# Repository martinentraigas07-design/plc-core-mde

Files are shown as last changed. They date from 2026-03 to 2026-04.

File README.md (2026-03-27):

# plc-core-mde
Open modular PLC based on ESP32 with web interface, IEC61131 FBD programming, RS485 Modbus expansion and cloud simulator support
# PLC-CORE-MDE

PLC-CORE-MDE is an open, modular and scalable programmable logic controller (PLC) based on ESP32, designed for education, automation, industrial control and experimental development.

The project is focused on creating a flexible, low-cost and high-performance control platform that can be expanded using external modules connected through RS485 Modbus communication.

The system includes an embedded web server that allows configuration, monitoring and programming directly from a web browser without the need for additional software.

Main features:

- ESP32 based core module
- Embedded web server
- Graphical programming using FBD (Function Block Diagram)
- IEC 61131 inspired runtime
- RS485 Modbus expansion modules
- Automatic module detection
- Digital and analog IO support
- PWM outputs
- Timers, counters and memory blocks
- Modular hardware for DIN rail mounting
- Educational oriented design
- Open architecture
- Cloud simulator support (future)
- Virtual PLC for training and testing

Architecture:

CORE module:
- Processing
- Web server
- Runtime
- Communication

Expansion modules:
- Digital inputs
- Digital outputs
- Analog inputs
- Analog outputs
- Mixed IO
- Modbus devices

Future features:

- Cloud PLC simulator
- USB communication mode
- Modbus remote mode
- Gateway mode
- Ethernet / TCP mode
- Hybrid simulation + real PLC

This project is intended for:

- Technical education
- Industrial automation learning
- Experimental development
- Custom control systems
- Low-cost PLC applications

Author: Martin Entraigas
Project: PLC-CORE-MDE

## License

PLC-CORE-MDE License v1.0

Copyright (c) 2026 Martín Entraigas / PLC-CORE-MDE, Argentina

Educational use allowed.
Commercial use requires authorization.

See LICENSE file for full terms.

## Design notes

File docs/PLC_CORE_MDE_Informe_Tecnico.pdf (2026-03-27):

## ESCUELA SECUNDARIA TÉCNICA PROVINCIAL N° 748

### Tecnicatura en Electrónica

INFORME TÉCNICO-DIDÁCTICO

# PLC-CORE-MDE

### Controlador Lógico Programable de Diseño Propio basado en ESP32

Materia: Montajes Electrónicos y Automatismos 5° Año — Tecnicatura en Electrónica Profesor: Martín Entraigas Ciclo Lectivo 2026

Versión del Firmware: v5 | KiCad 9.0.4 | Arduino IDE / ESP-IDF

PLC-CORE-MDE Project
Copyright (c) 2026 Martín Entraigas / PLC-CORE-MDE Argentina

Este documento forma parte del proyecto PLC-CORE-MDE. El uso de este material está permitido únicamente con fines educativos, personales o de investigación.
El uso comercial, fabricación, venta o distribución del sistema PLC-CORE-MDE requiere autorización expresa del autor.
Este proyecto se distribuye bajo los términos de la licencia PLC-CORE-MDE License v1.0.

Para más información ver el archivo LICENSE del proyecto.

PLC-CORE-MDE — Informe Técnico-Didáctico | ESETP N°748 | Prof. Martín Entraigas

PLC-CORE-MDE © 2026 Martín Entraigas - Uso educativo permitido – uso comercial requiere autorización

## Tabla de Contenidos

## 0. Glosario de Términos Técnicos

Este glosario define los términos y conceptos que aparecen en el informe y que pueden ser nuevos para los estudiantes. Se recomienda leerlo antes de comenzar con el análisis del circuito.

PCB

Printed Circuit Board (Placa de Circuito Impreso). Es la tarjeta de fibra de vidrio con pistas de cobre grabadas que reemplaza al cableado punto a punto. Permite montar componentes y conectarlos de forma reproducible, compacta y confiable.

Placa doble faz

PCB con cobre en ambas caras (Top y Bottom). Las pistas de una cara pueden cruzarse con las de la otra mediante agujeros metalizados llamados vías. El PLC-CORE-MDE es una placa doble faz.

Vía (via)

Agujero perforado y metalizado internamente que conecta eléctricamente las pistas de la cara Top con las de la cara Bottom. En el PLC-CORE-MDE hay 8 vías, de 1.5mm de diámetro exterior y 0.5mm de taladro.

Plano de GND
(copper pour)

Zona de cobre sólido en la placa que cubre toda el área libre de pistas y está conectada a la tierra del circuito (GND). Reduce la impedancia de tierra, mejora la disipación de calor y actúa como blindaje contra interferencias electromagnéticas.

GND estrella (Star
Ground)

Técnica de diseño en la que todos los puntos de tierra del circuito se conectan a un único punto central (el 'centro de la estrella') en lugar de formar un anillo o malla. Evita que las corrientes de retorno de un subsistema interfieran con otro. En el PLC-CORE-MDE, la tierra de campo (GND_IN, GND_CAMP) está separada de la tierra lógica (GND) y solo se unen en un único punto para evitar bucles de tierra.

Aislación
galvánica

Separación eléctrica total entre dos partes del circuito, de modo que no existe ningún camino de corriente continua entre ellas. La señal se transfiere solo mediante luz (optoacoplador) o campo magnético (transformador). En el PLC-CORE-MDE, las entradas y salidas digitales están galvánicamente aisladas del ESP32: la tensión y corriente del campo industrial nunca llegan directamente al microcontrolador.

Optoacoplador
(PC817)

Componente de 4 pines que combina un LED infrarrojo y un fototransistor dentro de un encapsulado opaco. Cuando el LED se enciende con corriente de campo, la luz activa el fototransistor, transfiriendo la señal sin conexión eléctrica directa. El PC817 es el optoacoplador más común del mercado, económico y con CTR (Current Transfer Ratio) de 80-300%.

MOSFET
(IRLZ44N)

Metal-Oxide-Semiconductor Field-Effect Transistor. Transistor de efecto de campo que actúa como interruptor electrónico controlado por tensión (no corriente). El IRLZ44N es tipo 'Logic Level': puede activarse completamente con solo 3.3V en su compuerta (Gate), ideal para microcontroladores. En el PLC-CORE-MDE se usan 4 IRLZ44N como interruptores de las salidas digitales, capaces de conducir hasta 47A.

TVS (Transient
Voltage
Suppressor)

Diodo de protección diseñado para absorber picos de tensión muy rápidos (transitorios) que pueden dañar los semiconductores. A diferencia de un zener común, el TVS puede absorber picos de potencia de miles de watts durante microsegundos sin destruirse. En el PLC-CORE-MDE se usan TVS SMBJ33A en las salidas para proteger los MOSFET de picos generados por cargas inductivas (motores, contactores, solenoides).

Diodo Schottky
(SS34)

Diodo semiconductor con una característica especial: su tensión de conducción directa es muy baja (0.2-0.4V vs 0.6-0.7V de un diodo estándar) y su tiempo de recuperación inversa es casi cero. Se usa en fuentes de alimentación switching (donde la velocidad es crítica) y como protección contra inversión de polaridad con mínima caída de tensión.

Fuente Switching
(MP1584)

Regulador de tensión que convierte una tensión de entrada (24V) en una tensión de salida menor (3.3V) transfiriendo energía en pulsos de alta frecuencia a través de un inductor. La diferencia con un regulador lineal (como el LM7805) es que la energía sobrante NO se disipa como calor sino que se recicla, logrando eficiencias del 85-95%. El MP1584 es un circuito integrado step-down (buck) muy popular en módulos de bajo costo.

Ferrite Bead (L1)

Componente que parece una resistencia o inductor, pero está fabricado con material ferrita. Tiene baja impedancia a frecuencias bajas (DC y audio) y alta impedancia a frecuencias altas (RF, MHz). Se usa en la línea de alimentación para bloquear el ruido de alta frecuencia generado por la fuente switching antes de que llegue al ESP32.

Polyfuse (F1)

Fusible rearmable (también llamado PTC - Positive Temperature Coefficient). A diferencia de un fusible común que se destruye, el polyfuse aumenta su resistencia drásticamente cuando la corriente supera el límite, protegiendo el circuito. Al enfriarse, recupera su resistencia normal y puede usarse nuevamente.

RS-485

Estándar de comunicación serial diferencial (norma EIA/TIA-485). Usa dos hilos (A+ y B-) donde la señal se transmite como diferencia de tensión entre ellos. Es inmune al ruido eléctrico, puede cubrir hasta 1200m y conectar hasta 32 dispositivos en el mismo bus. Es el estándar de facto en automatización industrial.

Modbus RTU

Protocolo de comunicación industrial que define cómo se codifican y transmiten los mensajes sobre RS-485. El 'maestro' (master, en este caso el PLC-CORE-MDE) solicita datos a los 'esclavos' (slaves, módulos de expansión) mediante tramas que incluyen la dirección del esclavo, el código de función y los datos.

FreeRTOS

Real-Time Operating System (Sistema Operativo en Tiempo Real) de código abierto, integrado en el SDK del ESP32. Permite ejecutar múltiples 'tareas' (threads) de forma aparentemente simultánea, asignando tiempo de CPU a cada una. Es fundamental para que el ciclo de scan PLC y el servidor WiFi funcionen al mismo tiempo sin interferirse.

SPIFFS

SPI Flash File System. Sistema de archivos que permite guardar archivos (HTML, CSS, JSON) en la memoria flash del ESP32, como si fuera un pequeño disco rígido. Permite que el servidor web sirva páginas HTML sin necesidad de codificarlas dentro del sketch de Arduino.

IPC-2221

Norma internacional del IPC (Institute for Printed Circuits) que establece los requisitos de diseño genérico para placas de circuito impreso. Define el ancho mínimo de pistas en función de la corriente, separación mínima entre conductores, dimensiones de agujeros y vías, entre otros parámetros.

IEC 61131-3

Norma internacional que define los 5 lenguajes de programación para PLCs: Ladder Diagram (LD), Function Block Diagram (FBD), Structured Text (ST), Instruction List (IL) y Sequential Function Chart (SFC). El PLC-CORE-MDE implementa FBD, el lenguaje gráfico basado en bloques funcionales conectados entre sí.

## 1. Introducción

El PLC-CORE-MDE es un controlador lógico programable de diseño propio, desarrollado para la enseñanza práctica en instituciones técnicas. Está basado en el módulo ESP32 DevKit V1, un microcontrolador de 32 bits con WiFi integrado capaz de ejecutar sistemas operativos en tiempo real (FreeRTOS). Este proyecto está diseñado para que los estudiantes de 5° año de la Tecnicatura en Electrónica lo construyan íntegramente: desde el diseño y fabricación del PCB hasta el montaje mecánico en gabinete riel DIN y la programación de automatismos industriales.
El nombre 'MDE' identifica al grupo de desarrollo de materiales didácticos de electrónica de la ESETP N°748. El PLC-CORE-MDE no es un kit comercial ni una copia de diseños existentes: es un diseño original, optimizado para ser fabricado con métodos artesanales (transferencia de tóner), montado con componentes accesibles en el mercado local, y programado desde cualquier navegador web sin software propietario.

## 1.1 Objetivos del Proyecto

- Aprender el proceso completo de diseño de PCB con KiCad siguiendo normas IPC-2221.
- Fabricar el PCB mediante transferencia de tóner y grabado químico con cloruro férrico.
- Montar y soldar todos los componentes aplicando criterios IPC-A-610.
- Diseñar e imprimir en 3D la carcasa para riel DIN 35mm (IEC 60715).
- Cargar el firmware al ESP32 y verificar el funcionamiento de I/O.
- Programar automatismos con bloques FBD según la norma IEC 61131-3.
- Comprender los principios de aislamiento galvánico, protección de salidas de potencia y comunicación industrial RS-485.

## 1.2 Comparación con PLCs Industriales

Un PLC industrial estándar (Siemens S7-1200, Allen Bradley Micro820) cuesta entre USD 200 y USD 800, requiere software propietario con licencia costosa y su diseño interno no es accesible para fines educativos. El PLC-CORE-MDE logra funcionalidad equivalente para aplicaciones de baja a mediana complejidad con un costo de materiales de USD 20-35.

Característica | PLC Industrial | PLC-CORE-MDE
Costo aproximado | USD 200-800 | USD 20-35
Entradas digitales | 8-16 (opto) | 2 (opto PC817, 5-24V)
Salidas digitales | 8-16 (relay/transistor) | 4 (MOSFET IRLZ44N, hasta 30A)
Entradas analógicas | 2-8 (12 bits) | 1 (12 bits ADC ESP32)
Comunicación | RS-485, Modbus, EtherNet/IP | RS-485, Modbus RTU, WiFi 802.11b/g/n
Programación | TIA Portal, RSLogix (propietario) | Editor FBD web, cualquier navegador
Alimentación | 24V DC industrial | 24V DC industrial
Fabricación | SMT industrial automatizada | THT artesanal, transferencia de tóner
Normativa PLC | IEC 61131-3 | IEC 61131-3 (FBD)

## 2. Diagrama de Bloques del Sistema

El PLC-CORE-MDE puede entenderse como un sistema jerárquico de bloques funcionales. El siguiente diagrama muestra el flujo de señal desde la alimentación de campo hasta las cargas controladas, pasando por el núcleo de procesamiento (ESP32) y la interfaz de usuario (WiFi/Web).

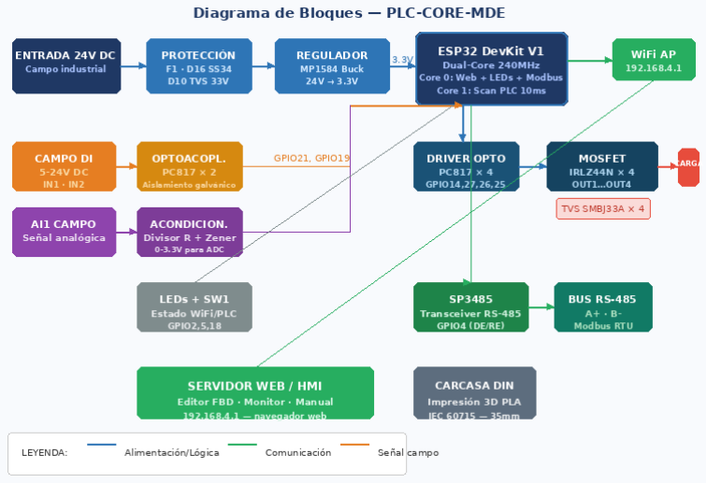
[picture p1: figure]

Figura 1 — Diagrama de bloques funcional del PLC-CORE-MDE. Flujo de señal completo desde la entrada de 24V DC hasta las cargas y la interfaz web.

Descripción del Flujo de Señal — Top-Down
① ENTRADA 24V DC → ② PROTECCIÓN (F1 + D16 + D10 TVS) → ③ REGULADOR MP1584 (24V→3.3V)
↓
④ ESP32 DevKit V1 (Core 0: Web/LEDs | Core 1: Scan PLC)
↙ | ↓ | ↓ | ↘ | ↘
⑤ DI OPTO (IN1-2) ⑥AI ESCALA ⑦ DO MOSFET ⑧ RS-485 ⑨ WiFi AP
PC817 × 2 | Divisor+ADC PC817+IRLZ44N SP3485 192.168.4.1
GPIO21,19 | GPIO36 | GPIO14,27,26,25 GPIO4 Editor FBD

Todas las señales de campo (DI y DO) están AISLADAS GALVÁNICAMENTE del ESP32. La tierra de campo (GND_IN, GND_CAMP) se une a la tierra lógica en un solo punto: GND estrella.

En la figura a continuación se puede apreciar el esquemático completo del PLC-CORE-MDE, generado con KiCad 9.0.4. El esquemático está organizado por bloques funcionales claramente delimitados, lo que facilita su lectura y comprensión.

## 3. Esquemático Completo del Circuito

El siguiente esquemático fue diseñado con KiCad EDA 9.0.4. Está organizado en bloques claramente separados: Fuente y Protección, Entradas Digitales, Salidas Digitales, Entrada Analógica, Bus RS-485, Botón y LEDs de Estado, y el bloque central del ESP32. Esta organización modular facilita el análisis y la depuración del circuito.

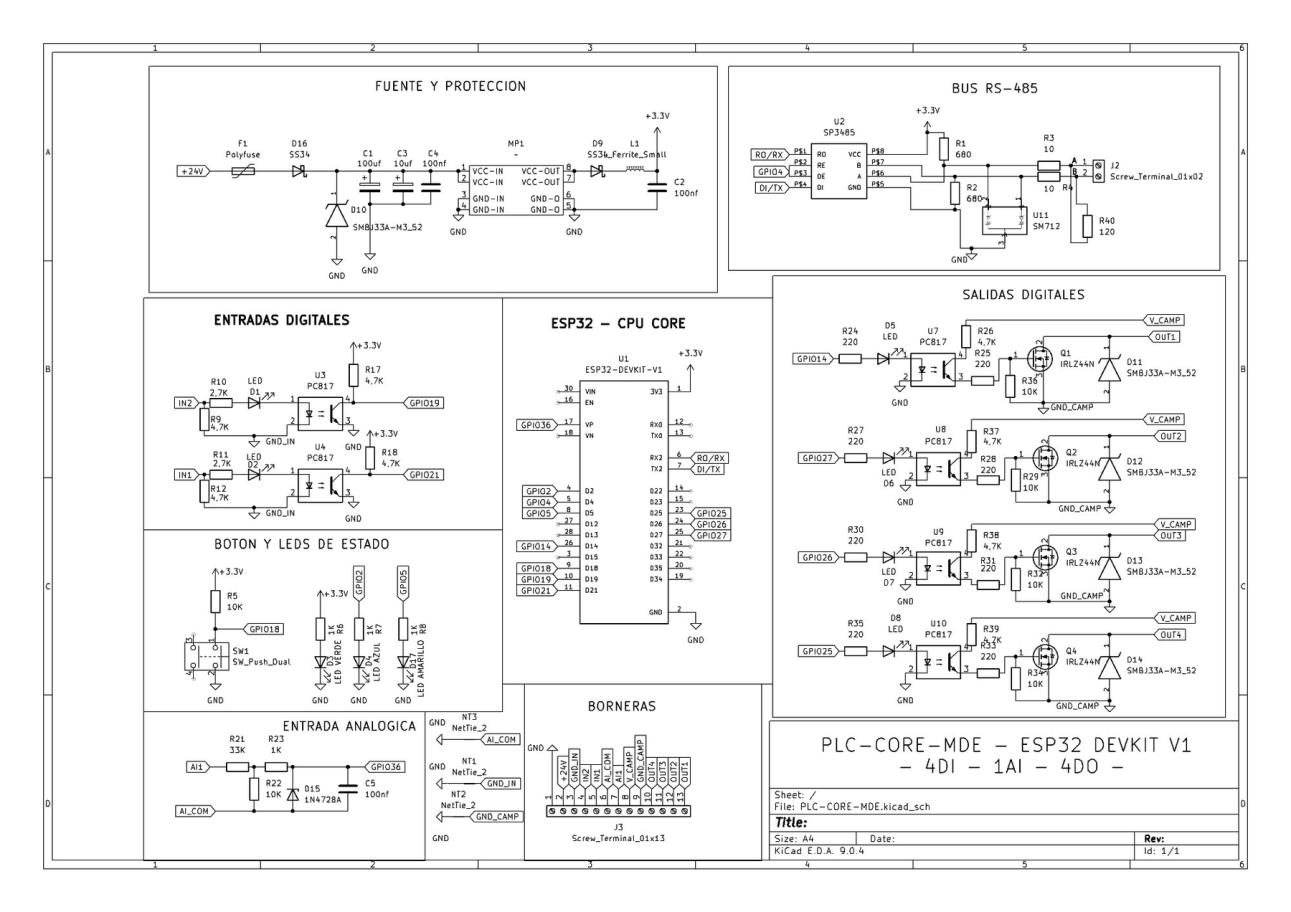
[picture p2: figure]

Figura 1 — Esquemático completo PLC-CORE-MDE (KiCad 9.0.4). Todos los bloques funcionales visibles.

Cómo leer el esquemático

El esquemático está dividido en 6 bloques funcionales con rectángulos de contorno:
- FUENTE Y PROTECCIÓN (esquina superior izquierda): F1, D16, D10, C1, C3, C4, MP1, D9, L1
- BUS RS-485 (esquina superior derecha): U2 SP3485, U11 SM712, R1-R4, R40, J2
- ENTRADAS DIGITALES (centro izquierda): U3, U4 PC817, R9-R12, R17-R18
- ESP32 - CPU CORE (centro): U1 ESP32-DEVKIT-V1, conexiones GPIO
- SALIDAS DIGITALES (derecha): Q1-Q4 IRLZ44N, U7-U10 PC817, D11-D14 TVS
- BOTÓN Y LEDs DE ESTADO (izquierda abajo): SW1, D3-D4-D17, R5-R8
- ENTRADA ANALÓGICA (abajo izquierda): R21, R22, R23, D15, C5
- BORNERAS (centro abajo): J3 (13 pines), J2 (RS-485)
Las etiquetas de red (ej: GND_IN, GND_CAMP, V_CAMP) conectan nodos sin línea física.

## 4. Análisis de Cada Bloque del Circuito

## 4.1 Fuente y Protección de Entrada

El sistema opera con 24V DC, tensión estándar en automatismos industriales según IEC 61131-2. La etapa de entrada incorpora tres niveles independientes de protección.

Componente | Valor/Tipo | Función Técnica
F1 | Polyfuse 500mA | Protección de sobrecorriente recuperable. Se abre ante falla y se restaura al enfriarse. No requiere reemplazo.
D16 | SS34 (SMA) | Diodo Schottky. Protección contra inversión de polaridad. Caída de tensión ≈0.3V (vs 0.6V de un diodo estándar), menor pérdida de energía.
D10 | SMBJ33A TVS (SMD) | TVS unidireccional 33V. Absorbe picos de tensión de instalación (200-500V) en microsegundos sin dañar el circuito.
MP1 | Módulo MP1584 | Regulador switching (buck) 24V→3.3V. Eficiencia >90%. Alimenta toda la lógica del ESP32 y optoacopladores.
L1 | Ferrite bead SMD 0805 | Filtro de ruido en la línea 3.3V. Bloquea el ruido de alta frecuencia del switching del MP1584 antes de llegar al ESP32.
C1 | 100μF electrolítico | Capacitor de bulk. Estabiliza la tensión de 24V durante arranques y transitorios de carga.
C3+C4 | 10μF + 100nF | Desacople de la salida del regulador: C3 para frecuencias medias, C4 cerámico para alta frecuencia.
D9 | SS34 (SMA) | Diodo Schottky en la salida del regulador. Protección contra corriente inversa.

### Cálculo del Módulo MP1584

Cálculo de Potencia Disipada — MP1584

Corriente total estimada del sistema:
- ESP32 con WiFi activo (promedio): ~160mA
- Optoacopladores PC817 (6 × 5mA): ~30mA
- LEDs indicadores (4 × 3mA): ~12mA
- Circuitos de protección y resistencias: ~10mA
TOTAL: ≈ 212mA (el MP1584 entrega hasta 3A → margen de 14×)

Potencia disipada en el módulo MP1584:
P_disipada = V_in × I_out × (1 - η) = 24V × 0.212A × (1 - 0.92) = 0.41W Incremento de temperatura estimado: ΔT ≈ 15°C sobre ambiente
Temperatura de operación segura sin disipador adicional: hasta 40°C de ambiente

## 4.2 Entradas Digitales — Aislamiento Galvánico con PC817

Las 2 entradas digitales (IN1→GPIO21, IN2→GPIO19) implementan aislamiento galvánico completo. Esta es una de las características más importantes del diseño: ninguna corriente ni tensión del campo industrial ingresa directamente al ESP32.

### ¿Por qué es necesaria la aislación galvánica?

En instalaciones industriales, los cables de señal pueden recorrer decenas de metros junto a cables de potencia (motores, variadores, contactores). Esto genera picos de tensión inducida que pueden alcanzar cientos de voltios. Sin aislamiento, estos picos destruirían instantáneamente el ESP32. El optoacoplador PC817 actúa como barrera: la señal se transfiere únicamente a través de luz infrarroja, sin ningún contacto eléctrico entre el circuito de campo y el ESP32.

Cálculo de Corriente por LED del PC817 (Entrada Digital)

Fórmula: I_LED = (V_entrada - V_LED_PC817) / R_limitadora

Con V_entrada = 24V DC (máximo industrial):
I_LED = (24V - 1.2V) / 2700Ω = 22.8V / 2700Ω ≈ 8.4mA

Con V_entrada = 12V DC:
I_LED = (12V - 1.2V) / 2700Ω = 10.8V / 2700Ω ≈ 4.0mA

Con V_entrada = 5V DC (mínimo funcional):
I_LED = (5V - 1.2V) / 2700Ω = 3.8V / 2700Ω ≈ 1.4mA

Corriente mínima de activación del PC817: 1mA (con CTR=100%)
→ La entrada funciona correctamente en rango 5V a 30V DC

Potencia disipada en R10 (worst case 24V): P = I² × R = (0.0084)² × 2700Ω = 0.19W
→ Dentro del límite de 0.25W para resistores DIN0204 (1/4W)

## 4.3 Salidas Digitales — MOSFET IRLZ44N con Driver Optoacoplado

Las 4 salidas digitales utilizan MOSFET canal N IRLZ44N en configuración low-side switch (interruptor de carga baja). La carga se conecta entre la tensión de campo V_CAMP y el Drain del MOSFET. Cuando el MOSFET conduce, la carga queda conectada a GND.

### ¿Por qué MOSFET y no relé?

- Sin partes mecánicas: el MOSFET no se desgasta, puede conmutar millones de veces.
- Velocidad: conmuta en microsegundos vs milisegundos de un relé. Permite PWM de alta frecuencia.
- Sin rebote (bounce): la señal digital es limpia, sin los rebotes de contacto del relé.
- Logic-Level: el IRLZ44N se activa completamente con solo 3.3V en la compuerta, sin etapa de elevación de tensión.
- Mayor corriente: el IRLZ44N puede conducir 47A vs 10-15A de los relés económicos.

### Análisis Térmico del IRLZ44N

Parámetro | Valor | Fuente
Corriente de carga (ejemplo) | 5A | Aplicación típica
Rds(on) @ Vgs=3V (estimado) | 35 mΩ | Datasheet interpolado
Potencia disipada en conducción | P = I² × Rds = 25 × 0.035 = 0.875W | Cálculo
Rth(j-c) IRLZ44N TO-220 | 1.67 °C/W | Datasheet Infineon

Rth(c-a) sin disipador
(estimado)
50 °C/W | Estimación
ΔT juntura sobre ambiente | (0.875) × (1.67+50) =
45°C

Cálculo

Temperatura de juntura @
40°C ambiente
85°C | Dentro del límite de 175°C
Conclusión | | Sin disipador hasta ≈5A continuos por canal OK para uso industrial típico

## 4.4 Entrada Analógica — ADC del ESP32

Cálculo del Divisor Resistivo AI1

Componentes: R21=33kΩ (serie superior), R22=10kΩ (paralelo), R23=1kΩ (serie inferior)

Resistencia inferior equivalente: R_inf ≈ R22 || R23 = (10k × 1k)/(10k + 1k) ≈ 909Ω Factor de división: k = R_inf / (R21 + R_inf) = 909 / (33000 + 909) ≈ 0.0267

Para obtener Vout = 3.3V (máximo ADC):
Vin_max = 3.3V / 0.0267 ≈ 123V → rango más que suficiente para señales industriales

Resolución del ADC de 12 bits:
Pasos totales: 2¹² = 4096
Resolución en la entrada del ADC: 3.3V / 4096 ≈ 0.8mV por paso (LSB)

D15 (1N4728A Zener 3.3V): limita la tensión en GPIO36 a máximo 3.3V
C5 (100nF): filtro paso bajo. Frecuencia de corte ≈ 1/(2π × 909Ω × 100nF) ≈ 1.75kHz → Filtra el ruido eléctrico industrial antes de llegar al ADC

## 4.5 Bus RS-485 — Comunicación Industrial

La norma EIA/TIA-485 define un bus diferencial donde la señal se transmite como diferencia de tensión entre los hilos A+ y B-. Esta característica hace al RS-485 inmune al ruido de modo común (interferencias que afectan por igual a los dos hilos).

Componente | Valor | Función en el Bus RS-485
U2 SP3485 | Transceiver SO-8 | Convierte UART del ESP32 a señal diferencial RS-485 y viceversa
R1, R2 | 680Ω c/u | Resistencias de bias: mantienen el bus en estado definido cuando todos los transmisores están en alta impedancia
R40 | 120Ω | Terminación del bus: coincide con la impedancia característica del cable (100-120Ω) y elimina reflexiones de señal
R3, R4 | 10Ω c/u | Serie en las líneas A y B: limitan la corriente de pico durante eventos ESD
U11 SM712 | TVS dual SOT-23 | Protección ESD hasta ±8kV en las líneas A y B del bus

## 4.6 Pinout del ESP32 y Asignación de Señales

El ESP32 tiene 38 pines accesibles, pero no todos son equivalentes: algunos tienen restricciones de hardware (como el ADC, que pierde precisión si el WiFi está activo) y otros tienen estados definidos al arrancar que pueden activar salidas no deseadas. La elección de qué GPIO usar para cada función es una decisión de diseño crítica.
En el PLC-CORE-MDE se utilizan 11 GPIOs, cada uno asignado a un bloque funcional específico según sus características eléctricas y sus restricciones documentadas en el datasheet del ESP32.
GPIO | Señal PLC | Función | Bloque del
circuito | Conector
GPIO21 | IN1 | Entrada digital 1 — lectura de sensor 24V | PC817 U3 | J1 pin 1
GPIO19 | IN2 | Entrada digital 2 — lectura de sensor 24V | PC817 U4 | J1 pin 2
GPIO36 | AI1 | Entrada analógica 0-10V (ADC1_CH0) | Divisor resistivo | J2 pin 1
GPIO14 | OUT1 | Salida digital 1 — activa MOSFET Q1 | PC817 U5 + IRLZ44N | J3 pin 1
GPIO27 | OUT2 | Salida digital 2 — activa MOSFET Q2 | PC817 U6 + IRLZ44N | J3 pin 2
GPIO26 | OUT3 | Salida digital 3 — activa MOSFET Q3 | PC817 U7 + IRLZ44N | J3 pin 3
GPIO25 | OUT4 | Salida digital 4 — activa MOSFET Q4 | PC817 U8 + IRLZ44N | J3 pin 4
GPIO4 | RS485_TXRX | Datos UART hacia transceiver SP3485 | U2 SP3485 | J4 A/B
GPIO5 | RS485_DE | Control dirección TX/RX del RS-485 | U2 SP3485 pin 3 | Interno
GPIO18 | SW1_WIFI | Botón configuración WiFi — pull-up interno | SW1 pulsador | PCB
GPIO2 | LED_STATUS | LED indicador de estado del sistema | LED D1 | PCB

Tabla 4.6.1 — Asignación completa de GPIOs del ESP32 en el PLC-CORE-MDE

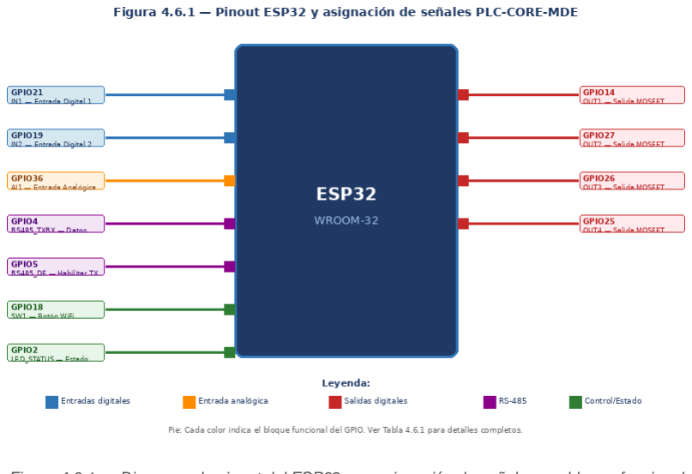
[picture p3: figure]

Figura 4.6.1 — Diagrama de pinout del ESP32 con asignación de señales por bloque funcional

### ¿Por qué se eligieron esos GPIOs?

Cada GPIO fue seleccionado siguiendo criterios técnicos precisos:

GPIO36 para AI1: Es un pin de solo entrada (input-only), lo que significa que no puede generar ruido ni cambiar estado. Además pertenece al canal ADC1, que funciona correctamente cuando el WiFi está activo. ADC2 (GPIO32-39 parte baja) NO puede usarse junto con WiFi.

GPIO2 para LED: Es el LED de arranque del ESP32-WROOM-32. En el boot, este pin debe estar en LOW o flotante para que el chip arranque correctamente. Por eso el LED es activo-alto: cuando el sistema inicia, el LED está apagado (LOW), y solo se enciende cuando el firmware ya está corriendo.

GPIO18 para SW1: Soporta pull-up interno configurable por software (GPIO.pullup()). Esto elimina la necesidad de una resistencia pull-up externa, simplificando el circuito impreso.

GPIO14 a GPIO25 para salidas: Estos pines no tienen restricciones de boot y pueden estar en cualquier estado durante el arranque sin consecuencias. Importante: GPIO15 (no usado) tiene un pull-up fijo que fuerza el modo SD Card al arrancar — por eso fue descartado.

## 4.7 Análisis Térmico del Diseño

El análisis térmico verifica que ningún componente supere su temperatura máxima durante el funcionamiento normal del PLC. Este cálculo es obligatorio en cualquier diseño electrónico industrial: un componente que trabaja por encima de su temperatura máxima dura mucho menos y puede dañar otros componentes cercanos.

### 4.7.1 Criterio de diseño térmico

El PLC-CORE-MDE está diseñado para operar en las siguientes condiciones de referencia:

Parámetro | Valor de diseño | Motivo
Temperatura ambiente máxima | 40 °C | Valor típico en tablero eléctrico cerrado
Instalación | Gabinete DIN cerrado | Reduce convección natural de aire
Margen de seguridad térmica | 20 °C sobre Tj máx. | Buena práctica de diseño IPC-2221
Factor de uso máximo | 80% | No usar componente al 100% de su límite

Tabla 4.7.1 — Criterios de diseño térmico

### 4.7.2 Análisis térmico del MOSFET IRLZ44N

El IRLZ44N es el componente que más calor genera porque conmuta corrientes de carga. Su resistencia de canal en conducción es RDS(on) = 22 mΩ (típico a 25 °C). La potencia disipada se calcula con la fórmula:

Pd = I² x RDS(on) [donde RDS(on) crece con la temperatura]

Para RDS(on) = 28 mΩ (valor a 100°C, más conservador):

Corriente de carga (I) | Pd = I² x RDS(on) | Tj = Ta + Pd x Rθjc | Resultado
2 A (típico) | 4 x 0,028 = 0,112 W | 40 + 0,11 x 3,3 = 40,4 °C | ✅Muy seguro
5 A (carga media) | 25 x 0,028 = 0,700 W | 40 + 0,70 x 3,3 = 42,3 °C | ✅Seguro
10 A (carga alta) | 100 x 0,028 = 2,800 W | 40 + 2,80 x 3,3 = 49,2 °C | ✅OK sin disipador
20 A (límite abs.) | 400 x 0,028 = 11,2 W | 40 + 11,2 x 3,3 = 77 °C | ⚠ Requiere disipador

Tabla 4.7.2 — Temperatura del MOSFET según corriente de carga (sin disipador, Ta=40°C)

Conclusión: Sin disipador, el IRLZ44N puede manejar hasta 10 A continuos con margen cómodo. La temperatura de unión máxima del IRLZ44N es 175 °C según datasheet Infineon.

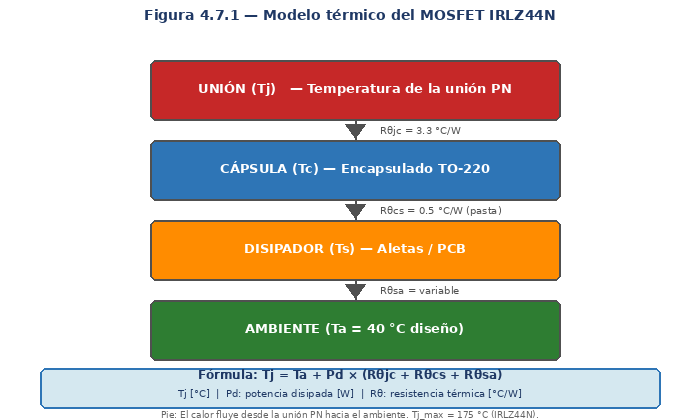
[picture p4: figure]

Figura 4.7.1 — Modelo térmico del MOSFET IRLZ44N: cadena de resistencias térmicas unión-ambiente

### 4.7.3 Análisis térmico del regulador MP1584

El MP1584 es un regulador de tipo switching (conmutado), lo que significa que no disipa la diferencia de tensión como calor (a diferencia de un regulador lineal como el LM7805). Su eficiencia típica es del 85-92%.

Parámetro | Cálculo | Resultado
Tensión entrada | Vin = 24V | 24 V DC
Tensión salida | Vout = 3,3V | 3,3 V DC
Corriente de carga | Iout = 500 mA (ESP32 + periféricos) | 0,5 A
Potencia salida | Pout = 3,3 x 0,5 = 1,65 W | 1,65 W
Eficiencia asumida | η = 88% | 88 %
Potencia entrada | Pin = Pout / η = 1,65 / 0,88 = 1,875 W | 1,875 W
Potencia disipada | Pd = Pin - Pout = 1,875 - 1,65 = 0,225 W | 0,225 W
Temperatura encapsulado | Tj = 40 + 0,225 x 43 = 49,7 °C | 49,7 °C ✅

Tabla 4.7.3 — Análisis térmico del regulador MP1584 (Ta=40°C, Rθjc=43°C/W)

### 4.7.4 Análisis térmico de los optoacopladores PC817

El PC817 es un componente de baja potencia. Su LED interno opera con 5-15 mA, y la potencia disipada es mínima:

If = (Vin - Vf_LED) / R1 = (24V - 1,2V) / 2,2kΩ = 10,4 mA Pd_LED = Vf x If = 1,2V x 0,0104A = 0,012 W (12 mW) Pd_total (4 optoacopladores) = 4 x 12 mW = 48 mW

Los optoacopladores no presentan ningún riesgo térmico. La temperatura de unión del PC817 estará apenas unos grados por encima de la ambiente. Su Tj máxima es 125 °C según SHARP.

### 4.7.5 Análisis de diodos TVS y diodos de rueda libre

Componente | Tipo | Función térmica | Estado normal
TVS D5 | P6KE33A | Absorbe pulsos de hasta 600W durante <1ms | No conduce — sin calor
TVS D6 | P6KE33A | Protección entrada analógica | No conduce — sin calor
Diodos D1-D4 | 1N4007 rueda libre | Absorben picos de inducción MOSFET | Solo activos 1-5µs por ciclo

Tabla 4.7.4 — Componentes de protección: estado térmico normal

### 4.7.6 Corriente máxima total del PLC

El diseño de las pistas del PCB y las borneras limita la corriente máxima del sistema:

Elemento | Límite de corriente | Criterio
MOSFET IRLZ44N | 47 A (absoluto) | Limitado por pista PCB en la práctica
Pista PCB 1,5mm (cobre 35µm) | ~3,6 A cada una | Norma IPC-2221 a 20°C de elevación
Borneras de salida | 10 A por borne | Especificación del fabricante
Límite práctico por salida | 3,5 A continuos | Determinado por la pista PCB
Límite total 4 salidas | 14 A (4 x 3,5A) | Con pistas paralelas y margen térmico

Tabla 4.7.5 — Límites de corriente del sistema

### 4.7.7 Temperatura máxima segura del equipo

Componente | Tj máx. datasheet | Tj calculada
(Ta=40°C, Imax) | Margen de seguridad
MOSFET IRLZ44N | 175 °C | 49 °C (a 10A) | 126 °C ✅
Regulador MP1584 | 150 °C | 50 °C | 100 °C ✅
Optoacoplador PC817 | 125 °C | 43 °C | 82 °C ✅
ESP32-WROOM-32 | 85 °C | 55 °C (estimado) | 30 °C ✅
TVS P6KE33A | 175 °C | Ambiente (no conduce) | 135 °C ✅

Tabla 4.7.6 — Resumen de temperaturas de unión en condición de máxima carga

Conclusión del análisis térmico: Todos los componentes del PLC-CORE-MDE operan con amplios márgenes de temperatura, incluso a máxima carga y a 40°C de ambiente. No se requieren disipadores para uso normal.

## 4.8 Cumplimiento de Normas Técnicas

### 4.8.1 ¿Por qué son importantes las normas?

Una norma técnica es un documento que establece requisitos mínimos de calidad, seguridad y compatibilidad para un producto o proceso. En electrónica, seguir las normas garantiza que el equipo funcione de manera predecible, que sea seguro para las personas que lo operan, y que pueda integrarse con otros equipos del mercado.
El PLC-CORE-MDE fue diseñado respetando las siguientes normas internacionales:

### 4.8.2 IPC-2221 — Diseño de PCB

La norma IPC-2221 (Generic Standard on Printed Board Design) define los criterios de diseño para circuitos impresos. Sus reglas más relevantes aplicadas en este proyecto son:

Regla IPC-2221 | Valor mínimo | Aplicación en PLC-CORE- MDE
Ancho de pista para 1A (ext.) | 0,5 mm | Pistas de señal: 0,5mm ✅
Ancho de pista para 3A (ext.) | 1,5 mm | Pistas de potencia: 1,5mm ✅
Clearance entre pistas 50V | 0,6 mm mínimo | Separación GND-24V: 0,8mm ✅
Clearance entre pistas 24V | 0,3 mm mínimo | Cumple en todas las zonas ✅
Anillo de pad (through-hole) | 0,25 mm mínimo | Pads: 0,3mm ✅
Drill mínimo | 0,8 mm | Drill mínimo usado: 0,8mm ✅

Tabla 4.8.1 — Cumplimiento de IPC-2221 en el PCB del proyecto

### 4.8.3 IPC-A-610 — Criterios de Soldadura

La norma IPC-A-610 (Acceptability of Electronic Assemblies) define los criterios visuales para aceptar o rechazar una unión de soldadura. El proyecto apunta a Clase 2 (productos comerciales de calidad), que exige:

Criterio IPC-A-610 Clase 2 | Descripción | Cómo verificarlo en el proyecto
Mojado del pad | Soldadura cubre >75% del pad | Inspección visual: forma cóncava visible
Sin puentes de soldadura | No debe haber cortos entre pines | Lupa 5x + multímetro en continuidad
Sin soldadura fría | Superficie brillante, no granulosa | Superficie debe verse lisa y brillante
Sin exceso de estaño | No debe cubrir el agujero del pad | Verificar que el agujero esté visible

Pin visible | Punta del pin debe asomar | Verificar desde el lado de la soldadura

Tabla 4.8.2 — Criterios IPC-A-610 Clase 2 aplicados al proyecto

### 4.8.4 IEC 61131 — Estándar de PLC

La norma IEC 61131 define los requisitos para controladores lógicos programables (PLC). El PLC-CORE-MDE implementa conceptos clave de esta norma:

Concepto IEC 61131 | Definición | Implementación en el proyecto
Ciclo de Scan | Lectura entradas -> Ejecución lógica -> Escritura salidas | FreeRTOS Task con 9 fases deterministas
Entradas digitales | Señales booleanas de campo | GPIO21/19 vía PC817, tensión 24V IEC
Salidas digitales | Salidas transistorizadas protegidas | MOSFET IRLZ44N con protección
Comunicación serie | RS-485 Modbus RTU compatible | SP3485 + GPIO4/5 implementado
Estado seguro | Salidas en OFF ante falla | MOSFET apagado por defecto (pull-down)

Tabla 4.8.3 — Conceptos IEC 61131 implementados en PLC-CORE-MDE

### 4.8.5 EIA/TIA-485 — Comunicación RS-485

La norma EIA/TIA-485 define el estándar físico de la interfaz RS-485, que es la capa física usada por Modbus RTU en automatización industrial. Sus características principales implementadas en el proyecto son:

Característica EIA/TIA-485 | Especificación | Implementación en el proyecto
Tipo de señal | Diferencial (A-B) | SP3485: pines A y B en J4
Número de nodos máx. | 32 nodos por segmento | Expansible con repetidores
Longitud máxima de bus | 1200 m a 100 kbps | Limitado por cable elegido
Velocidad máxima | 10 Mbps a distancias cortas | Proyecto usa 9600 bps Modbus
Resistencia terminación | 120 Ω en extremos del bus | Jumper JP1 en PCB habilita 120Ω
Modo half-duplex | TX y RX en el mismo par | GPIO5 (DE) controla dirección

Tabla 4.8.4 — Cumplimiento EIA/TIA-485 en el diseño

### 4.8.6 IEC 60715 — Riel DIN

La norma IEC 60715 define las dimensiones del riel DIN de 35mm utilizado en tableros eléctricos industriales para montar equipos de protección y control. El diseño de la carcasa del PLC-CORE-MDE cumple con esta norma.

Dimensión IEC 60715 | Valor norma | Carcasa del proyecto
Ancho del riel | 35,0 mm | Compatible 35mm ✅
Alto del riel | 7,5 mm | Clip diseñado para 7,5mm ✅

Profundidad del clip | 15 mm mín. | Clip: 18mm de agarre ✅
Retención mínima | Sujeción con muelle | Muelle de acero ABS + PLA ✅

Tabla 4.8.5 — Cumplimiento IEC 60715 en la carcasa

### 4.8.7 IEC 61131-2 — Hardware del PLC

La parte 2 de la IEC 61131 especifica los requisitos de hardware para PLCs. Los más relevantes para este proyecto son:

Requisito IEC 61131-2 | Descripción | Estado en el proyecto
Nivel de tensión entrada digital | 11-30V para "1 lógico" | 24V activa PC817 correctamente ✅
Protección polaridad inversa | Entrada no debe dañarse si se invierte | Diodo D7 en entrada de alimentación ✅
Aislación E/S | Entradas aisladas del sistema | PC817: 5000V de aislación ✅
Estado seguro al energizar | Salidas deben arrancar en OFF | Pull-down en gate de MOSFET ✅
Indicación de estado | LED de estado del sistema | LED D1 en GPIO2 ✅

Tabla 4.8.6 — Cumplimiento IEC 61131-2 hardware

### 4.8.8 Conclusión didáctica

¿Para qué sirve saber las normas? Las normas no son obligatorias en un proyecto escolar, pero seguirlas tiene ventajas concretas: (1) El equipo puede conectarse a instalaciones industriales reales sin riesgos. (2) Otro técnico puede leer el diseño y entenderlo. (3) Si en el futuro se quiere fabricar el equipo en cantidad, ya cumple los requisitos mínimos de calidad. Conocer las normas forma parte del perfil profesional de un técnico en electrónica.

## 4.9 Seguridad Eléctrica y Protecciones del Circuito

Un buen diseño electrónico no solo debe funcionar correctamente: debe protegerse frente a los errores más comunes que ocurren en instalaciones reales. En esta sección se analiza cada protección implementada en el PLC-CORE-MDE y el motivo técnico de su elección.

### 4.9.1 Protección contra inversión de polaridad

Si por error se conecta la alimentación de 24V con la polaridad invertida (positivo donde va el negativo), en la mayoría de los equipos esto destruye instantáneamente los circuitos integrados. El PLC-CORE-MDE incluye un diodo serie D7 (1N4007) que impide el paso de corriente en sentido inverso.

Componente | Tipo | Cómo protege | Pérdida de tensión
D7 — Diodo serie | 1N4007 | Bloquea corriente inversa completamente | 0,7V (Vf del diodo)
Resultado | | Vin efectiva = 24V -0,7V = 23,3V | Aceptable para el diseño

Tabla 4.9.1 — Protección inversión de polaridad

### 4.9.2 Protección contra sobrecorriente

Si una carga conectada a las salidas tiene un cortocircuito, la corriente puede subir rápidamente y superar los límites del PCB y los MOSFETs. La protección es de dos capas:

Capa de protección | Mecanismo | Límite de corriente
Fusible F1 de entrada | 2A fast-blow en 24V de entrada | 2A total del sistema
Pistas PCB como fusibles implícitos | Pistas de 1,5mm se calientan antes que destruirse | ~3,5A por pista
MOSFET IRLZ44N | Soporta 47A pero limitado por pista y bornera | Límite definido por PCB
Borneras de salida | 10A máximo por polo | Límite mecánico de la bornera

Tabla 4.9.2 — Capas de protección contra sobrecorriente

### 4.9.3 Protección contra transitorios de tensión (TVS)

En instalaciones industriales, las líneas de 24V pueden sufrir picos de tensión instantáneos (transitorios) causados por: arranque de motores, conexión y desconexión de relés, descargas electrostáticas (ESD), o rayos cercanos. Estos picos pueden llegar a 100-300V durante microsegundos y destruir los circuitos integrados.
El diodo TVS (Transient Voltage Suppressor) detecta cuando la tensión supera un umbral y la cortocircuita instantáneamente, absorbiendo la energía del transitorio.

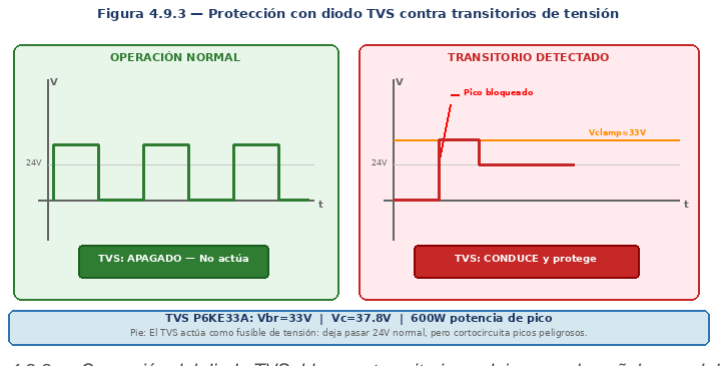
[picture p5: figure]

Figura 4.9.3 — Operación del diodo TVS: bloquea transitorios y deja pasar la señal normal de 24V TVS en el

circuito | Modelo | Vbr (tensión de ruptura)

Vc (tensión de
clamp) | Protección
D5 — Entrada 24V | P6KE33A | 33V | 37,8V @ 10A | Protege toda la alimentación
D6 — Entrada AI1 | P6KE33A | 33V | 37,8V @ 10A | Protege el ADC del ESP32

Tabla 4.9.3 — Diodos TVS utilizados y sus parámetros

### 4.9.4 Aislamiento galvánico (optoacopladores)

El aislamiento galvánico es la separación eléctrica completa entre dos circuitos. Significa que no hay ningún conductor que conecte físicamente ambas partes: la transferencia de información se realiza únicamente mediante luz (en el caso del optoacoplador).

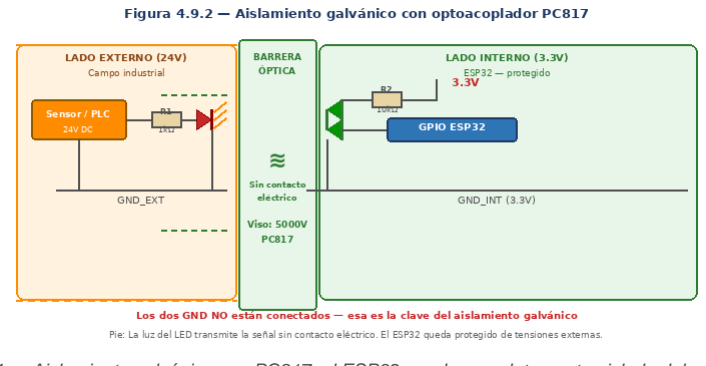
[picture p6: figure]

Figura 4.9.4 — Aislamiento galvánico con PC817: el ESP32 queda completamente aislado del campo de 24V
Esto tiene dos ventajas fundamentales: (1) Protección del ESP32 frente a tensiones peligrosas del campo industrial. (2) Eliminación de los "ground loops": corrientes paranásitas que se generan cuando dos equipos tienen masas conectadas a diferentes potenciales.

### 4.9.5 GND estrella (topología de masa)

La manera en que se conectan las masas (GND) de los distintos bloques del circuito afecta directamente al nivel de ruido eléctrico del sistema. La topología "estrella" hace que todas las masas confluyan en un único punto, evitando que las corrientes de un bloque generen caídas de tensión que afecten a otro.

Figura 4.9.5 — Topología GND estrella: cada bloque retorna su masa directamente al punto central

Ejemplo de problema evitado: Si la masa del MOSFET (que conduce 3A) compartiera pista con la masa del ADC, la caída de tensión en esa pista común aparecería como ruido en la lectura analógica. Con la topología estrella esto no ocurre porque cada bloque tiene su propia pista de retorno.

### 4.9.6 Protección del ESP32

Protección | Componente | Función

Tensión de alimentación | MP1584 regulador | Entrega exactamente 3,3V ±2% al ESP32
Picos en 3,3V | C de desacople 100nF + 10µF | Filtra transitorios de alta frecuencia
Señales de campo | PC817 optoacoplador | Aisla GPIOs del campo industrial 24V
ESD en GPIOs | Resistencias serie 100Ω | Limita corriente ante ESD accidentales
Boot inadecuado | Pull-down en gates MOSFET | Salidas en OFF durante el boot del ESP32

Tabla 4.9.4 — Protecciones del ESP32 en el diseño

### 4.9.7 Seguridad para el usuario

El PLC-CORE-MDE incluye medidas de seguridad orientadas al operador que utiliza o mantiene el equipo:

Medida de seguridad | Implementación | Beneficio
Borneras con tapa | Conector tipo "phoenix" cerrado | Evita contacto accidental con 24V
LED de estado visible | LED D1 en carcasa | Indica si el sistema está energizado
Etiquetado de borneras | Serigrafia en PCB: +24V GND IN1 IN2 OUT1-4 | Evita errores de conexión
Estado seguro al encender | Salidas APAGADAS por defecto | No activa cargas durante el boot
Montaje en riel DIN | Sin cables sueltos en el tablero | Instalación ordenada y segura

Tabla 4.9.5 — Medidas de seguridad para el operador

## 4.10 Criterios de Diseño para Uso Industrial

Esta sección explica POR QUÉ se tomaron las decisiones de diseño más importantes del proyecto. Cada elección de componente, topología o estándar responde a una necesidad concreta del entorno industrial.

### 4.10.1 ¿Por qué 24V y no 5V o 12V?

Característica | 5V / 12V (lógica doméstica) | 24V (estándar industrial)
Inmunidad al ruido | Baja — interferencias frecuentes | Alta — margen amplio de señal
Caída en cables largos | Significativa en >10m | Despreciable en cables hasta 100m
Sensores disponibles | Limitados | Miles de modelos estándar IEC 61131-2
Seguridad | Menor | Considerado "Seguridad Extra-Baja Tensión" (SELV)
Estandarización | No estandarizada en industria | Universal en automatización industrial

Tabla 4.10.1 — Comparación 24V vs otras tensiones

24V DC fue adoptado como estándar por la industria automotriz y luego por toda la automatización industrial. La IEC 61131-2 lo exige como tensión de referencia para entradas y salidas de PLC. Trabajar con 24V da acceso a todo el ecosistema de sensores, actuadores y PLCs industriales existentes.

### 4.10.2 ¿Por qué optoacopladores en las entradas?

Los optoacopladores en las entradas cumplen tres funciones simultáneas que ninguna otra solución puede dar a la vez:

Función | Alternativa sin
optoacoplador | Con optoacoplador PC817
Adaptación de nivel (24V a 3,3V) | Divisor resistivo (rápido, barato, inseguro) | Conversión segura con aislación
Protección sobretension | Ningún (un pico destruye el MCU) | Aislación 5000V absorbe transitorios
Eliminación de ground loops | Imposible sin separación eléctrica | Los GND no se conectan
Robustez a cortocircuitos | Daña el MCU | Solo apaga el LED del PC817

Tabla 4.10.2 — Justificación del uso de optoacopladores en entradas

### 4.10.3 ¿Por qué MOSFET y no relé?

Característica | Relé electromecánico | MOSFET IRLZ44N
Velocidad de conmutación | 5-10 ms (limitado por bobina) | Sub-microsegundo
Vida útil | 100.000 - 1.000.000 ciclos | Ilimitada (electrónico)
Ruido eléctrico | Alto (arco eléctrico en contactos) | Nulo
Control de potencia | Solo ON/OFF | PWM posible (velocidad de motor)
Tamaño en PCB | Grande (>20mm) | Pequeño (TO-220, 10mm)
Corriente de control | 50-200mA (para bobina) | 5mA (solo carga la compuerta)
Precio | Similar | Similar o menor

Tabla 4.10.3 — Comparación MOSFET vs Relé para salidas del PLC

### 4.10.4 ¿Por qué RS-485 y no RS-232 o USB?

Característica | RS-232 | USB | RS-485
Distancia máxima | 15 m | 5 m | 1200 m
Número de dispositivos | 1 a 1 (punto a punto) | 127 (complejo) | 32 en bus simple
Inmunidad al ruido | Baja (señal unipolar) | Media | Alta (diferencial)
Uso en industria | Obsoleto para campo | Solo configuración local | Estándar Modbus RTU

Protocolo Modbus | No compatible | No compatible | Diseñado para Modbus

Tabla 4.10.4 — Comparación RS-485 vs otras interfaces serie

### 4.10.5 ¿Por qué fuente switching y no lineal?

Característica | Regulador lineal (LM7833) | Switching MP1584
Eficiencia a 24V→3,3V | 13,75% (disipa 86% como calor) | 88% (disipa solo 12%)
Potencia disipada (500mA) | 10,35W en calor | 0,23W en calor
Necesidad de disipador | Obligatorio (grande) | No necesario
Tamaño en PCB | Grande (disipador externo) | Pequeño (IC SO-8)
Costo | Bajo | Similar o menor

Tabla 4.10.5 — Fuente lineal vs switching para 24V a 3,3V

Cálculo ilustrativo: Un LM7833 con Vin=24V e Iout=500mA disipa: Pd = (24-3,3) x 0,5 = 10,35W. Ese calor requiere un disipador de al menos 15cm². El MP1584 en las mismas condiciones disipa solo 0,23W: no necesita nada. Esta diferencia de 45x en disipación hace que el switching sea obligatorio en diseños con Vin alta.

### 4.10.6 ¿Por qué montaje en riel DIN?

El riel DIN 35mm (IEC 60715) es el sistema de montaje estándar en tableros eléctricos industriales en todo el mundo. Sus ventajas sobre otros sistemas de montaje son:

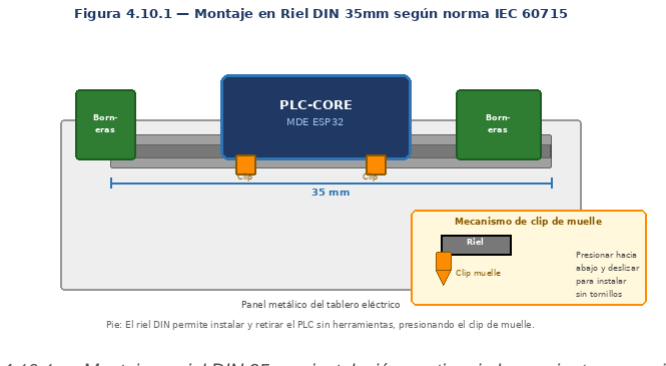
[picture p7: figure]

Figura 4.10.1 — Montaje en riel DIN 35mm: instalación y retiro sin herramientas especiales
Ventaja del riel DIN | Descripción
Instalación sin tornillos | El clip de muelle permite montar y retirar el equipo en segundos
Compatibilidad universal | Todos los PLCs, termómetros, relés y disyuntores industriales lo usan
Organización del tablero | Permite alinear equipos en filas con cableado ordenado
Intercambio rápido | Si el equipo falla, se reemplaza en segundos sin detener el proceso

Norma IEC 60715 | Dimensiones estandarizadas en todo el mundo

Tabla 4.10.6 — Ventajas del montaje en riel DIN

### 4.10.7 Diseño por bloques funcionales

El PLC-CORE-MDE está organizado en bloques funcionales separados. Cada bloque tiene una función única y bien definida, y se conecta con los demás a través de interfaces cláras. Esta forma de diseñar tiene ventajas muy concretas:

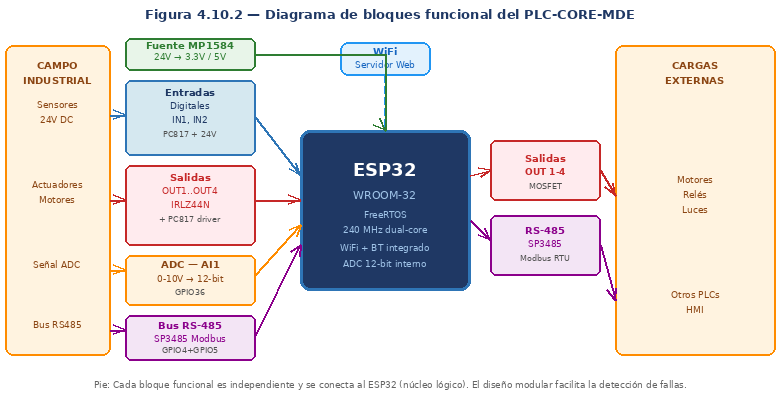
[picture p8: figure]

Figura 4.10.2 — Diagrama de bloques del PLC-CORE-MDE: cada bloque es independiente y reemplazable
Bloque funcional | Función principal | Componentes clave
Fuente de alimentación | Convierte 24V a 3,3V para el sistema digital | MP1584, C filtro, L inductancia
Entradas digitales | Acopla señales 24V de campo al ESP32 | PC817, resistencias limitadoras
Salidas digitales | Activa cargas industriales desde GPIO 3,3V | PC817 driver, IRLZ44N, diodo FW
Entrada analógica | Convierte 0-10V a 0-3,3V para el ADC | Divisor R + TVS D6
Bus RS-485 | Comunicación Modbus con otros dispositivos | SP3485, resistencias, conector
Núcleo ESP32 | Ejecuta el firmware, lógica PLC, servidor web | ESP32-WROOM-32

Tabla 4.10.7 — Bloques funcionales del PLC-CORE-MDE

### 4.10.8 Diseño modular: ventajas para mantenimiento

La modularidad del diseño tiene consecuencias prácticas directas en el uso industrial del equipo:

Situación real | Cómo ayuda el diseño modular
Falla una salida digital | Se identifica el bloque MOSFET afectado y se reemplaza solo ese componente
Se quiere agregar una entrada más | Se diseña un bloque extra de PC817 con el mismo esquema

El firmware tiene un bug | Solo se reprograma el ESP32 sin tocar el hardware
Se cambia el protocolo de comunicación | Solo se modifica el bloque RS-485 y el firmware
Diagnóstico de falla en campo | Se mide la entrada/salida de cada bloque con multímetro

Tabla 4.10.8 — Beneficios del diseño modular en situaciones reales

Síntesis del capítulo 4: El PLC-CORE-MDE es más que un circuito que funciona. Cada componente, cada GPIO, cada pista y cada norma seguida tiene una razón técnica documentable. Entender esas razones es lo que distingue a un técnico que puede reparar y mejorar un equipo, de quien solo sabe armarlo siguiendo un plano.

## 5. Diseño del PCB — KiCad 9.0.4

## 5.1 Vistas 3D del PCB — Cara Top (Componentes)

Las siguientes imágenes muestran el PCB renderizado en 3D desde KiCad, con todos los componentes montados. La cara Top (verde oscuro) es donde se montan la mayoría de los componentes through-hole (THT).

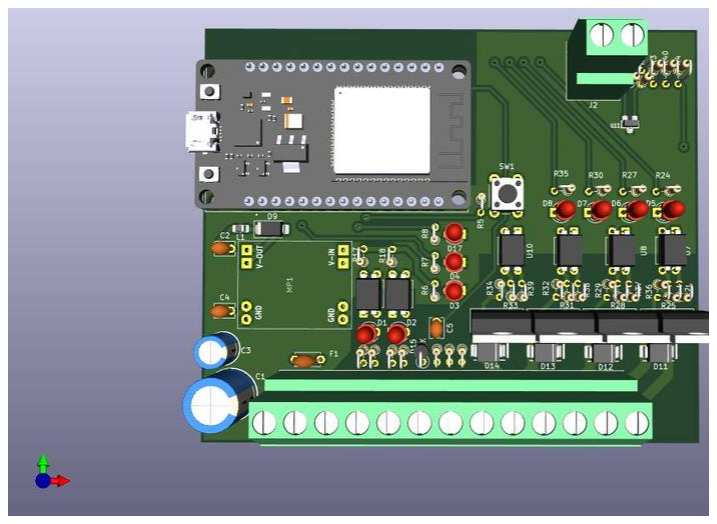
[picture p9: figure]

Figura 2a — PCB vista Top frontal. Se distinguen claramente el ESP32 (izq.), el módulo MP1584, los optoacopladores PC817 en fila y los MOSFETs IRLZ44N (der.).

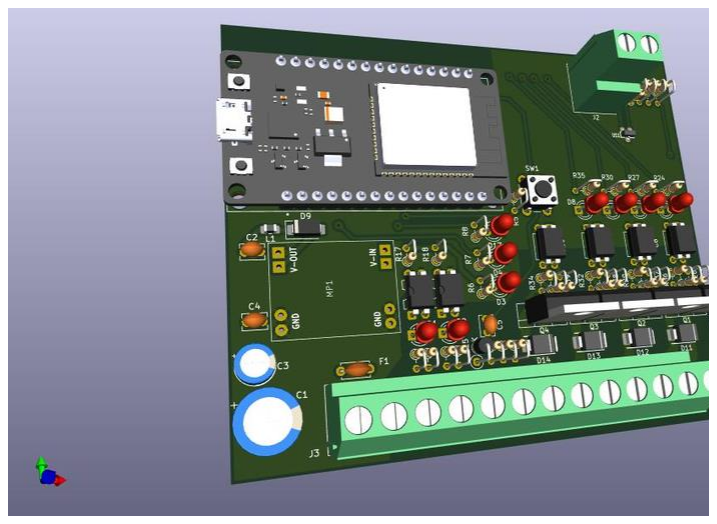
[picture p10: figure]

Figura 2b — PCB vista 3D perspectiva. Los LEDs rojos son los indicadores de las salidas digitales. Los capacitores azules son C1 (100μF) y C3 (10μF) de la fuente.

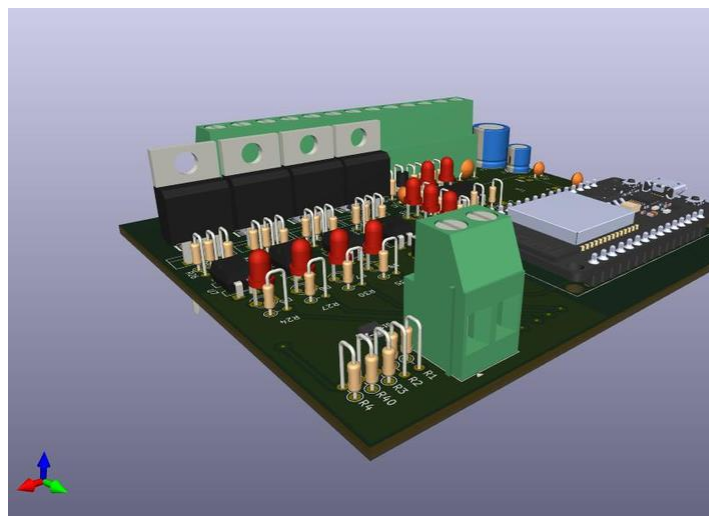
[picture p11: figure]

Figura 2c — Vista desde el lado de las borneras RS-485 (J2) y circuito de comunicación. Se ven los resistores de bias R1, R2 y el IC SP3485.

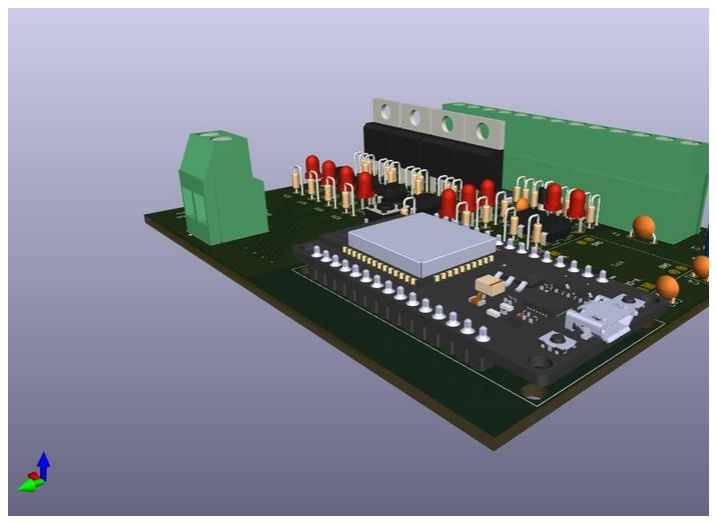
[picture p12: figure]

Figura 2d — Vista perspectiva desde la esquina de los MOSFETs IRLZ44N TO-220 y los diodos TVS SMBJ33A (SMD, negros pequeños).

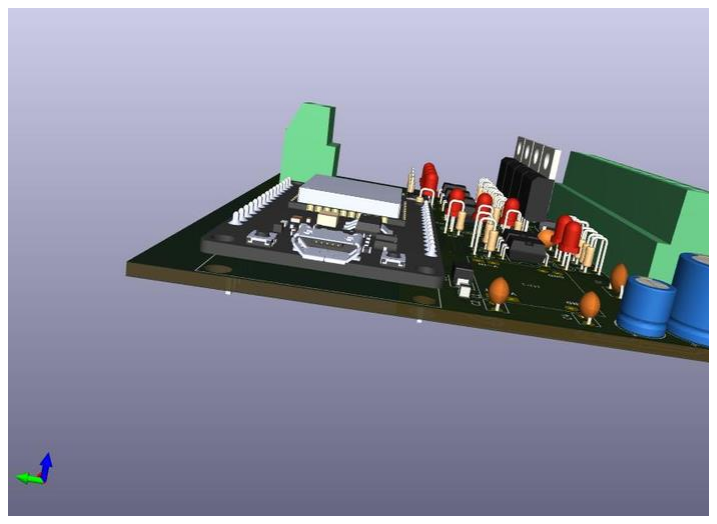
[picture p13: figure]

Figura 2e — Vista desde el lado de la bornera principal J3 (13 pines, verde). Esta bornera concentra todas las conexiones de campo.

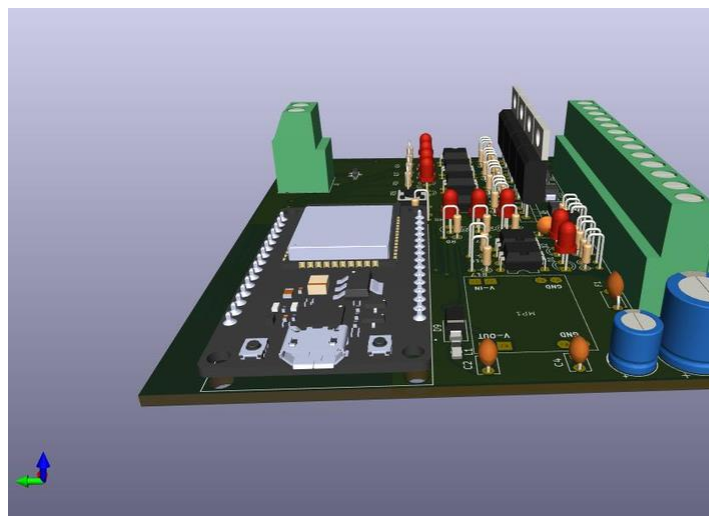
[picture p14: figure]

Figura 2f — Vista del bloque de fuente: módulo MP1584 (izq.), capacitores electrolíticos C1 y C3, ferrite bead L1 y diodo SS34 D9.

## 5.2 PCB en KiCad — Capa Top (F.Cu) y Capa Bottom (B.Cu)

Las siguientes capturas muestran el editor de PCB de KiCad 9.0.4 con las capas de cobre por separado. La capa F.Cu (roja) tiene las pistas de señal y potencia. La capa B.Cu (azul) tiene el plano de GND y las pistas de retorno. Barra de estado: 230 pads, 8 vías, 431 segmentos, 77 redes, 0 sin rutar.

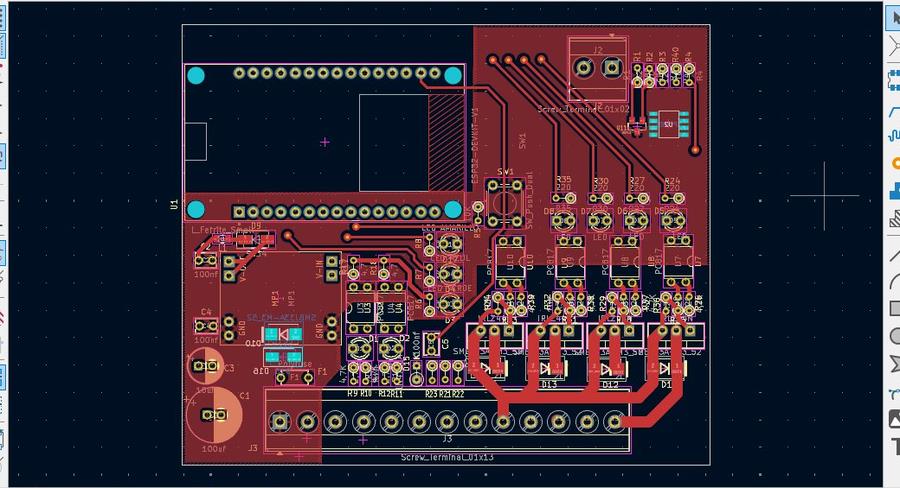
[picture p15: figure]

Figura 3 — PCB cara Top (F.Cu) en KiCad 9.0.4. Pistas rojas: 2mm potencia/alimentación, 0.8mm control/driver, 0.4mm señal lógica. El plano de GND cubre las zonas libres de pistas.

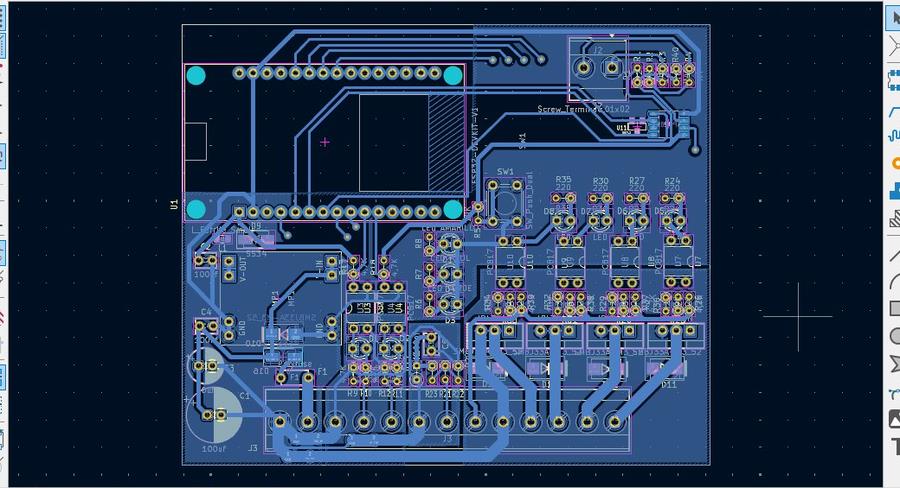
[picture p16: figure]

Figura 4 — PCB cara Bottom (B.Cu) en KiCad 9.0.4. Pistas azules, plano de GND extendido, 8 componentes SMD de protección (D10, D16, U11), y las 8 vías visibles como anillos con punto central.

## 5.3 Vista 3D del PCB

Renderizado 3D del PCB con todos los componentes montados, generado directamente desde KiCad.

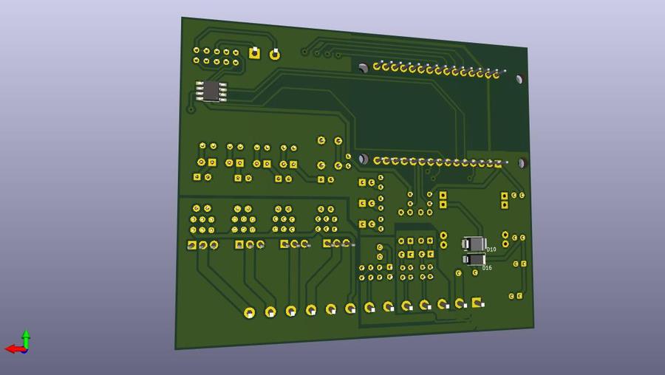
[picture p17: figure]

Figura 5 — Cara Bottom del PCB en renderizado 3D. Se aprecian los pads THT (anillos dorados), los componentes SMD de proteccion y el plano de GND.

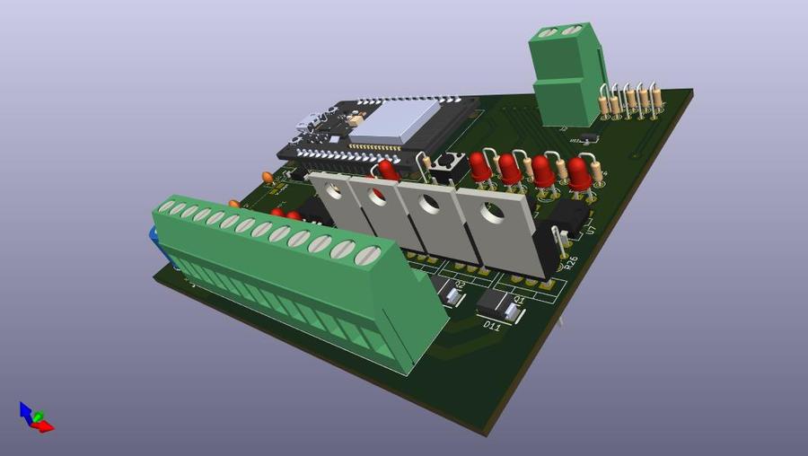
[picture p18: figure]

Figura 6 — Vista 3D cara Top perspectiva completa. ESP32 arriba-izquierda, modulo MP1584 centro-izquierda, optoacopladores y MOSFETs centro-derecha, borneras J3 en borde inferior.

## 5.4 Anchos de Pista — Norma IPC-2221

Los anchos de pista fueron calculados según la fórmula de la norma IPC-2221 para conductores externos (outer layer). Se adoptó un criterio conservador de ΔT = 10°C sobre temperatura ambiente.

Fórmula IPC-2221 para Conductores Externos

W = (I / (k × ΔT^b))^(1/c) [resultado en mils, 1 mil = 0.0254mm]

Constantes para conductores externos (outer layer):
k = 0.048, b = 0.44, c = 0.725

Conversión: W[mm] = W[mils] × 0.0254

Categoría de Pista | Corriente
Máx.

Ancho Mínimo
(IPC-2221)

Ancho
Adoptado

Corriente
Admitida @
ΔT=10°C

Señal lógica (GPIO,
control)
0.05A | 0.13mm (5 mils) | 0.4mm (15.7
mils)

≥1.5A
(margen 30×)

Control / Driver (gate
MOSFET)
0.15A | 0.27mm (10.6 mils) | 0.8mm (31.5
mils)

≥3A (margen
20×)

Potencia / Alimentación
(24V, 3.3V, OUT)
2A | 1.1mm (43 mils) | 2.0mm (78.7
mils)

≥5A (margen
2.5×)

## 5.4 Reglas de Diseño — Ubicación y Orientación de Componentes

### Regla 1: Zonas Separadas por Función

El PCB está dividido en zonas funcionales claramente separadas. Esta separación no es estética: reduce el acoplamiento electromagnético entre circuitos de alta potencia y señales sensibles.

Zona | Componentes | Motivo de Separación
Zona de potencia (derecha) | Q1-Q4 IRLZ44N, D11-D14 TVS, borneras J3 | Alta corriente de campo. Pistas anchas 2mm. Separadas de la lógica.
Zona de drivers (centro-derecha) | U7-U10 PC817, R24-R35 | Interfaz entre lógica 3.3V y potencia. Zona de transición.

Zona lógica
(centro-izquierda)

ESP32 U1, U2 SP3485,
U3-U4 PC817 entradas

Señales de baja potencia. Pistas 0.4mm. Protegida por plano GND.

Zona de fuente
(izquierda)

MP1, C1, C3, C4, L1, F1,
D9, D16

Fuente switching. Cerca de la entrada 24V para pistas cortas.

Zona de
protección (SMD
bottom)

D10, D16 SS34, U11
SM712

Componentes SMD. En la cara Bottom para liberar espacio en Top.

### Regla 2: Orientación de Componentes

- Todos los componentes THT se orientan para que sus referencias (R1, C1, Q1...) sean legibles en la misma dirección. Facilita el montaje y la verificación.
- Los capacitores electrolíticos: la banda negra y el símbolo '+' deben coincidir con la serigrafía del PCB. Error de polaridad = componente destruido.
- Los diodos: la banda del cátodo (línea plateada o negra) siempre hacia el lado indicado por la serigrafía (línea o triángulo con barra).
- Los optoacopladores PC817 DIP-4: el punto o muesca indica el Pin 1. Siempre verificar la orientación antes de soldar.
- Los MOSFET IRLZ44N TO-220: la cara plana metálica (heatsink) siempre hacia el mismo lado, siguiendo la serigrafía del PCB.
- Componentes SMD (D10, D16, U11): verificar con lupa la orientación antes de soldar. Una vez soldados son muy difíciles de desoldar correctamente.

### Regla 3: Capacitores de Desacople — Cerca del IC

Los capacitores de desacople (C4=100nF junto al módulo MP1584 y C2=100nF junto al ESP32) deben ubicarse lo más cerca posible del pin de alimentación del circuito integrado. La inductancia parásita de una pista larga cancela el efecto de desacople. La distancia ideal es menos de 5mm del pin VCC.

### Regla 4: GND Estrella

Las tierras del circuito están organizadas en grupos: GND_IN (tierra de entradas de campo), GND_CAMP (tierra de salidas de campo) y GND (tierra lógica del ESP32). Los tres grupos se unen en un único punto en el PCB (punto estrella), generalmente en la bornera de tierra de la fuente de alimentación. Esto evita que las corrientes de retorno de las salidas de potencia (ruidosas) circulen por las pistas de tierra del circuito de señal (ESP32), degradando la inmunidad al ruido.

### Regla 5: Vías — Qué Son y Para Qué Sirven

¿Qué es una vía? Una vía es un pequeño agujero perforado en el PCB que tiene sus paredes internas metalizadas con cobre. Permite que una pista de la cara Top 'salte' a la cara Bottom y continúe por allí, evitando cruzarse con otras pistas. Sin vías, muchas conexiones serían imposibles en una placa de dos capas.
Vías del PLC-CORE-MDE: Se usaron 8 vías, de 1.5mm de diámetro exterior y 0.5mm de taladro. Este tamaño es el mínimo práctico para fabricar con taladro de columna manual. Corriente admitida por cada vía (IPC-2221): hasta 1.5A, suficiente para las señales de control que las atraviesan.

## 6. Fabricación del PCB — Transferencia de Tóner

La transferencia de tóner permite fabricar PCBs artesanalmente con resultados aceptables para prototipos y proyectos educativos. Es el método elegido para este proyecto por su bajo costo y disponibilidad de materiales.

Material | Especificación | Notas para Compra
Placa de cobre FR4 | 1 cara, 1.6mm, tamaño PCB + 1cm extra | Casa de electrónica o ferretería técnica. NO usar placa de aluminio.
Papel fotográfico brillante | 120-180 g/m², brillante, NO revestido con polietileno | Específico para transferencia. Papel de revista también funciona (prueba).
Impresora láser | Tóner negro, densidad máxima, imprimir en espejo (mirror) | NO usar inkjet. Verificar que el papel entra en la impresora.
Plancha de ropa | Temperatura máxima, sin vapor | Con teflón en la base funciona mejor. Temperatura uniforme.
FeCl3 (cloruro férrico) | Solución 40%, disponible en farmacias industriales | Alternativa: solución de H2O2 + HCl (más accesible pero más peligrosa).
Acetona | Solvente puro 99% | Para limpieza previa y remoción de tóner post-grabado.
Brocas PCB carburo | 0.5mm (vías), 0.8mm (R/C), 1.0mm (Q), 1.2mm (borneras) | Imprescindible carburo. Las de acero rápido se rompen en FR4.
Lija | Grano 400-600 | Para preparar la superficie de cobre antes de la transferencia.

### Paso a Paso del Proceso

1. Exportar la capa Cu_F de KiCad en formato PDF, con la imagen ESPEJADA horizontalmente.
2. Imprimir en papel fotográfico a densidad máxima, sin escalar.
3. Limpiar la placa de cobre con lija 400 (movimiento circular) y luego con acetona. No tocar la superficie con los dedos.
4. Colocar el papel impreso sobre la placa (cara de tóner contra el cobre), fijar con cinta de papel.
5. Aplicar la plancha a temperatura máxima durante 2-3 minutos con presión firme y uniforme.
6. Sumergir en agua tibia 2-3 minutos y retirar el papel frotando suavemente. El tóner debe quedar en el cobre.
7. Retocar imperfecciones con marcador indeleble negro (Sharpie permanente).
8. Sumergir en solución FeCl3 (con EPP: guantes, antiparras, ventilación). Mover el recipiente cada 30 segundos.
9. Retirar cuando todo el cobre expuesto desaparezca (5-20 minutos). Enjuagar con agua.
10. Remover el tóner con acetona. El cobre puro con el patrón del circuito debe quedar visible.
11. Perforar con taladro de columna usando brocas de carburo en el diámetro correcto para cada componente.

12. Tineado (opcional pero recomendado): aplicar estaño en toda la superficie de cobre para prevenir oxidación.

⚠ ADVERTENCIA DE SEGURIDAD — Manejo del Cloruro Férrico

El FeCl3 es un oxidante corrosivo que mancha permanentemente ropa, piel y superficies. OBLIGATORIO: guantes de goma o nitrilo, antiparras de seguridad, guardapolvo o delantal. TRABAJAR EN LUGAR VENTILADO. El vapor irrita las vías respiratorias.
NO mezclar con bases fuertes (reacción exotérmica peligrosa).
NEUTRALIZAR residuos con bicarbonato de sodio antes de desechar (no verter al desagüe sin neutralizar).
Almacenar la solución usada en recipiente plástico hermético (HDPE o PP), alejado de metales.

## 7. Montaje de Componentes — Soldadura IPC-A-610

## 7.1 Secuencia Recomendada de Montaje

Orden | Componentes | Justificación
1° | Componentes SMD (D10, D16, U11) — cara Bottom | Más difícil con placa cargada. Se sueldan antes de
voltear la placa.
2° | Resistores (todos) | Más bajos, se asientan solos sobre la placa con los pines doblados.
3° | Diodos (D9, D15, D16, D1-D17) | Verificar POLARIDAD antes de soldar. La banda = cátodo.
4° | Capacitores cerámicos (C2, C4, C5) | No polares. Verificar que el valor sea el correcto (100nF).
5° | Polyfuse F1 | Componente de protección, bajo perfil.
6° | Optoacopladores PC817 (U3, U4, U7-U10) | Verificar orientación: el punto o muesca indica Pin 1.
7° | SP3485 (U2) | IC de comunicación. Sensible al calor. Soldar rápido.
8° | Capacitores electrolíticos (C1, C3) | Verificar POLARIDAD (+/-). El lado positivo va al +3.3V.
9° | MOSFET IRLZ44N (Q1-Q4) TO-220 | La cara metálica plana sigue la serigrafía del PCB.
10° | Borneras J2, J3 | Las más altas. Asegurarse que queden perpendiculares a la placa.
11° | Módulo MP1584 | Verificar que los pines V-IN, GND, V-OUT coinciden con el PCB.
12° | ESP32 DevKit V1 | ÚLTIMO. Verificar 3.3V en los pads antes de instalarlo.

## 7.2 Parámetros de Soldadura

| Parámetro | Valor Recomendado

Temperatura — estaño Sn63/Pb37 (con

plomo) | | 320-350°C en el cautín

Temperatura — estaño SAC305 (sin

plomo) | | 370-400°C en el cautín
Tipo de estaño recomendado | Sn63Pb37, 0.8mm con núcleo de flux
Tiempo de contacto por pad | 2-3 segundos máximo
Flux adicional para SMD | Flux neutro no corrosivo (flux pen o gel)
Limpieza final | Alcohol isopropílico 99% + cepillo de dientes

## 7.3 Criterios IPC-A-610 Clase 2

Soldaduras Aceptables vs. Defectos — IPC-A-610 Clase 2 ACEPTABLE (soldadura correcta):
- Ángulo de contacto < 90° (el estaño 'moja' bien el pad y el pin)
- Relleno completo del pad, contorno del pad visible bajo el estaño
- Superficie lisa, brillante (estaño con plomo) o ligeramente mate (sin plomo)

- Cantidad justa: ni muy poco ni exceso de estaño

DEFECTO DE PROCESO (requiere retrabajo antes de continuar):
- Puente de estaño entre pads adyacentes (cortocircuito)
- Junta fría (cold joint): estaño mate, granuloso, sin fusión
- Exceso de flux no limpiado (puede generar corrosión a largo plazo)
- Bola de estaño flotante cerca de una pista (riesgo de cortocircuito)

RECHAZO (el componente debe reemplazarse):
- Pad levantado de la placa (pista dañada, generalmente irreparable)
- Componente mal orientado o invertido (polaridad incorrecta)
- Componente erróneo (valor equivocado)

## 7.4 Verificación Antes de Energizar

13. Inspección visual completa con lupa 10×. Verificar todos los componentes polares.
14. Multímetro en modo continuidad: verificar que NO hay cortocircuito entre +24V y GND.
15. Multímetro en modo continuidad: verificar que NO hay cortocircuito entre +3.3V y GND.
16. Instalar MP1584 pero NO instalar el ESP32 aún.
17. Conectar fuente 24V DC limitada a 200mA. Medir la tensión de salida del MP1584: debe ser 3.3V ±5%.
18. Medir corriente en vacío (sin ESP32): debe ser <20mA.
19. Si todo está OK: apagar, instalar el ESP32, volver a encender.
20. El LED del ESP32 debe parpadear azul al arrancar. En el monitor serie (115200 baud): debe aparecer [PLC-CORE-MDE v5].

## 8. Carcasa y Montaje en Tablero — Diseño 3D

La carcasa del PLC-CORE-MDE fue diseñada en Tinkercad para montaje sobre riel DIN 35mm, conforme a la norma IEC 60715. El diseño consta de 3 piezas imprimibles en PLA o ABS, con un clip de enganche al riel integrado en el cuerpo principal.

## 8.1 Vistas del Modelo 3D — Tinkercad

Figura 5a — Vista frontal del PLC-CORE-MDE. Cara operativa del equipo: botón WiFi (azul), 5 LEDs de estado y ranura de borneras.

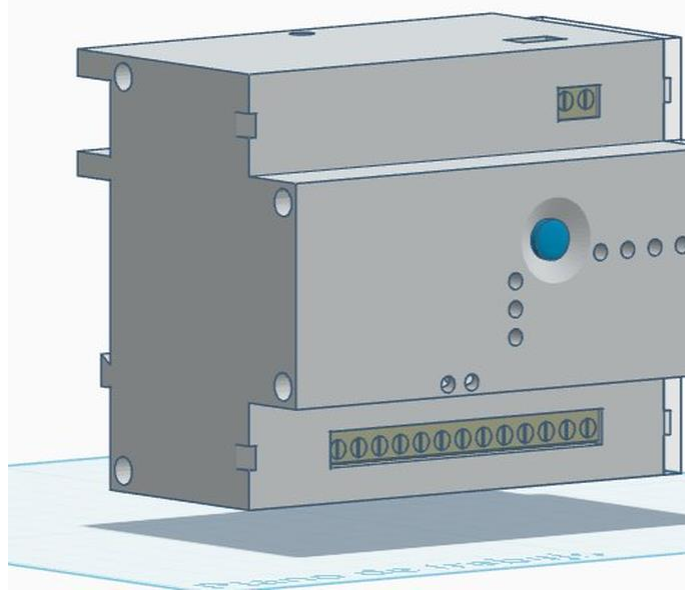
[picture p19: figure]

Figura 5b — Vista trasera del equipo. Se aprecian las lengüetas de clip para el riel DIN y la tapa superior con orificio de ventilación.

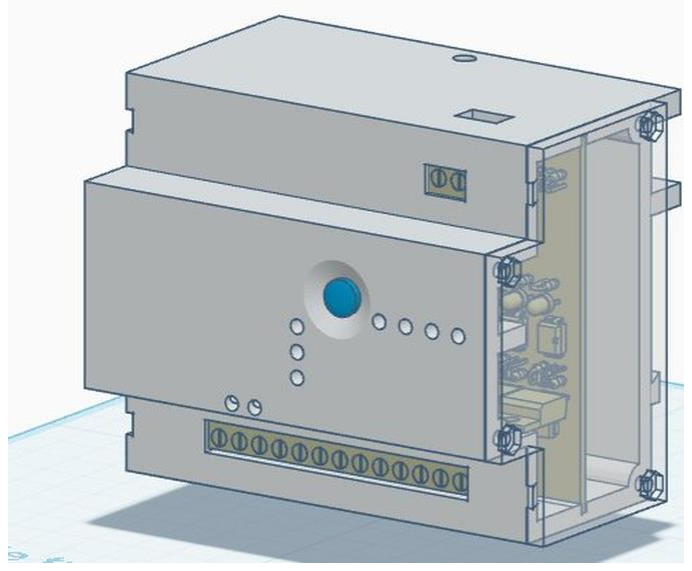
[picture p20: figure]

Figura 5c — Vista con tapa lateral abierta. Se visualiza el interior del cuerpo principal con la PCB y los componentes de mayor altura (ESP32,

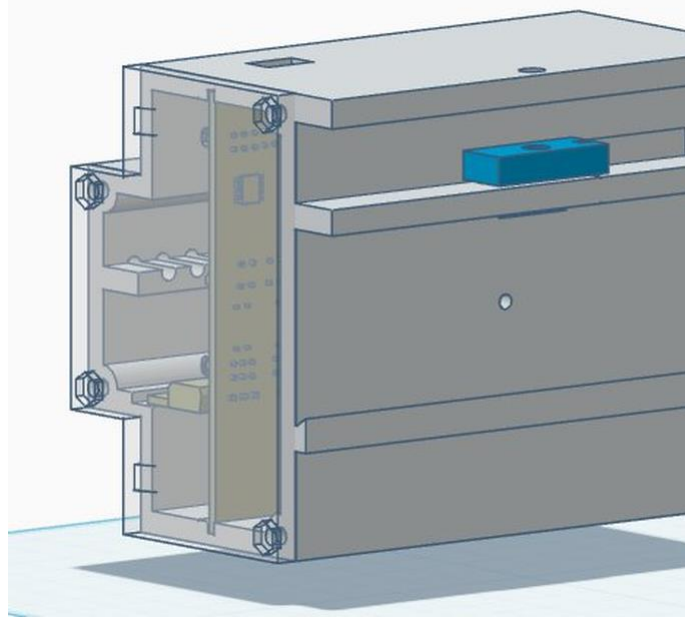
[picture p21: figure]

capacitores). | Figura 5d — Vista en corte transversal del ensamble.
| Las 3 piezas (cuerpo, tapa frontal, tapa borneras) se
| distinguen por sus posiciones relativas.

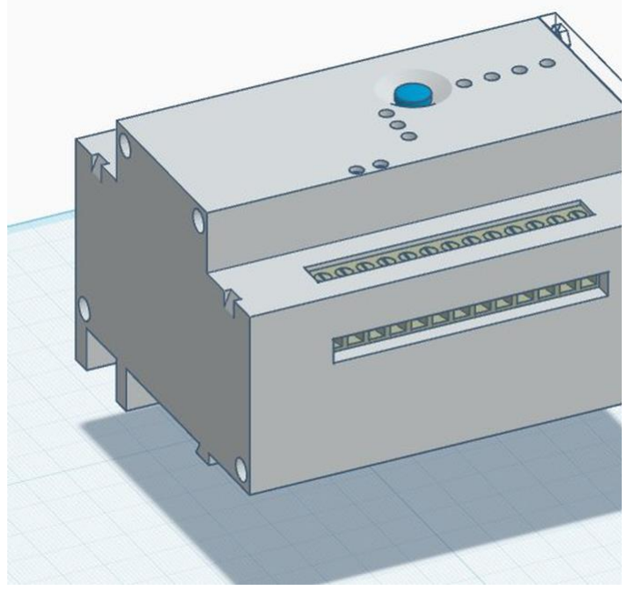
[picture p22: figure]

Figura 5e — Vista inferior mostrando la tapa de borneras y las ranuras para el paso del cableado de campo.

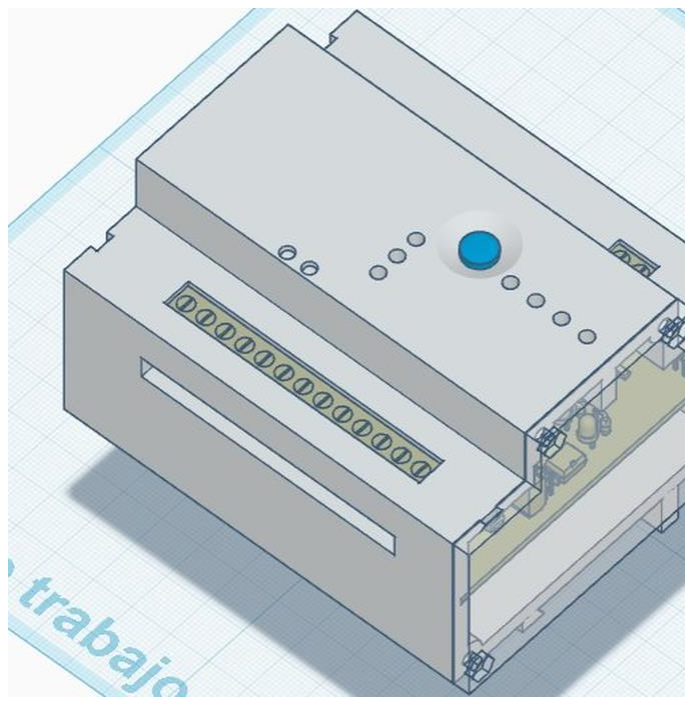
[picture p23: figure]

Figura 5f — Vista perspectiva superior con la tapa de borneras abierta. Se observa la bornera J3 de 13 pines accesible para el conexionado.

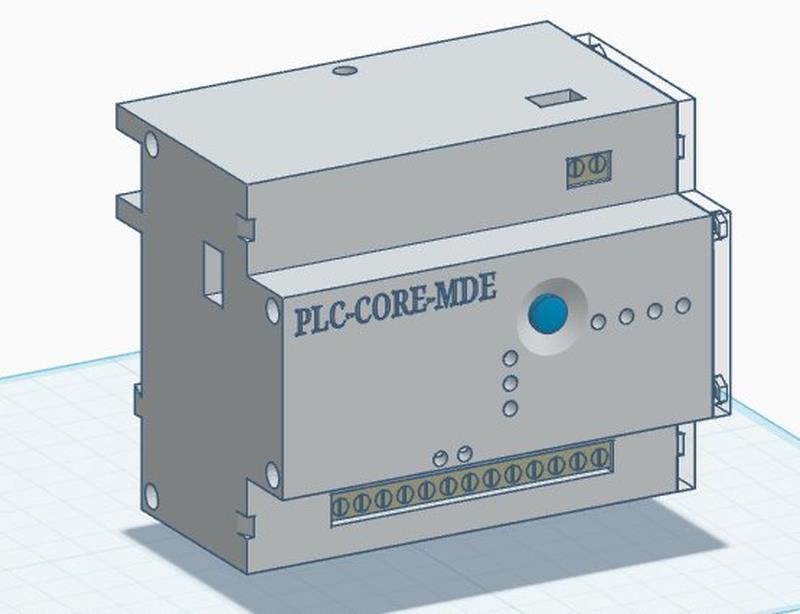
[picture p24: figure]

Figura 5g — Modelo final con etiqueta PLC-CORE-MDE serigrafíada en la tapa frontal. Esta es la vista que verá el operador en el tablero eléctrico.

Modelo 3D Tinkercad — Información de Impresión

Link al modelo: https://www.tinkercad.com/things/jLRdBf3xTZp-gabinete-plc-core-mde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 (https://www.tinkercad.com/things/jLRdBf3xTZp-gabinete-plc-core-mde)
Configuración de impresión recomendada:
- Material: PLA (temperatura ambiente interior) o PETG/ABS (ambientes con temperatura >50°C)
- Relleno (infill): 25-30% gyroid o honeycomb
- Altura de capa: 0.2mm (detalle estándar)
- Perímetros: 3 (mínimo para paredes resistentes)

- Soporte: NO requerido si se imprime en la orientación correcta
- Tiempo estimado: 4-6 horas por juego completo de 3 piezas

Las 3 piezas del juego:
1. Cuerpo principal (con clip riel DIN integrado)
2. Tapa frontal (orificios para LEDs y botón WiFi)
3. Tapa inferior de borneras (con ranuras para cableado)

## 8.2 Norma IEC 60715 — Riel DIN 35mm

El riel DIN 35mm (también llamado TS-35 o Omega rail) es el sistema de montaje estándar para equipos de automatización y distribución eléctrica en todo el mundo. La norma IEC 60715 define sus dimensiones exactas: 35mm de ancho, 7.5mm de profundidad, espesor de pared 1.0mm. El clip de enganche del PLC-CORE-MDE está diseñado para esta geometría exacta.

## 8.3 Etiquetado e Identificación de Borneras

Borne
J3 | Etiqueta | Señal | Rango/Especificación
Pin 1 | GND | Tierra común | Referencia del sistema
Pin 2 | +24V | Alimentación | 24V DC, 500mA máx.
Pin 3 | GND_IN | Tierra de entradas | Referencia de campo DI
Pin 4 | IN1 | Entrada digital 1 | 5-24V DC (GPIO21)
Pin 5 | GND_IN | Tierra de entradas | Referencia de campo DI
Pin 6 | IN2 | Entrada digital 2 | 5-24V DC (GPIO19)
Pin 7 | AI_COM | Tierra analógica | Referencia AI1
Pin 8 | AI1 | Entrada analógica 1 | 0-Vin (ver divisor)
Pin 9 | GND_CAMP | Tierra de campo salidas | Referencia DO
Pin 10 | OUT1 | Salida digital 1 | Carga a V_CAMP (GPIO14)
Pin 11 | OUT2 | Salida digital 2 | Carga a V_CAMP (GPIO27)
Pin 12 | OUT3 | Salida digital 3 | Carga a V_CAMP (GPIO26)
Pin 13 | OUT4 | Salida digital 4 | Carga a V_CAMP (GPIO25)
J2 Pin 1 | RS485 A+ | Bus RS-485 positivo | Diferencial 1.5-6V
J2 Pin 2 | RS485 B- | Bus RS-485 negativo | Diferencial

## 9. Firmware y Servidor Web

## 9.1 Arquitectura FreeRTOS Dual-Core

Distribución de Tareas en ESP32 Dual-Core

CORE 0 (PRO_CPU) — Conectividad y Servicios:
- WebServer task: servidor HTTP que atiende peticiones de la interfaz web
- ledTask: gestión del botón WiFi SW1 (debounce 50ms) + actualización LEDs
- modbusPoll: sondeo periódico de módulos RS-485 externos (Waveshare, MDE)

CORE 1 (APP_CPU) — Control en Tiempo Real:
- plcTask: scan cíclico determinista cada 10ms (100 ciclos/segundo)
- Protegido con SemaphoreHandle_t (mutex FreeRTOS) para acceso al array nodes[]

SPIFFS (memoria flash, 1.5MB):
- /program.json: programa FBD del usuario (nodos y conexiones)
- /tags.json: etiquetas simbólicas de IOs (ej: IN1='Sensor_Nivel')
- index.html, program.html, monitor.html, manual.html, CSS, JS

## 9.2 El Ciclo de Scan — 9 Fases Deterministas

El ciclo de scan se ejecuta cada 10ms en Core 1. Las 9 fases se ejecutan siempre en el mismo orden, lo que garantiza un comportamiento determinista: la misma entrada siempre produce la misma salida en el mismo tiempo.

Fase | Nombre | Operación
1 | Leer entradas físicas | Lectura GPIO21 (IN1), GPIO19 (IN2), ADC GPIO36 (AI1). Resultados en nodes[].
2 | Lógica combinacional | Evalúa bloques AND, OR, NOT, XOR, CMP. Salida inmediata sin estado interno.
3a | Timers | Actualiza TON, TOF, TP, BLINK. Usan millis() para medir el tiempo transcurrido.
3b | Contadores | Actualiza CTU (up) y CTD (down). Detecta flancos en la entrada de conteo.
3c | Memorias biestables | Evalúa SR (prioridad SET) y RS (prioridad RESET).
3d | Detección de flancos | R_TRIG (↑) y F_TRIG (↓): generan pulso de exactamente 1 ciclo (10ms).
3e | Escalado analógico | SCALE: mapea valor ADC crudo a unidades de proceso configurables.
4 | Escribir PWM | Actualiza el duty cycle del PWM en salidas configuradas en ese modo.
5 | Escribir salidas físicas | Actualiza GPIO14, 27, 26, 25. Propaga estado a nodes[] para telemetría web.

## 9.3 Botón WiFi SW1 — Implementación en Firmware

Lógica del Botón WiFi con Debounce por Software

#define BTN_WIFI_PIN 18 // GPIO18 = SW1

#define BTN_DEBOUNCE_MS 50 // 50ms de debounce

static volatile bool wifiEnabled = true; // WiFi ON al arrancar
static bool apRunning = false; | // Estado real del AP

void apStart() {
WiFi.mode(WIFI_AP);
WiFi.softAP("PLC_CORE_MDE", "12345678"); server.begin();
apRunning = true;
}

void apStop() {
server.stop();
WiFi.softAPdisconnect(true); WiFi.mode(WIFI_OFF);
apRunning = false;
}

// En ledTask (Core 0): lee GPIO18, aplica debounce 50ms, invierte wifiEnabled. // En cada ciclo verifica: si wifiEnabled != apRunning → ejecuta apStart() o apStop(). // Esto permite que /wifi/toggle web también funcione sin cortar la conexión HTTP.

## 9.4 Páginas del Servidor Web

Página | URL | Contenido Principal
Inicio | / | Menú principal, logo MDE, badge modo RUN/STOP, nodos activos, botones RUN/STOP directos
Editor FBD | /program.html | Editor visual Drawflow, paleta IEC 61131-3, botones RUN/STOP/GUARDAR/RELOAD, editor de Tags de IO
Monitor | /monitor.html | LEDs IO en tiempo real, tabla de nodos runtime, barras analógicas AI1, badge WiFi clickeable, estadísticas RS-485/Modbus
Manual | /manual.html | 8 ejemplos de programación FBD, tabla de bloques, troubleshooting, diagrama del ciclo de scan

## 10. Cómo Cargar el Proyecto al ESP32

## 10.1 Paso 1 — Instalar el Entorno Arduino

21. Descargar Arduino IDE 1.8.19 desde arduino.cc/en/software
22. Abrir Arduino IDE → Archivo → Preferencias → campo 'URLs adicionales de gestor de tarjetas'
23. Agregar la URL: https://raw.githubusercontent.com/espressif/arduino-esp32/gh-pages/package_esp32_index.json
24. Herramientas → Gestor de Tarjetas → buscar 'ESP32' → instalar 'esp32 by Espressif Systems' v2.x
25. Herramientas → Administrar Librerías → buscar 'ArduinoJson' → instalar versión 6.x

## 10.2 Paso 2 — Configurar la Placa

Configuración Arduino IDE | Valor Correcto
Placa | ESP32 Dev Module
CPU Frequency | 240MHz (WiFi/BT)
Flash Size | 4MB (32Mb)
Partition Scheme | Default 4MB with SPIFFS (1.2MB APP / 1.5MB SPIFFS)
Upload Speed | 921600
Port | COMx (Windows) o /dev/ttyUSB0 (Linux/Mac)

## 10.3 Paso 3 — Cargar el Sketch

26. Abrir el archivo PLC_CORE_MDE.ino
27. Sketch → Verificar/Compilar: no debe haber errores
28. Sketch → Subir (Upload). Tiempo estimado: 30-60 segundos
29. Abrir Monitor Serie (Ctrl+Shift+M) a 115200 baud: debe aparecer [PLC-CORE-MDE v5]

## 10.4 Paso 4 — Cargar el Sistema de Archivos SPIFFS

La carpeta /data (junto al .ino) contiene: index.html, program.html, monitor.html, manual.html, editor.js, style.css, drawflow.min.js, drawflow.min.css.
30. Instalar el plugin 'ESP32 Sketch Data Upload' para Arduino IDE 1.8.x (disponible en GitHub: arduino-esp32fs-plugin).
31. Con el ESP32 conectado y el Monitor Serie CERRADO: Herramientas → ESP32 Sketch Data Upload.
32. Esperar a que termine la transferencia (barra de progreso en la consola inferior).

## 10.5 Paso 5 — Verificar y Primer Programa

33. Conectarse a la red WiFi: SSID = PLC_CORE_MDE, contraseña = 12345678
34. Abrir navegador y navegar a: 192.168.4.1 → debe aparecer la pantalla de inicio.
35. Ir a Programar → arrastrar bloque IN1 → arrastrar bloque OUT1 → conectarlos → GUARDAR → RUN.

36. Activar IN1 (aplicar tensión entre IN1 y GND_IN): OUT1 debe activarse. El Monitor debe mostrar los cambios en tiempo real.

## 11. Normas Técnicas Referenciadas

Norma | Organismo | Título Resumido | Aplicación en este Proyecto
IPC-2221 | IPC | Generic Standard on Printed Board Design | Anchos de pista, clearances, vías, copper pours
IPC-A-610 | IPC | Acceptability of Electronic Assemblies | Criterios de calidad de soldaduras Clase
2
IEC 61131-3 | IEC | PLC Programming Languages | FBD: Function Block Diagram
IEC 61131-2 | IEC | PLC Equipment Requirements | Requisitos de hardware, tensiones, aislamiento
IEC 60715 | IEC | Dimensions of Low-voltage Switchgear | Perfil riel DIN 35mm para el gabinete
IEC 60439 | IEC | Low-voltage switchgear assemblies | Montaje en tablero, cableado, identificación
EIA/TIA-485 | TIA | Balanced Digital Multipoint Systems | Estándar eléctrico RS-485

Modbus
RTU
| Modbus.org | Modbus Application Protocol v1.1b3 | Protocolo industrial Modbus RTU
IEC 60068 | IEC | Environmental Testing | Temperatura, humedad, vibración

## 12. Lista de Materiales — BOM Completa

Lista extraída del diseño KiCad 9.0.4. Incluye función en el circuito y observaciones de adquisición en Argentina.

Ref. | Valor | Cant. | Encapsulado | Función | Obs. Argentina
Q1-Q4 | IRLZ44N | 4 | TO-220-3 | MOSFET N-ch
| | | | Logic Level salidas | Verificar 'LZ' (logic level, no IRF44N)
U3,U4,U7-U10 | PC817 | 6 | DIP-4 | Optoacoplador
| | | | aislamiento galvánico | Muy común, CTR mínimo
| | | | | 100%
U2 | SP3485 | 1 | SO-8 | Transceiver RS-
| | | | 485 half-duplex | Reemplazabl e por MAX485
U11 | SM712 | 1 | SOT-23 | TVS dual ESD
| | | | RS-485 | Si no se consigue:

TVS
| | | | | individual por línea
U1 | ESP32-
| DEVKIT- V1 | 1 | 38 pines | Microcontrolador ESP32 dual- core | Verificar 38 pines, no 30
MP1 | MP1584 | 1 | Módulo | Regulador buck
| | | | 24V→3.3V | Módulo mini DC-DC muy económico
D10-D14 | SMBJ33A | 5 | DIOM5436 SMD | TVS 33V protección transitorios | SMD. Alternativa: 1.5KE33A en DO-201
D9,D16 | SS34 | 2 | SMA | Schottky 3A protección polaridad | Alternativa: 1N5822 en DO-201
D15 | 1N4728A | 1 | DO-34 | Zener 3.3V protección ADC
Zener 3.3V
1W, muy
común
D1-D17 LEDs | 3mm | 9 | LED 3mm | Indicadores IO y estado

Rojo/verde/a
marillo/azul
3mm
R24,R27,R30,R35,R25,R28,R31,R34 | 220Ω | 8 | DIN0204 | Driver opto / serie gate MOSFET
1/4W axial
R17,R18,R26,R37,R38,R39,R9,R12 | 4.7kΩ | 8 | DIN0204 | Pull-up opto salida / polarización
1/4W axial
R5,R22,R29,R32,R36,R34 | 10kΩ | 6 | DIN0204 | Pull-up botón / pull-down gate | 1/4W axial
R23,R6,R7,R8 | 1kΩ | 4 | DIN0204 | Divisor AI1, limitadora LED | 1/4W axial

R10,R11 | 2.7kΩ | 2 | DIN0204 | Limitadora corriente LED opto DI
1/4W axial
R1,R2 | 680Ω | 2 | DIN0204 | Bias bus RS-485 | 1/4W axial
R3,R4 | 10Ω | 2 | DIN0204 | Serie ESD RS-485 | 1/4W axial
R40 | 120Ω | 1 | DIN0204 | Terminación bus RS-485 | 1/4W axial
R21 | 33kΩ | 1 | DIN0204 | Divisor resistivo AI1 superior
1/4W axial
C1 | 100μF | 1 | D10mm electrolítico | Bulk entrada 24V
50V o más
C3 | 10μF | 1 | D6.3mm electrolítico | Desacople salida regulador
16V o más
C2,C4,C5 | 100nF | 3 | Cerámico D3.8mm | Desacople HF y filtro AI
50V cerámica
L1 | Ferrite bead | 1 | SMD 0805 | Filtro EMI alimentación

600Ω@100M
Hz. Si no:
puente de
cobre
F1 | Polyfuse 500mA | 1 | Disco D4.7mm | Protección sobrecorriente recuperable

PTC 500mA
o 1A, 30V
SW1 | Pulsador 6mm | 1 | SW_PUSH_6mm dual | Botón WiFi ON/OFF
Pulsador
6×6mm para
PCB
J3 | Bornera 13 pines | 1 | Phoenix 5.08mm | Conexión campo: IO + alimentación
KF301-5.0 de
13 pines
J2 | Bornera 2 pines | 1 | Phoenix 5.08mm | Conector RS- 485 A+/B-
KF301-5.0 de
2 pines

## 13. Conclusiones y Próximos Pasos

## 13.1 Síntesis del Proyecto

El PLC-CORE-MDE es un proyecto integrador completo que abarca todas las etapas del ciclo de desarrollo de un equipo electrónico industrial: diseño esquemático con KiCad, diseño de PCB con criterios IPC-2221, fabricación artesanal por transferencia de tóner, soldadura con criterios IPC-A-610, diseño e impresión 3D de la carcasa, carga del firmware y programación de automatismos con FBD según IEC 61131-3. Construir este equipo de principio a fin es una experiencia formativa que no puede reemplazarse con simuladores ni con kits comerciales.

## 13.2 Habilidades Desarrolladas

- Diseño de PCB profesional con KiCad siguiendo normativas IPC.
- Fabricación artesanal de PCB: transferencia de tóner, grabado químico, perforado.
- Soldadura de componentes THT y SMD con criterios IPC-A-610.
- Diseño paramétrico 3D con Tinkercad para gabinetes industriales (riel DIN).
- Programación de microcontroladores con FreeRTOS (multitarea en tiempo real).
- Comprensión de protocolos industriales: RS-485, Modbus RTU.
- Programación de automatismos con lenguaje FBD (IEC 61131-3).
- Comprensión de conceptos de seguridad: aislamiento galvánico, protección contra transitorios, GND estrella.

## 13.3 Posibles Mejoras y Aplicaciones

- Hardware: agregar más canales AI (GPIO34, GPIO35), salidas de relé para CA 220V, RTC DS3231 para temporización absoluta.
- Firmware: OTA (actualización por WiFi sin USB), soporte Ladder Diagram, logging con timestamps, integración MQTT para IoT.
- Aplicaciones: automatización de riego agrícola, control de iluminación industrial, domótica rural, líneas de producción pequeñas, proyectos de educación técnica en otras instituciones.

Proyecto desarrollado para la ESETP N°748 — Materia: Montajes Electrónicos y Automatismos — 5° Año Tecnicatura en Electrónica.
Todos los archivos de diseño (KiCad PCB, modelo Tinkercad 3D, firmware Arduino) están disponibles para uso educativo libre.
Profesor responsable: Martín Entraigas | Ciclo lectivo 2026

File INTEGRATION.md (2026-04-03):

# PLC-CORE-MDE Simulator — Instrucciones de integración

## Archivos del simulador (carpeta `simulator/`)

```
simulator/
  plc_sim_state.js    — SimState + makePlcNode() + constantes de memoria
  plc_sim_io.js       — capa IO (plcReadInput, plcWriteOutput, etc.)
  plc_sim_runtime.js  — parseProgram() + plcScan() (réplica de plcScanNodes)
  plc_sim_scan.js     — loop 10ms + interceptor fetch
  sim_panel.js        — panel flotante de IO (se inyecta en el DOM)
```

## Cómo integrar en `program.html`, `ladder.html` y `monitor.html`

Agregar estas 5 líneas al final del `<head>`, **antes de cualquier otro `<script>`**:

```html
<!-- ══ SIMULADOR PLC-CORE-MDE ══════════════════════════════════ -->
<script src="simulator/plc_sim_state.js"></script>
<script src="simulator/plc_sim_io.js"></script>
<script src="simulator/plc_sim_runtime.js"></script>
<script src="simulator/plc_sim_scan.js"></script>
<script src="simulator/sim_panel.js"></script>
<!-- ══════════════════════════════════════════════════════════ -->
```

**Crítico:** deben cargarse ANTES de los scripts inline del editor, porque
`plc_sim_scan.js` parchea `window.fetch` en el momento de carga.

Opcionalmente, agregar el banner al topbar:

```html
<div id="sim-banner">SIMULADOR ACTIVO</div>
```

## Para GitHub Pages

Estructura de archivos en el repositorio:

```
/
  index.html              ← página de inicio del simulador (ya creada)
  style.css               ← estilos globales (del proyecto)
  program.html            ← editor FBD (con las 5 líneas de script)
  ladder.html             ← editor Ladder (con las 5 líneas de script)
  monitor.html            ← monitor IO (con las 5 líneas de script)
  manual.html             ← manual (sin cambios)
  drawflow.min.js
  drawflow.min.css
  drawflow.style.js
  editor.js
  script.js
  js/
    api/plc_api.js
    compiler/compiler.js
    compiler/ladder_ast.js
    compiler/ladder_decompiler.js
    compiler/ladder_program.js
    compiler/symbol_table.js
    ui/memory_panel.js
  simulator/
    plc_sim_state.js
    plc_sim_io.js
    plc_sim_runtime.js
    plc_sim_scan.js
    sim_panel.js
```

## Contrato de compatibilidad

El simulador **NO modifica** ninguno de estos archivos:
- `compiler.js`
- `ladder_decompiler.js`
- `program.html`
- `ladder.html`
- `monitor.html`
- `plc_api.js`

La integración es aditiva: los scripts del simulador se cargan primero
y parchean `window.fetch`. Cuando los editores llaman a `fetch('/save')`,
`fetch('/plc/run')`, etc., reciben respuestas simuladas sin saber que no
hay ESP32.

## Verificación

Abrir la consola del browser. Al cargar cualquier editor deberías ver:

```
[SIM] Fetch interceptor instalado
[SIM] Boot completo. Simulador listo.
```

Al guardar un programa desde el editor FBD:

```
[PLC] Nodo[0] id=1 name=input1 preset=0 outIdx=0
[PLC] Nodo[1] id=2 name=ton preset=2000 outIdx=0
[PLC] parseProgram OK: N nodos
[SIM] Programa guardado y cargado
[SIM] Scan loop iniciado (10ms)
```

## Diferencias respecto al simulador viejo

| Aspecto | Simulador viejo | Este simulador |
|---|---|---|
| Motor | Réplica parcial del firmware | Réplica exacta de `plcScanNodes()` |
| BLINK EN | `IN` de la fase (incorrecto) | `input1` leído separadamente (correcto) |
| Memory sync T/C/M | Ausente | Presente — mirrors `id % MEM_*_SIZE` |
| R[] ET timers | Ausente | `id % MEM_R_SIZE` ← elapsed ms |
| R[] CV counters | Ausente | `(id+16) % MEM_R_SIZE` ← intValue |
| Panel timers | No | Sí — barras de progreso ET |
| Panel counters | No | Sí — barras CV/PV |
| Fuente de verdad | Interpretación propia | `plc_runtime.cpp` |

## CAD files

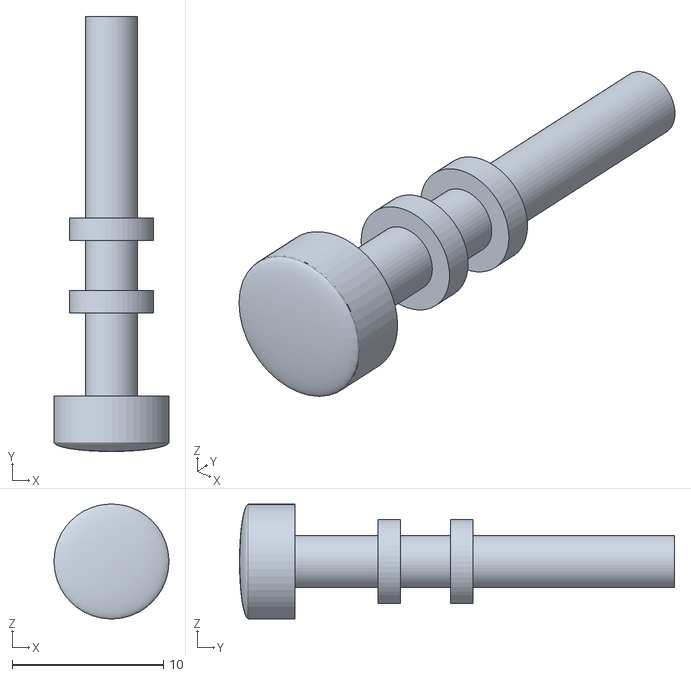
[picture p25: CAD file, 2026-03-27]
STL/GABINETE PLC CORE MDE (3).stl
7.60 x 28.8 x 7.60

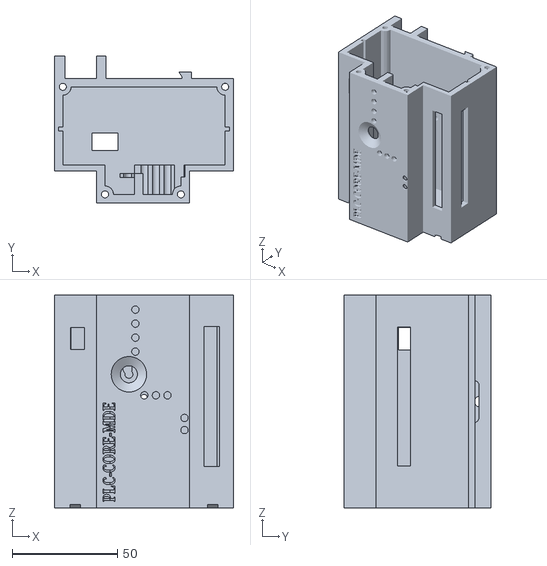
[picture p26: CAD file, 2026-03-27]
STL/GABINETE PLC CORE MDE (4).stl
85.0 x 69.5 x 101.0

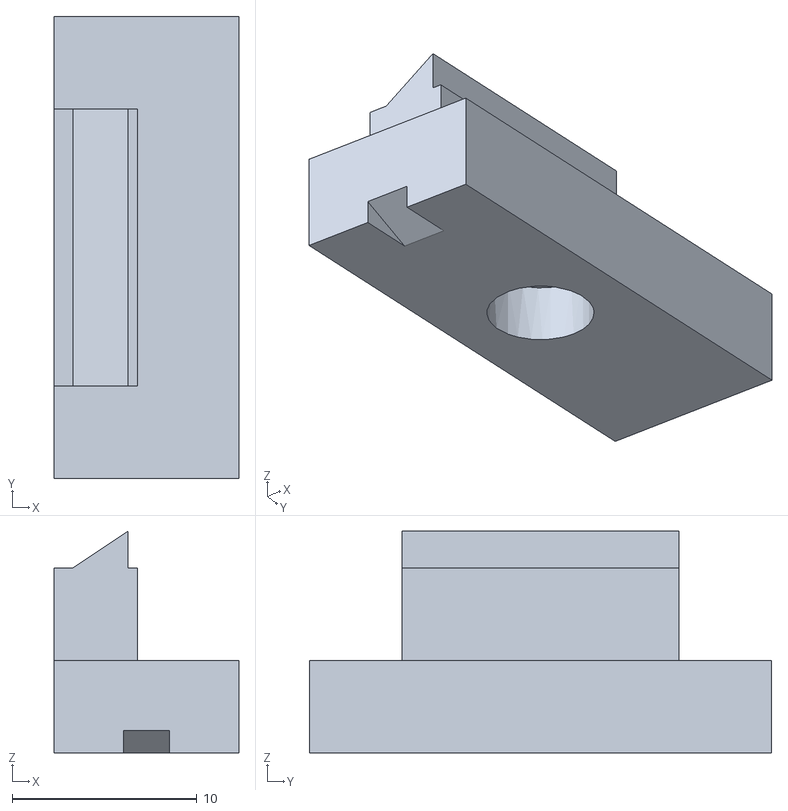
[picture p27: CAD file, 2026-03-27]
STL/GABINETE PLC CORE MDE (2).stl
10.0 x 25.0 x 12.0

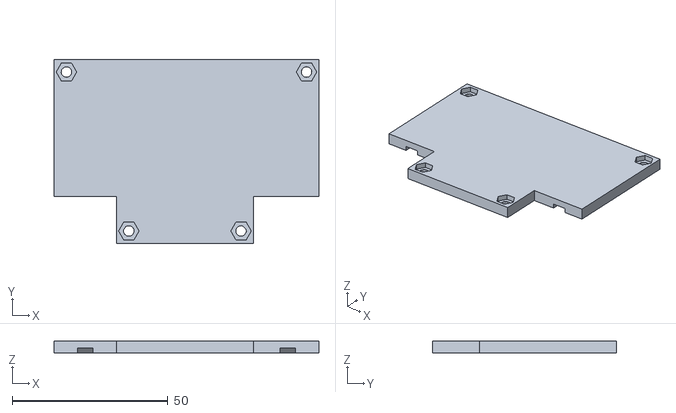
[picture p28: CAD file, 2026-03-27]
STL/GABINETE PLC CORE MDE (1).stl
85.0 x 59.0 x 4.00

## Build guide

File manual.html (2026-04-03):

MDE

Manual de Programación

⌂ Inicio ⬡ Editor

# Introducción al entorno

El PLC-CORE-MDE se programa con el editor FBD (Function Block Diagram), uno de los 5 lenguajes definidos por la norma IEC 61131-3. Cada "bloque" representa una función: entradas físicas, operaciones lógicas, temporizadores, contadores y salidas.

Conexión: conectar el computador a la red WiFi PLC_CORE_MDE (clave: 12345678), abrir el navegador en 192.168.4.1

# Ejemplos de programación

EJEMPLO 01

Control básico de motor — Arranque/Paro

### Situación

Una bomba de agua en una instalación rural debe activarse con un pulsador de arranque y detenerse con un pulsador de paro.

### Tags a configurar

Canal | Tag | Comentario
IN1 | PULSAR_ARRANQUE | Pulsador NA (normalmente abierto)
IN2 | PULSAR_PARO | Pulsador NC (normalmente cerrado)
OUT1 | BOMBA_AGUA | Contactor K1 — bomba 220V

### Lógica FBD

[IN1: PULSAR_ARRANQUE] ──┐ ├─► [SR: MEMORIA_MOTOR] ──► [OUT1: BOMBA_AGUA] [IN2: PULSAR_PARO] ──┘

Concepto clave: El bloque SR es un biestable con Set dominante. Cuando S=1, la salida queda en 1 aunque S vuelva a 0. Solo se apaga cuando R=1. Replica el circuito de automantenimiento del contactor.

EJEMPLO 02

Semáforo peatonal con temporizador

### Situación

El peatón presiona un botón, el semáforo vehicular pasa a rojo por 15 segundos, luego vuelve a verde automáticamente.

### Tags

Canal | Tag | Comentario
IN1 | BOTON_PEATONAL | Pulsador en columna semáforo
OUT1 | LUZ_ROJA_AUTO | Señal roja para vehículos
OUT2 | LUZ_VERDE_PEATON | Verde para peatón

### Lógica

[IN1] ──► [TP: PT=15000ms] ──► [OUT1: LUZ_ROJA_AUTO] └──► [NOT] ──► [OUT2: LUZ_VERDE_PEATON]

Concepto clave: El bloque TP genera exactamente un pulso de duración fija al detectar el flanco ascendente de IN. No puede re-dispararse mientras está activo.

EJEMPLO 03

Control de temperatura con histéresis

Un invernadero mantiene temperatura entre 18°C y 25°C. Sensor NTC en AI1: 0-4095 ADC = 0-50°C.

### Tags

Canal | Tag | Comentario
AI1 | SENSOR_TEMP | Sensor NTC, 0-5V = 0-50°C
OUT1 | ESTUFA_CALEF | Relé estufa eléctrica 220V

### Lógica

[AI1]──[SCALE 0-4095→0-50°C]──[CMP < 18]──S─┐ ├──[SR]──[OUT1] [AI1]──[SCALE]──[CMP > 25]───────────────R─┘

Concepto clave: La histéresis evita el ciclo rápido (chattering). Sin SCALE: 18°C = 1474 ADC, 25°C = 2048 ADC.

EJEMPLO 04

Contador de piezas en línea de producción

Al llegar a 100 piezas detectadas por sensor óptico, suena alarma y la cinta se detiene.

[IN1]──[R_TRIG]──CU─┐ ├──[CTU: PV=100]──Q──[OUT1: ALARMA] [IN2: RESET]────── R─┘ └──[NOT]──[OUT2: MOTOR]

Concepto clave: R_TRIG convierte la señal del sensor en un pulso de 1 ciclo. Sin él, el CTU podría contar múltiples veces por pieza.

EJEMPLO 05

Arranque estrella-triángulo

Motor arranca en estrella 8 segundos, luego conmuta a triángulo para reducir corriente de arranque.

[IN1]──[SR]──[OUT1: K_PRINCIPAL] ├──[TON: 8000ms]──Q──[OUT3: K_TRIANGULO] └──[TON Q]──[NOT]──[OUT2: K_ESTRELLA]

Importante: K2 y K3 deben tener enclavamiento eléctrico físico. El PLC maneja la lógica; el enclavamiento físico es obligatorio.

EJEMPLO 06

Sistema de nivel con alarma

Bomba arranca con nivel bajo, para con nivel alto, alarma si 5 min con nivel bajo sin llenarse.

[NIVEL_BAJO]──S─┐ ├──[RS]──[OUT1: BOMBA] [NIVEL_ALTO]──R─┘ [BOMBA]+[NOT NIVEL_BAJO]──[AND]──[TON: 300000ms]──[OUT2: ALARMA]

Concepto clave: El bloque RS (Reset dominante) garantiza fallo en modo seguro si el sensor de alto falla en 1.

EJEMPLO 07

Señalización intermitente

Luz parpadea a 1Hz cuando hay alarma, fija cuando el sistema está normal.

[SEÑAL_ALARMA]──[AND]──[OUT1] (parpadeo) [BLINK: 500ms]──┘ [NOT SEÑAL]──[OR]──[OUT1] (fijo o parpadeo) [AND arriba]──┘

EJEMPLO 08

Puerta automática con retardo de cierre

Puerta se abre al detectar vehículo, permanece abierta 10 segundos, luego cierra automáticamente.

[SENSOR_VEHICULO]──[TOF: 10000ms]──[OUT1: MOTOR_APERTURA] └──[OUT2: LUZ_PASO]

Concepto clave: TOF (Timer OFF-Delay) activa la salida instantáneamente y la desactiva 10s después de que el vehículo deja de ser detectado.

# Referencia rápida de bloques

Bloque | Tipo | Entradas | Salida | Uso típico
AND | Lógica | 2 BOOL | BOOL | Dos condiciones simultáneas
OR | Lógica | 2 BOOL | BOOL | Cualquiera de dos condiciones
NOT | Lógica | 1 BOOL | BOOL | Negar señal, contacto NC
XOR | Lógica | 2 BOOL | BOOL | Diferencia exclusiva
CMP | Lógica | 1 INT + umbral | BOOL | Comparar valor analógico
TON | Timer | EN + PT ms | Q BOOL | Retardo al encendido
TOF | Timer | EN + PT ms | Q BOOL | Retardo al apagado
TP | Timer | EN + PT ms | Q BOOL | Pulso de duración fija
BLINK | Timer | EN + T ms | Q BOOL | Oscilador periódico
CTU | Contador | CU + R + PV | Q BOOL | Contar eventos ascendentes
CTD | Contador | CD + LD + PV | Q BOOL | Contar regresivo
SR | Memoria | S + R | Q BOOL | Latch, automantenimiento
RS | Memoria | S + R | Q BOOL | Latch reset dominante
R_TRIG | Flanco | IN BOOL | Q BOOL | Detectar flanco ascendente
F_TRIG | Flanco | IN BOOL | Q BOOL | Detectar flanco descendente
SCALE | Analógico | IN INT | OUT INT | Escalar ADC a unidades físicas
PWM | Analógico | IN 0-4095 | Pin físico | Control velocidad, intensidad

# Resolución de problemas

### El programa se guarda pero el PLC no responde

Verificar que el estado sea RUN. El PLC arranca en RUN automáticamente al encender.

### Un temporizador se activa instantáneamente

El valor de tiempo (PT) no se guardó. Verificar que el campo tenga valor numérico (ej: 5000 para 5s). Guardar y hacer RELOAD.

### La salida OUT no responde

Ir al Monitor y verificar el estado del nodo output. Si el nodo está correcto pero el hardware no responde, verificar cableado.

### El contador no cuenta

Agregar R_TRIG entre la señal y el CU del contador. Sin R_TRIG el CTU puede incrementar múltiples veces por ciclo de scan.

### PWM no genera señal

Un pin no puede funcionar en modo digital y PWM simultáneamente.

# Ciclo de scan del PLC

El PLC ejecuta un ciclo continuo de 10ms (100 Hz):

1Leer entradas físicas (IN1, IN2, AI1)

2Lógica combinacional (AND, OR, NOT, CMP)

3Timers (TON, TOF, TP, BLINK)

4Contadores (CTU, CTD)

5Memorias (SR, RS)

6Flancos (R_TRIG, F_TRIG)

7Escalar analógicos (SCALE)

8Escribir PWM

9Escribir salidas digitales (OUT1..4) → volver a 1

La latencia máxima es de 10ms, completamente aceptable para aplicaciones industriales de control de proceso y movimiento lento.

PLC-CORE-MDE v5 · IEC 61131-3 · RS485/Modbus RTU

PLC-CORE-MDE © 2026 Martín Entraigas – MDE Electrónica Uso no comercial únicamente. Ver licencia completa

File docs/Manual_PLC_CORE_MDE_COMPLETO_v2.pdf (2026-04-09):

PLC-CORE-MDE Manual Didáctico FBD-LADDER | ESETP N°748 | Prof. Martín Entraigas
Pág. 1 | IEC 61131-3 FBD | ESP32 | RS-485 / Modbus RTU | v5 · 2026
PLC-CORE-MDE © 2026 Martín Entraigas | Uso educativo permitido – uso comercial requiere autorización

# PLC-CORE-MDE

# Manual Didáctico de Programación FBD y Ladder

# Manual Completo — Capítulos 1 al 11

# Tecnicatura en Electrónica — 5° Año

## Materia: Montajes Electrónicos y Automatismos Prof. Martín Entraigas | ESETP N°748 | 2026

## IEC 61131-3 · FBD · LADDER · ESP32 · RS-485 / Modbus RTU · SCADA

## PLC-CORE-MDE Project

## Copyright (c) 2026 Martín Entraigas / PLC-CORE-MDE Argentina

Este documento forma parte del proyecto PLC-CORE-MDE. El uso de este material está permitido únicamente con fines educativos, personales o de investigación. El uso comercial, fabricación, venta o distribución del sistema PLC-CORE-MDE requiere autorización expresa del autor.

## Este proyecto se distribuye bajo los términos de la licencia

PLC-CORE-MDE License v1.0. Para más información ver el archivo LICENSE del proyecto.

Pág. 2 | IEC 61131-3 FBD | ESP32 | RS-485 / Modbus RTU | v5 · 2026

# Índice de Contenidos

## Intro. Introducción — Hardware, ciclo de scan, lenguajes

1 Conexiones Básicas 2 Control Arranque / Paro y Memoria 3 Memoria y Enclavamiento — SR, RS, F_TRIG 4 Temporizadores — TON, TOF, TP, BLINK 5 Contadores — CTU, CTD 6 Señales Analógicas — AI1, SCALE, CMP, PWM 7 Automatización Industrial 8 Circuitos de Seguridad 9 Expansión RS-485 / Modbus RTU 10 Sistemas Completos 11 Diagnóstico y Resolución de Problemas A Apéndice — Referencia Rápida G Glosario Técnico

Pág. 3 | IEC 61131-3 FBD | ESP32 | RS-485 / Modbus RTU | v5 · 2026

# Introducción al Manual

## Este manual está diseñado para estudiantes de 5° año de la Tecnicatura en Electrónica que

nunca programaron un PLC. El objetivo es aprender programación de automatismos industriales usando el PLC-CORE-MDE, un controlador de diseño propio fabricado en la escuela.

## Cada ejemplo sigue siempre el mismo orden: Situación práctica → Esquema de conexión →

Lógica → FBD → Ladder → Tabla de estados → Prueba paso a paso → Ejercicios.

Característica | Detalle
Microcontrolador | ESP32 DevKit V1 — Dual-Core 240 MHz con WiFi integrado
Entradas digitales | 2 — IN1, IN2 (5 a 24V DC, aislación galvánica PC817)
Salidas digitales | 4 — OUT1, OUT2, OUT3, OUT4 (MOSFET IRLZ44N, hasta 10A)
Entrada analógica | 1 — AI1 (0 a 10V DC, ADC 12 bits, valores 0 a 4095)
Comunicación | RS-485 / Modbus RTU — bus industrial para expansión
Interfaz | Servidor web WiFi — editor FBD en el navegador
Alimentación | 24V DC (IEC 61131-2)
Tipo de salida | LOW-SIDE: el MOSFET conecta la carga a GND (COM_OUT)
Lenguaje principal | FBD — Function Block Diagram (IEC 61131-3)
Lenguaje alternativo | Ladder — conversión automática FBD ↔ Ladder en el editor

## Regla de oro — Conexión de salidas LOW-SIDE

+24V ──[CARGA]──OUTx──[MOSFET interno]──COM_OUT──0V
COM_OUT siempre al 0V. | La carga siempre entre +24V y OUTx. | Máximo 10A.

Pág. 4 | IEC 61131-3 FBD | ESP32 | RS-485 / Modbus RTU | v5 · 2026

# Introducción al Manual

## Este manual está diseñado para estudiantes de 5° año de la Tecnicatura en Electrónica que nunca programaron un PLC. El objetivo es aprender la programación de automatismos

industriales usando el PLC-CORE-MDE, un controlador de diseño propio fabricado en la escuela.

## No se asumen conocimientos previos de programación. Sí se asume que el estudiante conoce

conceptos básicos de electricidad (tensión, corriente, circuito serie/paralelo, contacto NA/NC).

## Cada ejemplo del manual sigue siempre el mismo orden: Situación práctica → Esquema de

conexión → Lógica → FBD → Ladder → Tabla de estados → Prueba paso a paso → Ejercicios.

# El PLC-CORE-MDE — Hardware

Característica | Detalle
Microcontrolador | ESP32 DevKit V1 — Dual-Core 240 MHz con WiFi integrado
Entradas digitales | 2 — IN1, IN2 (5 a 24V DC, aislación galvánica por optoacoplador PC817)
Salidas digitales | 4 — OUT1, OUT2, OUT3, OUT4 (MOSFET IRLZ44N, hasta 10A por salida)
Entrada analógica | 1 — AI1 (0 a 10V DC, conversor ADC de 12 bits, valores 0 a 4095)
Comunicación | RS-485 / Modbus RTU — bus industrial para módulos de expansión
Interfaz de usuario | Servidor web WiFi — editor FBD en el navegador, sin software adicional
Alimentación | 24V DC (estándar industrial IEC 61131-2)
Tipo de salida | LOW-SIDE: el MOSFET conecta el polo negativo de la carga a GND
Lenguaje principal | FBD — Function Block Diagram (IEC 61131-3)
Lenguaje alternativo | Ladder — conversión automática FBD ↔ Ladder en el editor

## Terminales del PLC

Borne | Función | Notas de conexión
IN1 | Entrada digital 1 | Pulsadores, sensores (5-24V DC). Conectar a +24V a través del dispositivo.
IN2 | Entrada digital 2 | Igual que IN1. Segunda entrada digital.
COM_IN | Común de entradas | Siempre conectar al 0V (negativo) de la fuente de 24V.
AI1 | Entrada analógica | Señal 0 a 10V DC (sensor de temperatura, presión, nivel, etc.)
GND_AI | Referencia analógica | Conectar al 0V de la fuente. Referencia para AI1.
OUT1 | Salida digital 1 | Carga entre +24V y este borne. COM_OUT al 0V.
OUT2 | Salida digital 2 | Igual que OUT1.
OUT3 | Salida digital 3 | Igual que OUT1.
OUT4 | Salida digital 4 | Igual que OUT1.

Pág. 5 | IEC 61131-3 FBD | ESP32 | RS-485 / Modbus RTU | v5 · 2026
Borne | Función | Notas de conexión
COM_OUT | Común de salidas | Siempre conectar al 0V de la fuente. NUNCA dejar sin
| | conectar.

## ⚡ Regla de oro — Salidas LOW-SIDE

## Cómo conectar una carga en OUT1 (igual para OUT2, OUT3, OUT4):

+24V | ──── [ CARGA (lámpara, bobina, etc.) ] ──── OUT1 | ──── [MOSFET interno] ────
COM_OUT ──── 0V

Cuando el PLC activa OUT1: el MOSFET conduce → la carga recibe corriente → actúa. Cuando el PLC desactiva OUT1: el MOSFET corta → la carga no recibe corriente → no actúa.

⚠ COM_OUT siempre al 0V. ⚠ La carga siempre entre +24V y OUTx. ⚠ Máximo 10A por salida.

# Bloques disponibles en el editor FBD

Bloque | Tipo | Descripción breve | Compatible
| | | Ladder
IN1, IN2 | Entrada digital | Lee el estado de la entrada física. Salida:
| | BOOL (0 o 1). | ✅Sí
OUT1..OUT4 | Salida digital | Activa la salida física. Entrada: BOOL. | ✅Sí
AI1 | Entrada analógica | Lee sensor analógico. Salida: número entero 0 a 4095. | ⚠ No directo
AND | Lógica | Salida 1 solo si AMBAS entradas son 1. | ✅Sí (serie)
OR | Lógica | Salida 1 si AL MENOS UNA entrada es 1. | ✅Sí (paralelo)
NOT | Lógica | Invierte la señal: 0→1, 1→0. | ✅Sí (contacto NC)
XOR | Lógica | Salida 1 solo si las entradas son DISTINTAS. | ⚠ Aproximado
CMP | Comparación | Compara un valor INT con un umbral. Salida: BOOL. | ⚠ Aproximado
TON | Timer | Retardo al encendido. Configurable en ms. | ✅Sí
TOF | Timer | Retardo al apagado. Configurable en ms. | ✅Sí
TP | Timer | Pulso de duración fija al detectar flanco. | ✅Sí
BLINK | Timer | Oscilador periódico. Configurable en ms. | ⚠ Aproximado
CTU | Contador | Contador ascendente. Q=1 cuando CV ≥ PV. | ✅Sí
CTD | Contador | Contador descendente. Q=1 cuando CV ≤ 0. | ✅Sí
SR | Memoria | Latch con prioridad SET. S=arranque,
| | R=parada. | ✅Sí
RS | Memoria | Latch con prioridad RESET. R domina sobre

## S. ✅Sí

R_TRIG | Flanco | Detecta flanco ascendente (0→1). Pulso de 1
| | ciclo. | ✅Sí
F_TRIG | Flanco | Detecta flanco descendente (1→0). Pulso de
| | 1 ciclo. | ✅Sí

Pág. 6 | IEC 61131-3 FBD | ESP32 | RS-485 / Modbus RTU | v5 · 2026
Bloque | Tipo | Descripción breve | Compatible Ladder
SCALE | Analógico | Escala valor ADC (0-4095) a unidades físicas. | ❌No convertible
PWM | Analógico | Control de potencia por anchura de pulso. | ❌No convertible

# El ciclo de scan — cómo funciona el PLC

El PLC no ejecuta el programa una sola vez. Lo repite cíclicamente cada 10 milisegundos (100 veces por segundo). Este ciclo se llama ciclo de scan.

Fase | Operación | Detalle
1 | Leer entradas físicas | GPIO IN1 (pin 21), IN2 (pin 19), AI1 (pin 36). Se toman como "foto" del estado actual.

2

## Ejecutar lógica combinacional

## AND, OR, NOT, XOR, CMP calculan su salida con los valores

leídos.

3a | Actualizar timers | TON, TOF, TP, BLINK avanzan sus contadores internos de tiempo.
3b | Actualizar contadores | CTU, CTD actualizan su valor CV.
3c | Actualizar memorias | SR, RS actualizan su salida Q según las entradas S y R.
3d | Detectar flancos | R_TRIG, F_TRIG comparan el estado actual con el del ciclo anterior.
3e | Escalar analógicos | SCALE convierte el valor de AI1 a unidades físicas.
4 | Escribir salidas PWM | Se actualiza el duty cycle de las salidas PWM.
5 | Escribir salidas físicas | GPIO OUT1(14), OUT2(27), OUT3(26), OUT4(25) reciben el valor calculado.

## Concepto clave: snapshot IEC 61131-3

## Todos los bloques leen el estado del ciclo ANTERIOR, no el del ciclo actual. Esto permite

que los circuitos con realimentación (como el toggle) funcionen correctamente: en el ciclo N se calcula el nuevo estado, y en el ciclo N+1 ese nuevo estado ya está disponible para ser leído por los otros bloques.

# Dos lenguajes: FBD y Ladder

## El PLC-CORE-MDE trabaja principalmente con FBD (Function Block Diagram), pero el editor

puede mostrar el equivalente en Ladder para los programas compatibles. En este manual vas a aprender ambos lenguajes lado a lado.

Característica | FBD — Function Block Diagram | Ladder — Diagrama de Escalera
Representación | Bloques gráficos conectados con líneas | Contactos y bobinas en "peldaños"
Origen | IEC 61131-3, sistemas modernos | Basado en diagramas de relés eléctricos
Intuición para | Flujo de datos y señales | Circuitos eléctricos de control

Pág. 7 | IEC 61131-3 FBD | ESP32 | RS-485 / Modbus RTU | v5 · 2026
Característica | FBD — Function Block Diagram | Ladder — Diagrama de Escalera
Uso en industria | PLCs modernos, sistemas SCADA | Muy difundido en todo el mundo
En el PLC-CORE | Lenguaje nativo del editor | Conversión automática desde FBD

Pág. 8 | IEC 61131-3 FBD | ESP32 | RS-485 / Modbus RTU | v5 · 2026

# Capítulo 1 — Conexiones Básicas

Aprenderemos a conectar pulsadores, interruptores y sensores al PLC, y a programar las salidas más simples. Este capítulo es la base de todo lo que sigue. Los programas son de un solo bloque; la complejidad irá creciendo en cada capítulo siguiente.

# Ejemplo 1.1 — Pulsador NA controla una lámpara

## 1. Situación práctica

Un banco de pruebas necesita verificar si un foco funciona. El operario presiona un botón: el foco enciende. Al soltar el botón: el foco se apaga. No hay memoria ni retardo. Es el programa más simple posible.

## 2. Esquema de conexión

┌─────────────────────────────── PLC-CORE-MDE ─────────────────────────────┐
│ | | | │
│ +24V ──┬──[PULSADOR NA]── IN1 | OUT1 ──[LÁMPARA 24V]──┬── +24V | │
│ | │ | │ | │
│ 0V ───────────────────── COM_IN | COM_OUT ─────────────────┴── 0V | │
│ | | | │
└───────────────────────────────────────────────────────────────────────────┘

Reposo (pulsador abierto): IN1 = 0V → PLC lee 0 → OUT1 = 0 → lámpara apagada Pulsado (pulsador cerrado): IN1 = 24V → PLC lee 1 → OUT1 = 1 → lámpara encendida

Borne PLC | Conectar a | Dispositivo
IN1 | +24V a través del pulsador NA | Un terminal al pulsador; el otro terminal del pulsador a +24V
COM_IN | 0V de la fuente (negativo) | Cable negro / azul al negativo
OUT1 | Un extremo de la lámpara | El otro extremo de la lámpara al +24V de la fuente
COM_OUT | 0V de la fuente (negativo) | Cable negro / azul al negativo de la fuente

## 3. Lógica del circuito

La lógica es directa: OUT1 = IN1. La salida sigue exactamente el estado de la entrada. Si la entrada es 1 (pulsador presionado), la salida es 1 (lámpara encendida). Si la entrada es 0 (pulsador suelto), la salida es 0 (lámpara apagada).

## No hay memoria: al soltar el pulsador la lámpara se apaga inmediatamente. Para que quede encendida sin sostener el botón, se necesita un bloque de memoria (SR, que veremos en el

Capítulo 2).

Pág. 9 | IEC 61131-3 FBD | ESP32 | RS-485 / Modbus RTU | v5 · 2026

## 4. Diagrama FBD

┌──────────┐ | ┌──────────┐
│ | IN1 | │ | │ | OUT1 | │
│(PULSADOR)├────────────────────┤ (LÁMPARA)│
└──────────┘ | └──────────┘

IN1 ─────────────────────────────────────► OUT1
(BOOL: 0 o 1) | (BOOL: 0 o 1)

Pasos en el editor FBD:
1. Clic en el bloque IN1 de la paleta → aparece en el canvas
2. Clic en el bloque OUT1 de la paleta → aparece en el canvas
3. Clic en la salida de IN1 → arrastrar hasta la entrada de OUT1
4. GUARDAR → RUN

## 5. Diagrama Ladder equivalente

En Ladder, este circuito es un "peldaño" (rung) con un contacto NA de IN1 y una bobina de OUT1:

Rung 1:
| | [ IN1 ] | ( OUT1 ) | |
| | Contacto NA | Bobina | |
| | (pulsador) | (lámpara) | |

Lectura: "Si IN1 está en 1 (pulsador presionado),
| entonces OUT1 = 1 (lámpara encendida)."

✅ Compatibilidad: conversión FBD → Ladder PERFECTA (Level 1)

## 6. Tabla de estados

IN1 (pulsador) | OUT1 (lámpara) | Estado del sistema
0 (suelto) | 0 | Reposo — lámpara apagada
1 (presionado) | 1 | Activo — lámpara encendida

## 7. Prueba paso a paso en el PLC real

1. Conectar el hardware según el esquema de conexión.
2. En el navegador, ir a 192.168.4.1 → Editor FBD.
3. Crear el programa: bloque IN1 → bloque OUT1, conectados.
4. Hacer clic en GUARDAR y luego en RUN. El badge debe mostrar "RUN" en verde.
5. Presionar el pulsador físico: verificar que la lámpara enciende.
6. Soltar el pulsador: verificar que la lámpara apaga.
7. En el Monitor (192.168.4.1/monitor.html): verificar que IN1 y OUT1 cambian juntos.

## 8. Ejercicios

- Conectar una segunda lámpara a OUT2 controlada por IN2 en forma independiente. Escribir el FBD y el Ladder correspondiente.

## - ¿Qué pasa si el pulsador se conecta al revés (COM_IN al +24V y +24V al 0V)? Analizar

antes de probarlo.

Pág. 10 | IEC 61131-3 FBD | ESP32 | RS-485 / Modbus RTU | v5 · 2026

## - [Desafío] Medir con multímetro la tensión entre OUT1 y COM_OUT cuando la salida está activa. ¿Cuánto mide? ¿Por qué no es exactamente 0V? (pista: MOSFET tiene caída de tensión pequeña)

# Ejemplo 1.2 — Interruptor de palanca controla una lámpara

## 1. Situación práctica

Una lámpara de zona en un depósito debe permanecer encendida mientras el operario trabaja. Se usa un interruptor de palanca (no un pulsador) para no tener que mantener presionado nada.

## 2. Diferencia entre pulsador e interruptor

Dispositivo | Comportamiento | Uso típico | Símbolo
Pulsador NA | Conduce SOLO mientras se
| presiona. Vuelve a abierto
solo.
| | Arranque, timbre, prueba | ─[ ]─
Pulsador NC | Conduce SIEMPRE. Se abre
| solo mientras se presiona. | Parada, emergencia (ver
Ej. 1.3) | ─[/]─
Interruptor NA | Abierto en reposo. Cierra y
| MANTIENE la posición. | Iluminación, modos de
| | operación | ─/ ─
Interruptor NC | Cerrado en reposo. Abre y
| MANTIENE la posición. | Enclavamientos,
seguridad | ─/─

## 3. Esquema de conexión

+24V ──[INTERRUPTOR NA]── IN1 | OUT1 ──[LÁMPARA]──┬── +24V
0V ──────────────────── COM_IN | COM_OUT ─────────────┘── 0V

El cableado es IDÉNTICO al Ejemplo 1.1.
Lo único que cambia es el dispositivo físico en IN1. El PROGRAMA FBD también es idéntico: IN1 → OUT1

## 4. FBD y Ladder

## El programa FBD es idéntico al Ejemplo 1.1. El Ladder también es igual. El comportamiento cambia porque el dispositivo físico mantiene su posición:

FBD: [ IN1 ] ─────────────────────────────────── [ OUT1 ]

LADDER:
| | [ IN1 ] | ( OUT1 ) | |
| | (interruptor) | (lámpara) | |

Con pulsador: lámpara ON solo mientras se presiona.
Con interruptor: lámpara ON o OFF según la posición del interruptor. → El PROGRAMA es el mismo. El COMPORTAMIENTO cambia por el hardware.

Pág. 11 | IEC 61131-3 FBD | ESP32 | RS-485 / Modbus RTU | v5 · 2026

## 5. Tabla de estados

Posición interruptor | IN1 | OUT1 (lámpara) | Estado
Abierto (OFF) | 0 | 0
| | | Lámpara apagada — se mantiene

## indefinidamente

Cerrado (ON) | 1 | 1
| | | Lámpara encendida — se mantiene

## indefinidamente

## 6. Ejercicios

## - Conectar un microswitch de puerta a IN1. La lámpara enciende cuando la puerta está

cerrada (microswitch NA presionado por la puerta). Describir el cableado.

## - Agregar un bloque NOT entre IN1 y OUT1. ¿Cuándo enciende la lámpara ahora? ¿Para qué sirve en el contexto de una puerta? (respuesta: enciende cuando la puerta está ABIERTA → alarma de puerta abierta)

- [Desafío] Dibujar el Ladder del circuito con NOT (pista: usar un contacto NC).

# Ejemplo 1.3 — AND: dos condiciones para activar una salida

## 1. Situación práctica

Una lámpara de advertencia se activa con el botón verde (NA) solo si el botón rojo de parada (NC) no está presionado. Se introduce el bloque AND y el concepto de contacto NC y fail-safe.

## 2. El contacto Normalmente Cerrado (NC) — Concepto fail-safe

## ¿Por qué los botones de parada son siempre NC?

Un pulsador NC en reposo conduce: IN2 = 1. Al presionarlo: IN2 = 0.

## Ventaja de seguridad:

- Si se corta el cable del botón NC → señal pasa a 0 → el sistema PARA (estado seguro).

## - Si se corta el cable de un botón NA → señal queda en 0 → el sistema NO SABE si fue

presionado o hay falla.
- Con NC, cualquier falla (cable cortado, botón roto, conector suelto) DETIENE la máquina.
- Esto se llama "fail-safe" o "fallo seguro": la falla lleva al estado más seguro.

## Regla industrial: botones de ARRANQUE → NA. Botones de PARADA / EMERGENCIA

→ NC.

## 3. Esquema de conexión

+24V ──[PULS. NA verde]── IN1 | OUT1 ──[LÁMPARA]──┬── +24V
+24V ──[PULS. NC rojo ]── IN2
0V ──────────────────── COM_IN | COM_OUT ─────────────┘── 0V

Reposo: pulsador NA abierto (IN1=0), pulsador NC cerrado (IN2=1) Verde presionado: IN1=1, IN2=1 → AND = 1 → lámpara enciende
Rojo presionado: IN2=0 → AND = 0 → lámpara apaga (sin importar IN1)

Pág. 12 | IEC 61131-3 FBD | ESP32 | RS-485 / Modbus RTU | v5 · 2026

## 4. El bloque AND

El bloque AND tiene dos entradas (A y B) y una salida. La salida es 1 solamente cuando AMBAS entradas son 1 simultáneamente. Si cualquiera de las dos es 0, la salida es 0.

IN1 (A) | IN2 (B) | AND (salida) | Estado
0 | 0 | 0 | Ninguna condición activa
1 | 0 | 0 | Solo arranque → paro tiene prioridad
0 | 1 | 0 | Solo condición de habilitar → sin arranque
1 | 1 | 1 | Ambas condiciones cumplidas → lámpara enciende

## 5. Diagrama FBD

A ┌───────────┐
[IN1] ─────┤ | | │
│ | AND | ├─────────────── [OUT1]
[IN2] ─────┤ | | │
B └───────────┘

OUT1 = IN1 AND IN2

Pasos en el editor:
1. Agregar IN1 desde la paleta
2. Agregar IN2 desde la paleta
3. Agregar AND (sección Lógica) desde la paleta
4. Agregar OUT1 desde la paleta
5. Conectar IN1 → entrada A del AND
6. Conectar IN2 → entrada B del AND
7. Conectar salida del AND → entrada de OUT1
8. GUARDAR → RUN

## 6. Diagrama Ladder equivalente

En Ladder, el AND se representa con dos contactos en SERIE (uno a continuación del otro). La

## corriente llega a la bobina solo si ambos contactos conducen:

Rung 1:
| | [ IN1 ] | [ IN2 ] | ( OUT1 ) | |
| | Contacto NA | Contacto NC | Bobina | |
| (puls. verde) | (puls. rojo) | (lámpara) | |

Nota sobre el contacto NC en Ladder:
El contacto [/] (NC) de IN2 conduce cuando IN2 = 1 (botón rojo sin presionar). Cuando se presiona el botón NC físico → IN2 = 0 → el contacto [/] abre → corta.

Esto puede parecer paradójico: el contacto NC en Ladder representa el
estado lógico invertido de la variable. El botón NC físico ya entrega 1
en reposo; el contacto NC en Ladder invierte eso para la lógica interna. En este caso, como IN2 ya viene con lógica invertida del hardware,
se usa contacto NA en Ladder para que la lógica resulte correcta.

✅ Compatibilidad: conversión FBD → Ladder PERFECTA (Level 1)

Pág. 13 | IEC 61131-3 FBD | ESP32 | RS-485 / Modbus RTU | v5 · 2026

## 7. Tabla de estados completa

Situación | IN1 (NA) | IN2 (NC) | OUT1 (lámpara) | Análisis
Reposo | 0 | 1 | 0 | 0 AND 1 = 0 → apagada
Verde presionado | 1 | 1 | 1 | 1 AND 1 = 1 → encendida
Rojo presionado | 0 o 1 | 0 | 0 | X AND 0 = 0 → siempre apagada
Cable IN2 cortado | 0 o 1 | 0 | 0 | Falla → estado seguro (apagada)

## 8. Prueba paso a paso

8. Cargar el programa y activar RUN.
9. Presionar solo el verde (IN1=1, IN2=1) → lámpara enciende.
10. Presionar solo el rojo (IN1=0, IN2=0) → lámpara apagada.
11. Presionar ambos juntos (IN1=1, IN2=0) → lámpara apagada (rojo domina).

## 12. Simular cable cortado: desconectar el cable de IN2 → IN2 = 0 → lámpara apaga

automáticamente. Verificar comportamiento fail-safe.

## 9. Ejercicios

## - Conectar dos pulsadores NC en serie física entre +24V e IN2 (dos botones de parada). El programa FBD no cambia. ¿Qué ventaja da esto? - Cambiar AND por OR. Probar y describir: ¿cuándo enciende ahora la lámpara?

- [Desafío] Dibujar el Ladder del circuito con OR (pista: los contactos van en paralelo, uno encima del otro).

# Ejemplo 1.4 — Sensor industrial y carga de 220V AC mediante relé

## 1. Situación práctica

## Un sensor de temperatura activa un ventilador de 220V AC. El PLC no puede controlar 220V

directamente (sus salidas son 24V DC hasta 10A). El relé es el interfaz entre ambos circuitos: su bobina trabaja en 24V DC y sus contactos manejan 220V AC.

## 2. Esquema de conexión

Elemento | Tensión | Corriente | Función
Salida OUT1 del PLC | 24V DC | Baja (≈ mA) | Controla la bobina del relé
Bobina del relé | 24V DC | Baja (≈ mA) | Se energiza con la señal del PLC
Contacto NA del relé | 220V AC | Alta (A) | Conecta el ventilador a la red
| | | eléctrica
Ventilador | 220V AC | Depende del
| | motor | Carga controlada

CIRCUITO 24V DC (controlado por el PLC):
+24V ──[SENSOR]── IN1 | OUT1 ──[BOBINA RELÉ]──┐

Pág. 14 | IEC 61131-3 FBD | ESP32 | RS-485 / Modbus RTU | v5 · 2026

0V ──────────── COM_IN COM_OUT ───────────────┘── 0V

CIRCUITO 220V AC (controlado por el relé):
FASE ──[CONTACTO NA DEL RELÉ]──[VENTILADOR]── NEUTRO

⚠ AMBOS CIRCUITOS FÍSICAMENTE SEPARADOS. El relé es el puente. ⚠ El cableado de 220V AC debe realizarlo personal habilitado.
⚠ El circuito 220V debe tener protección termomagnética adecuada.

## 3. Tipos de sensores industriales

Tipo sensor | Funcionamiento | Cableado a IN1 | Notas
Contacto seco (NA) | Contacto mecánico. Sin polaridad. | +24V → sensor → IN1. COM_IN → 0V | El más simple. Igual al pulsador.
Sensor PNP | Al activarse entrega +24V en su salida.

## Salida PNP → IN1. +24V → VCC sensor. GND sensor → COM_IN

## El más común. La salida entrega

corriente.

Sensor NPN | Al activarse conecta su salida a 0V.

## Salida NPN → IN1. Pull-up

4.7kΩ entre +24V e IN1.

## GND → COM_IN

## Requiere resistencia pull-up

externa.

## 4. FBD y Ladder

FBD:
[ IN1 (sensor) ] ──────────────────────── [ OUT1 (bobina relé) ]

LADDER:
| | [ IN1 ] | ( OUT1 ) | |
| | (sensor) | (bobina relé) |

Cuando sensor activa: IN1=1 → OUT1=1 → relé energiza → ventilador ON Cuando sensor desactiva: IN1=0 → OUT1=0 → relé desenergiza → ventilador OFF

✅ Compatibilidad: conversión FBD → Ladder PERFECTA (Level 1)

## 5. Ejercicios

- El sensor es PNP. Describir el cableado completo. ¿El programa FBD cambia? (Respuesta: el programa no cambia, solo el cableado.) - Agregar una lámpara piloto 24V en OUT2 que encienda cuando el ventilador esté en marcha. Escribir el FBD y el Ladder. (Pista: OUT2 = IN1, igual que OUT1.) - [Desafío] Usar NOT en OUT2 para una lámpara que encienda cuando el ventilador está

APAGADO. Dibujar el FBD y el Ladder.

Pág. 15 | IEC 61131-3 FBD | ESP32 | RS-485 / Modbus RTU | v5 · 2026

# Capítulo 2 — Control Arranque / Paro y Memoria

El circuito de arranque/paro es el más usado en automatización industrial. Permite que un motor o

## una carga queden activados aunque el operario suelte el botón de arranque. Esto se llama automantenimiento o memoria de enclavamiento. El Capítulo 2 introduce tres bloques nuevos

esenciales: SR, R_TRIG y los detectores de flanco.

# Concepto previo fundamental: el bloque R_TRIG (detector de flanco)

Antes de ver el arranque/paro, necesitamos entender el bloque R_TRIG porque aparece en varios ejemplos de este capítulo y es uno de los bloques más importantes del PLC.

## ¿Qué es un flanco?

## Un flanco es el MOMENTO EXACTO en que una señal cambia de estado:

- Flanco ascendente (Rising Edge): | la señal pasa de 0 → 1 | (el instante en que
algo se enciende)
- Flanco descendente (Falling Edge): la señal pasa de 1 → 0 (el instante en que algo se apaga)

## El PLC actualiza sus entradas cada 10ms. Si mantenés presionado un pulsador 500ms, el PLC ve IN1=1 durante 50 ciclos de scan. Sin R_TRIG, esa señal actúa 50 veces. Con

R_TRIG, actúa exactamente UNA sola vez: en el primer ciclo en que detecta 0→1.

Señal de entrada (IN1):
0V | ────────────┐ | ┌────────────────
| │ | │
24V | └───────────┘
| ↑ flanco | ↑ flanco
| ascendente | descendente
| (R_TRIG) | (F_TRIG)

Salida del R_TRIG (1 ciclo = 10ms):
0 ─────────┐ ┌──────────────────────────
│ │
1 | └─┘
| ← 10ms →
Solo un pulso brevísimo al inicio del flanco ascendente.
Bloque | Nombre | Detecta | Genera pulso cuando...
R_TRIG | Rising Edge Trigger | Flanco ascendente | La señal pasa de 0 a 1

## (botón se presiona)

F_TRIG | Falling Edge Trigger | Flanco descendente | La señal pasa de 1 a 0

## (botón se suelta)

## R_TRIG en Ladder

En Ladder, el flanco ascendente se indica con [P] (Positive Transition):

| | [P IN1] | ( OUT ) | |
| | Contacto flanco ascendente | Bobina | |

[P] conduce por exactamente 1 ciclo de scan al detectar 0→1.

Pág. 16 | IEC 61131-3 FBD | ESP32 | RS-485 / Modbus RTU | v5 · 2026

✅ Compatibilidad R_TRIG: conversión FBD → Ladder PERFECTA (Level 1)

# Ejemplo 2.1 — Arranque/Paro con automantenimiento (bloque SR)

## 1. Situación práctica

Una bomba de agua debe arrancar al presionar un botón verde y detenerse al presionar un botón rojo. La bomba debe mantenerse funcionando aunque el operario suelte el botón de arranque. En la industria nadie sostiene un botón durante horas.

## ¿Por qué no alcanza con IN1 → OUT1?

## Con el programa del Capítulo 1 (IN1 → OUT1), la bomba funciona SOLO mientras se mantiene el botón presionado. Al soltarlo, se apaga. Para que quede encendida por sí sola

necesitamos un bloque con MEMORIA: el bloque SR.

## 2. El bloque SR — memoria biestable

El bloque SR es una memoria que recuerda su estado aunque las entradas vuelvan a 0. Tiene dos

## entradas y una salida:

Terminal | Nombre | Función
S | Set | Cuando S=1: la salida Q pasa a 1 y SE MANTIENE en 1, aunque S vuelva a 0.
R | Reset | Cuando R=1: la salida Q pasa a 0 y SE MANTIENE en 0, aunque R vuelva a 0.
Q | Output | El estado de la memoria. Cambia solo cuando S o R se activan.
S | R | Q (salida) | Estado y descripción
0 | 0 | Sin cambio | Memoria: Q mantiene el valor que tenía antes.
1 | 0 | 1 | SET activo: la salida pasa a 1 y queda en 1.
0 | 1 | 0 | RESET activo: la salida pasa a 0 y queda en 0.
1 | 1 | 1 | Conflicto: en el bloque SR, SET tiene prioridad → Q=1.

## El SR equivale al circuito de automantenimiento con relés

En la electromecánica tradicional, el automantenimiento se logra con un contacto auxiliar NA

## del contactor en paralelo con el botón de arranque: al energizar el contactor, su propio contacto lo mantiene energizado. El bloque SR hace exactamente lo mismo, pero en

software.

Pág. 17 | IEC 61131-3 FBD | ESP32 | RS-485 / Modbus RTU | v5 · 2026

## 3. Esquema de conexión

+24V ──[PULS. NA verde]── IN1 | OUT1 ──[BOBINA CONTACTOR]──┐
+24V ──[PULS. NC rojo ]── IN2 | COM_OUT ───────────────────┘── 0V

0V ──────────────────── COM_IN

Funcionamiento del pulsador NC rojo (botón de paro):
→ En reposo: NC cerrado → IN2 = 1
→ Al presionar: NC abre → IN2 = 0
→ Fail-safe: cable cortado → IN2 = 0 → RESET → motor para
Borne | Dispositivo | Función
IN1 | Pulsador NA verde | Señal de arranque. Momentánea. Activa el SET del SR.
IN2 | Pulsador NC rojo | Señal de paro. NC: en reposo IN2=1. Al presionar: IN2=0.
OUT1 | Bobina del contactor | Activa el motor a través del contactor.

## 4. Diagrama FBD

S ┌───────────┐
[IN1] ────────┤ | | │Q
│ | SR | ├──────────────────── [OUT1]
[IN2] ────────┤ | S dom. | │
R └───────────┘

IN1 (ARRANQUE NA) ── S ──► SR ── Q ──────────────► OUT1 (MOTOR)
IN2 (PARO NC) | ── R ──►

Pasos en el editor FBD:
1. Agregar IN1 (verde) desde la paleta
2. Agregar IN2 (verde) desde la paleta
3. Agregar SR (sección Mem/Flanco) desde la paleta
4. Agregar OUT1 (naranja) desde la paleta
5. Conectar IN1 → entrada S del SR
6. Conectar IN2 → entrada R del SR
7. Conectar salida Q del SR → entrada de OUT1
8. GUARDAR → RUN

## 5. Diagrama Ladder equivalente

El Ladder del arranque/paro es uno de los diagramas más clásicos en automatización industrial.

## Se usa en todo el mundo:

Rung 1 — Arranque con automantenimiento:
| | [ IN1 ] | [ IN2 ] | (S OUT1 ) | |
| | Arranque | Paro | Bobina SET | |
| | (NA) | (NC) | (memoria) | |
Rung 2 — Paro:
| | [/IN2 ] | | (R OUT1 ) | |
| | Paro | | Bobina RESET | |
| | (NC inv.) | | (memoria) | |

Nota: en muchos PLCs el SR se implementa con bobinas (S) y (R). El resultado es idéntico al bloque SR del FBD.

✅ Compatibilidad: conversión FBD → Ladder PERFECTA (Level 1)

Pág. 18 | IEC 61131-3 FBD | ESP32 | RS-485 / Modbus RTU | v5 · 2026

## 6. Tabla de estados

Evento | IN1 (arranque
NA)

## IN2 (paro

NC) | Q del SR | OUT1 (motor) | Descripción

## Inicio (PLC

encendido) | 0 | 1 | 0 | 0

Motor parado.

## Esperando

arranque.

## Presionar IN1

brevemente | 1→0 | 1 | 0→1 | 0→1 | Motor ARRANCA y se MANTIENE.
Soltar IN1 | 0 | 1 | 1 | 1 | Motor sigue encendido. Q se mantiene.
Presionar IN2 | 0 o 1 | 1→0 | 1→0 | 1→0 | Motor PARA y se MANTIENE parado.
Soltar IN2 | 0 | 0→1 | 0 | 0 | Motor sigue parado.
Cable IN2 cortado | cualquiera | 0 (falla) | →0 | →0 | FAIL-SAFE: motor para automáticamente.

## 7. Prueba paso a paso

13. Cargar el programa. Activar RUN.

## 14. Presionar IN1 brevemente (menos de 1 segundo) → OUT1 = 1. Soltar IN1: OUT1 sigue en

1. ✓ Automantenimiento funcionando.

## 15. Presionar IN2 brevemente → OUT1 = 0. Soltar IN2: OUT1 sigue en 0. ✓ 16. Presionar IN1 nuevamente → OUT1 vuelve a 1. ✓

17. Desconectar físicamente el cable de IN2 → OUT1 debe ir a 0. ✓ Fail-safe verificado.
18. En el Monitor: observar Q del SR cambiando en tiempo real.

## 8. Ejercicios

- ¿Qué pasa si IN2 está NC y el cable se corta? Simular desconectando el cable de IN2. ¿El

## motor para o sigue? Explicar por qué (respuesta: para, porque IN2 cae a 0 → R activo →

RESET).

## - Agregar una lámpara piloto verde en OUT2 que indique "motor en marcha" (conectar

OUT2 igual que OUT1). Dibujar el FBD y el Ladder.

## - [Desafío] Agregar una lámpara roja en OUT3 que encienda cuando el motor esté

PARADO. Pista: usar un NOT entre Q del SR y OUT3.

# Ejemplo 2.2 — Toggle: un pulsador alterna entre encendido y apagado

## 1. Situación práctica

Un solo pulsador debe alternar entre encender y apagar una lámpara. Primera presión: enciende. Segunda presión: apaga. Tercera presión: enciende. Y así sucesivamente. Este circuito se llama "toggle" o "interruptor biestable".

Pág. 19 | IEC 61131-3 FBD | ESP32 | RS-485 / Modbus RTU | v5 · 2026

## 2. ¿Por qué no se puede hacer con XOR directo?

Una idea intuitiva sería conectar la salida de vuelta a la entrada del XOR. Pero esto tiene un problema fundamental: si el pulsador está presionado durante varios ciclos de scan (por ejemplo

## 300ms = 30 ciclos), el XOR cambiaría 30 veces en esos 300ms. La lámpara terminaría en un

estado impredecible.

## La solución es el bloque R_TRIG: convierte la señal continua del pulsador en un pulso de

exactamente 1 ciclo de scan (10ms). Así, sin importar cuánto tiempo se sostiene el pulsador, el toggle cambia exactamente UNA vez.

## 3. Lógica correcta del toggle con 7 nodos

## Lógica verificada — Toggle con R_TRIG y SR

## El toggle se implementa con 7 bloques (nodos). La clave está en que el SR se pone a 1 o a 0 dependiendo de su estado actual:

S = R_TRIG AND NOT(Q) | → Set: solo si hay flanco Y el SR estaba apagado (Q=0)
R = R_TRIG AND Q | → Reset: solo si hay flanco Y el SR estaba encendido (Q=1)

Cada presión del pulsador genera un flanco ascendente en R_TRIG.
Si Q era 0 → S=1, R=0 → SR hace SET → Q pasa a 1 → lámpara enciende.
Si Q era 1 → S=0, R=1 → SR hace RESET → Q pasa a 0 → lámpara apaga.
Si Q era 0 y flanco=0 → S=0, R=0 → SR no cambia → lámpara sigue apagada.

## 4. Los 7 nodos del toggle — diagrama FBD completo

Nodo 1: IN2 (entrada del pulsador)
Nodo 2: R_TRIG (detector de flanco ascendente) Nodo 3: NOT (invierte Q del SR)
Nodo 4: AND_SET (flanco AND NOT Q → genera señal S) Nodo 5: AND_RST (flanco AND Q → genera señal R) Nodo 6: SR (memoria biestable)
Nodo 7: OUT1 (salida a la lámpara)

┌─────────┐
┌────┤ | NOT | ├────────────A─┐
│ | └─────────┘ | │
┌──────┐ | ┌───────┴──┐ | ┌───────────┴───┐
│ IN2 ├──┤ R_TRIG | ├──────────────┤ AND_SET (A,B)├──S─┐
└──────┘ └───────┬──┘ | └────────┤ | B│ | │ ┌──────┐ | ┌──────┐
│ | └───────────────┘ | ├─┤ SR | ├──┤ OUT1 │
│ | ┌───────────────┐ | │ └──┬───┘ └──────┘
└─────────────────┤ AND_RST (A,B)├──R─┘ | │
| Q ──┤ | B│ | │Q
| └───┤ | │ | │
└───────────────┘ | │
↑ | │
└──────────────────┘

(realimentación de Q)

## 5. Pasos en el editor FBD — instrucciones detalladas

19. [Nodo 1] Agregar bloque IN2 desde la paleta (verde).

## 20. [Nodo 2] Agregar bloque R_TRIG (sección Mem/Flanco). Conectar: salida de IN2 →

entrada IN del R_TRIG.
21. [Nodo 3] Agregar bloque NOT (sección Lógica). La entrada de este NOT se conectará a la salida Q del SR (paso 9).

Pág. 20 | IEC 61131-3 FBD | ESP32 | RS-485 / Modbus RTU | v5 · 2026
22. [Nodo 4] Agregar bloque AND — este será el AND_SET. Tiene dos entradas: A y B.

## 23. [Nodo 5] Agregar un segundo bloque AND — este será el AND_RST. También tiene dos

entradas: A y B.
24. [Nodo 6] Agregar bloque SR (sección Mem/Flanco).
25. [Nodo 7] Agregar bloque OUT1 (naranja).
26. [Conexiones] Conectar salida de R_TRIG → entrada A de AND_SET.
27. [Conexiones] Conectar salida de R_TRIG → entrada A de AND_RST.
28. [Conexiones] Conectar salida de NOT → entrada B de AND_SET.
29. [Conexiones] Conectar salida Q del SR → entrada B de AND_RST.
30. [Conexiones] Conectar salida Q del SR → entrada del NOT (realimentación).
31. [Conexiones] Conectar salida de AND_SET → entrada S del SR.
32. [Conexiones] Conectar salida de AND_RST → entrada R del SR.
33. [Conexiones] Conectar salida Q del SR → entrada de OUT1.
34. GUARDAR → RUN.

## ⚠ Sobre la realimentación (retroalimentación)

La conexión de Q del SR de vuelta a sus propias entradas (vía NOT y AND_RST) se llama realimentación. El PLC-CORE-MDE usa el modelo IEC 61131-3 con snapshot: todos los bloques leen el estado del CICLO ANTERIOR. Esto significa que la realimentación funciona correctamente: en el ciclo N se calcula el nuevo Q, y en el ciclo N+1 ese Q ya está

disponible para los AND.

## 6. Diagrama Ladder equivalente

Rung 1 — SET del toggle (encender si estaba apagado):
| | [P IN2] | [/ OUT1] | (S OUT1) | |
| Flanco ascend. | OUT1 estaba 0 | Bobina SET | |
| | (R_TRIG) | (NOT Q) | (enciende) | |

Rung 2 — RESET del toggle (apagar si estaba encendido):
| | [P IN2] | [ OUT1] | (R OUT1) | |
| Flanco ascend. | OUT1 estaba 1 | Bobina RESET | |
| | (R_TRIG) | (Q) | (apaga) | |

Lectura Rung 1: "Si hay flanco en IN2 Y OUT1 estaba apagado → encender OUT1" Lectura Rung 2: "Si hay flanco en IN2 Y OUT1 estaba encendido → apagar OUT1"

✅ Compatibilidad: conversión FBD → Ladder PERFECTA (Level 1)

## 7. Tabla de estados — secuencia de presiones

Presión N° | Evento | R_TRIG | (antes) Q | NOT(Q) | AND_SET | AND_RST | Q (después) | OUT1
Inicio | PLC encendido | - | 0 | 1 | 0 | 0 | 0 | 0 (apagada)

1ª

## presión

## Flanco

0→1 en
IN2
1 | 0 | 1 | 1 | 0 | 1

1

## (enciende)

Pág. 21 | IEC 61131-3 FBD | ESP32 | RS-485 / Modbus RTU | v5 · 2026
Presión N° | Evento | R_TRIG | (antes) Q | NOT(Q) | AND_SET | AND_RST | Q (después) | OUT1
1ª suelta | Flanco 1→0 en IN2 | 0 | 1 | 0 | 0 | 0 | 1 | 1 (sigue encendida)
2ª presión | Flanco 0→1 en IN2 | 1 | 1 | 0 | 0 | 1 | 0 | 0 (apaga)
2ª suelta | Flanco 1→0 en IN2 | 0 | 0 | 1 | 0 | 0 | 0 | 0 (sigue apagada)
3ª presión | Flanco 0→1 en IN2 | 1 | 0 | 1 | 1 | 0 | 1 | 1 (enciende)

## 8. Prueba paso a paso

35. Cargar el programa. Activar RUN.
36. Presionar IN2 brevemente → OUT1 debe pasar a 1 (lámpara enciende).
37. Soltar IN2 → OUT1 sigue en 1.
38. Presionar IN2 brevemente → OUT1 debe pasar a 0 (lámpara apaga).
39. Soltar IN2 → OUT1 sigue en 0.
40. Repetir: cada presión debe alternar el estado. Verificar en el Monitor.

## 41. Mantener presionado IN2 durante 2-3 segundos: el estado debe cambiar UNA sola vez

(verificar efecto del R_TRIG).

## 9. Ejercicios

- Implementar el toggle y verificar que cada presión alterna el estado. ¿Qué pasa si se quita

## el bloque R_TRIG y se conecta IN2 directamente a los AND? Probar y observar el

comportamiento.

## - Agregar un LED indicador en OUT2 que encienda cuando OUT1 esté APAGADO (usar

NOT entre Q del SR y OUT2).

## - [Desafío] Modificar el toggle para que use IN1 en lugar de IN2. Verificar que el

comportamiento es idéntico.

# Ejemplo 2.3 — Parada de emergencia NC

## 1. Situación práctica

## Una máquina tiene un botón de parada de emergencia tipo hongo (mushroom head) que debe

detener todos los motores inmediatamente. El botón es NC y tiene enclavamiento mecánico: al presionarlo queda bloqueado y solo se desbloquea girándolo.

Pág. 22 | IEC 61131-3 FBD | ESP32 | RS-485 / Modbus RTU | v5 · 2026

## 2. Esquema de conexión

+24V ──[EMERGENCIA NC]──[PARO NC]──[ARRANQUE NA]── IN1 0V ───────────────────────────────────────────── COM_IN IN2: libre (o segundo reset supervisado)

Cadena de seguridad en serie:
→ Emergencia OK (no presionada): NC cerrado → +24V llega a la cadena → Emergencia presionada: NC abre → IN1 = 0 → no se puede hacer SET → Cable cortado en cualquier punto: IN1 = 0 → fail-safe

El ARRANQUE NA está al final: solo si TODOS los NC están cerrados y se presiona el NA → IN1 = 1 → posible SET del SR.

## 3. FBD y Ladder

FBD:
S ┌───────────┐
[IN1] ────────┤ | | │Q
│ | SR | ├────────────────── [OUT1] | (Motor/Máquina)
[IN2] ────────┤ | S dom. | │
R └───────────┘

IN1: cadena serie [EMERGENCIA NC]─[PARO NC]─[ARRANQUE NA] IN2: puede usarse para reset supervisado después de emergencia

LADDER:
| | [ IN1 ] | (S OUT1 ) | |
| (cadena NC+NA) | Bobina SET | |
| | [/ IN2 ] | (R OUT1 ) | |
| | (reset NC) | Bobina RESET | |

✅ Compatibilidad: conversión FBD → Ladder PERFECTA (Level 1)

## 4. Tabla de estados

Situación | IN1 | Efecto en SR | OUT1 (máquina) | Seguridad
Todo normal, máquina parada | 0 | S=0 → sin cambio | 0 | Normal
Se presiona ARRANQUE | 1 | S=1 → SET → Q=1 | 1 | Motor en marcha
Se suelta ARRANQUE | 0 | Sin cambio | 1 | Automantenimiento
Se presiona PARO NC | 0 | S=0 → no puede hacer
| | SET | 1→0 (si R
| | | activo) | Paro normal
Se presiona EMERGENCIA | 0
| (forzado) | S=0 → no puede
| | arrancar | →0 | Paro de
| | | | emergencia
Cable de IN1 cortado | 0 | S=0 permanente | 0 | FAIL-SAFE
| | | | activado

## 5. Ejercicios

## - Conectar físicamente la cadena: EMERGENCIA NC en serie con PARO NC en serie con

ARRANQUE NA. Verificar que cada elemento puede cortar el circuito.

## - ¿Qué pasa si se intenta arrancar mientras la emergencia está presionada? ¿Por qué el

motor no puede arrancar? (respuesta: IN1=0 → S=0 → no hay SET).

Pág. 23 | IEC 61131-3 FBD | ESP32 | RS-485 / Modbus RTU | v5 · 2026

## - [Desafío] Agregar una lámpara en OUT2 que parpadee (BLINK) indicando que hay una emergencia activa. ¿Cómo saber si la emergencia está activa desde el PLC?

# Ejemplo 2.4 — Enclavamiento de dos motores (Interlock)

## 1. Situación práctica

## Dos motores M1 y M2 no pueden funcionar simultáneamente (por ejemplo, dos bombas en el

mismo circuito hidráulico). Si M1 está en marcha, M2 no puede arrancar. Si M2 arranca, M1 debe parar. Esto se llama enclavamiento o interlock.

## 2. Lógica del interlock

La condición de habilitación de M2 es que M1 esté parado: habilitar M2 = NOT(Q1). Si M1 está en

## marcha (Q1=1), NOT(Q1)=0, y M2 no puede arrancar. Si M2 arranca (Q2=1), usamos Q2 como

RESET de M1.

## 3. FBD

Motor M1:
S ┌───────────┐
[IN1] ────────┤ | | │Q1
│ | SR1 | ├──────────────────── [OUT1] | (Motor M1)
[IN2] ────────┤ | | │
Q2 ─────────┤R | | │
R └───────────┘

Motor M2 (enclavado con M1):
S ┌───────────┐
[IN1]──[NOT]──┤ | │Q2
(NOT | │ | SR2 | ├──────────────────── [OUT2] | (Motor M2)
Q1) | │ | | │
Q1 ───────────┤R | │
R └───────────┘

Explicación:
M2 solo puede arrancar si NOT(Q1)=1, es decir, si M1 está parado. Si M1 está en marcha (Q1=1): el S de SR2 nunca puede ser 1.
Si M2 arranca (Q2=1): Q2 alimenta el R de SR1 → M1 para.

## 4. Ladder

Rung 1 — Arranque M1 (bloqueado si M2 está en marcha):
| | [ IN1 ] | [/ OUT2] | [ IN2/] | (S OUT1 ) | |
| | Arranque | M2 parado | Paro | Motor M1 | |

Rung 2 — Paro M1:
| | [/ IN2 ] | [ OUT2 ] | | (R OUT1 ) | |
| | Paro | M2 corre | Motor M1 | |

Rung 3 — Arranque M2 (bloqueado si M1 está en marcha):
| | [ IN1 ] | [/ OUT1] | | (S OUT2 ) | |
| | Arranque | M1 parado | | Motor M2 | |

Rung 4 — Paro M2:
| | [/ IN2 ] | [ OUT1 ] | | (R OUT2 ) | |
| | Paro | M1 corre | Motor M2 | |

✅ Compatibilidad: conversión FBD → Ladder PERFECTA (Level 1)

Pág. 24 | IEC 61131-3 FBD | ESP32 | RS-485 / Modbus RTU | v5 · 2026

## 5. Tabla de estados

Situación | Q1 (M1) | Q2 (M2) | Descripción
Inicio | 0 | 0 | Ambos motores parados.
Se arranca M1 | 1 | 0 | M1 en marcha. M2 bloqueado.

## Intento de arrancar M2 (M1 en

marcha) | 1 | 0 (bloqueado) | M2 no arranca. NOT(Q1)=0 bloquea el SET de SR2.
Se para M1 | 0 | 0 | M1 parado. M2 ya puede arrancar.
Se arranca M2 (M1 parado) | 0 | 1 | M2 en marcha. Q2 hace RESET de SR1 → si M1 corría, para.
Ambos intento simultáneo | 0 | 1 | Solo uno puede quedar en marcha. El SR determina cuál.

## 6. Ejercicios

## - Implementar el interlock y verificar que no es posible encender ambos motores

simultáneamente.

## - Agregar lámparas indicadoras: OUT3 = verde M1 en marcha, OUT4 = verde M2 en marcha. (Nota: con 4 salidas, quizás no alcancen. Discutir cómo resolverlo con módulo RS-485, Cap. 9.)

- [Desafío] En la industria, el interlock también se implementa con contactos auxiliares NC

## del contactor en el circuito de mando (enclavamiento eléctrico). ¿Por qué se recomienda tener AMBOS tipos de enclavamiento (eléctrico + lógico del PLC)?

Pág. 25 | IEC 61131-3 FBD | ESP32 | RS-485 / Modbus RTU | v5 · 2026

# Referencia: Símbolos Ladder usados en este manual

Símbolo | Nombre | Función | Equivalente FBD
[ ] | Contacto NA | Conduce cuando la variable =
1
| | | Salida directa de un bloque
[/] | Contacto NC | Conduce cuando la variable =
0
| | | Bloque NOT
[P] | Flanco ascendente | Conduce 1 ciclo al detectar
0→1 | Bloque R_TRIG
[N] | Flanco
| descendente | Conduce 1 ciclo al detectar
1→0 | Bloque F_TRIG
( ) | Bobina salida | Activa la variable cuando el
| | rung conduce | Bloque OUTx
(S) | Bobina SET | Pone la variable a 1 y la
mantiene | Entrada S del bloque SR
(R) | Bobina RESET | Pone la variable a 0 y la
mantiene | Entrada R del bloque SR
[TON] | Timer ON-Delay | Bloque de tiempo con retardo
al ON | Bloque TON
[CTU] | Contador
| ascendente | Cuenta flancos ascendentes | Bloque CTU

## Niveles de compatibilidad FBD → Ladder

✅ Level 1 (conversión perfecta): AND, OR, NOT, SR, RS, TON, TOF, TP, CTU, CTD, R_TRIG, F_TRIG
⚠ Level 2 (aproximado): | XOR, CMP, BLINK — se pueden representar con más
rungs
❌ Level 3 (no convertible): | AI1, SCALE, PWM — requieren funciones especiales

Cuando un programa contiene bloques Level 3, el editor indicará que no se puede mostrar el Ladder equivalente. En esos casos, el manual lo indica explícitamente.

# Capítulo 3 — Memoria y Enclavamiento

En el Capítulo 2 aprendimos el bloque SR para arranque/paro. En este capítulo profundizamos en

## los dos bloques de memoria del PLC: SR (prioridad de Set) y RS (prioridad de Reset). La

elección entre uno y otro no es arbitraria: depende de cuál señal debe tener prioridad en una situación de conflicto. También veremos el bloque F_TRIG (detector de flanco descendente) y aplicaciones de memoria más complejas.

# SR vs RS — La diferencia crítica

## Ambos bloques son memorias biestables: guardan su estado hasta que reciben una orden de

cambio. La única diferencia es qué pasa cuando S y R están activos al mismo tiempo (situación de

## conflicto):

| Bloque SR | Bloque RS
Prioridad | SET domina (Q=1 si S=1 y R=1) | RESET domina (Q=0 si S=1 y R=1)

Pág. 26 | IEC 61131-3 FBD | ESP32 | RS-485 / Modbus RTU | v5 · 2026
| Bloque SR | Bloque RS
Cuándo usar | Arranque tiene prioridad sobre parada | Parada / seguridad tiene prioridad absoluta
Ejemplo industrial | Sistema de llenado: preferir llenar ante conflicto | Botón de emergencia: parar siempre ante conflicto
Norma IEC | SR: priority set | RS: priority reset

## Regla de diseño seguro

## En sistemas de seguridad (emergencias, protecciones, enclavamientos) siempre usar RS o lógica equivalente con RESET dominante. El estado de parada es el estado seguro: ante

cualquier conflicto, el sistema debe parar.

# Ejemplo 3.1 — Bloque SR: prioridad de Set con indicación de estado

## 1. Situación práctica

## Un sistema de señalización tiene dos lámparas: una verde (marcha) y una roja (parado). El

operario arranca con IN1 y para con IN2. Se usa SR. Las dos lámparas siempre están en estados opuestos: cuando una enciende, la otra apaga.

## 2. Esquema de conexión

+24V ──[PULS. NA verde]── IN1 | OUT1 ──[LÁMPARA VERDE]──┐
+24V ──[PULS. NC rojo ]── IN2 | OUT2 ──[LÁMPARA ROJA ]──┴── +24V
0V ──────────────────── COM_IN | COM_OUT ───────────────────── 0V

OUT1 = Q (enciende cuando el SR está en 1 → "en marcha")
OUT2 = NOT Q (enciende cuando el SR está en 0 → "parado")

## 3. Tabla de verdad SR

S (IN1) | R (IN2) | Q actual | Q siguiente | Estado
0 | 0 | 0 | 0 | Memoria: mantiene estado previo (parado)
0 | 0 | 1 | 1 | Memoria: mantiene estado previo (en marcha)
1 | 0 | 0 | 1 | SET activo: pasa a 1 (arranca)
0 | 1 | 1 | 0 | RESET activo: pasa a 0 (para)
1 | 1 | 0 | 1 | Conflicto: SR → SET gana → Q=1
1 | 1 | 1 | 1 | Conflicto: SR → SET gana → Q=1 (sin cambio)

Pág. 27 | IEC 61131-3 FBD | ESP32 | RS-485 / Modbus RTU | v5 · 2026

## 4. Diagrama FBD

S ┌───────────┐
[IN1] ────────┤ | | │Q ──────────────────────────── [OUT1] | (Verde: en

marcha)
│ | SR | │
[IN2] ────────┤ | S dom. | │Q ── [NOT] ─────────────────── [OUT2] | (Roja: parado)
R └───────────┘

La salida Q se usa dos veces:
→ Directamente a OUT1: cuando Q=1 (en marcha), verde enciende
→ Pasando por NOT a OUT2: cuando Q=0 (parado), NOT(Q)=1, roja enciende

Resultado: las dos lámparas SIEMPRE tienen estados opuestos.

## 5. Diagrama Ladder

Rung 1 — SET (arrancar):
| | [ IN1 ] | [ IN2 ] | (S OUT1 ) | |
| | Arranque | Paro | Bobina SET | |

Rung 2 — RESET (parar):
| | [/ IN2 ] | (R OUT1 ) | |
| | Paro NC inv. | Bobina RESET | |

Rung 3 — Lámpara roja (estado opuesto):
| | [/ OUT1] | ( OUT2 | ) | |
| | OUT1 apagado | Lámpara roja | |

✅ Compatibilidad: Level 1 — conversión FBD → Ladder perfecta

## 6. Tabla de estados

Evento | IN1 | IN2 | Q (SR) | OUT1 (verde) | OUT2 (roja) | Estado visual
Inicio | 0 | 1 | 0 | 0 | 1 | Roja encendida → sistema parado
Presionar IN1 | 1 | 1 | 1 | 1 | 0

## Verde encendida → en marcha

Soltar IN1 | 0 | 1 | 1 | 1 | 0

## Verde sigue → automantenimiento

Presionar IN2 | 0 | 0 | 0 | 0 | 1

## Roja encendida → sistema parado

## IN1=1 e IN2=0

(conflicto) | 1 | 0 | 1 | 1 | 0

## SET gana en SR → verde encendida

## 7. Prueba paso a paso

42. Cargar programa y activar RUN.
43. Verificar estado inicial: OUT1=0 (verde apagada), OUT2=1 (roja encendida).
44. Presionar IN1 → OUT1=1 (verde), OUT2=0 (roja apaga). Soltar: estado se mantiene.
45. Presionar IN2 → OUT1=0, OUT2=1. Soltar: estado se mantiene.
46. Verificar conflicto: presionar IN1 e IN2 simultáneamente → OUT1=1 (SET gana en SR).

## 8. Ejercicios

Pág. 28 | IEC 61131-3 FBD | ESP32 | RS-485 / Modbus RTU | v5 · 2026

## - Verificar el comportamiento cuando S y R se activan simultáneamente. ¿Cuál domina?

Registrar el resultado en una tabla.

## - Cambiar el bloque SR por RS (sin cambiar ninguna conexión). Repetir la prueba de conflicto. ¿Qué cambia? - [Desafío] ¿Hay alguna situación en la que las dos lámparas puedan estar apagadas al

mismo tiempo con este circuito? Analizar la tabla de estados y responder.

# Ejemplo 3.2 — Bloque RS: prioridad de Reset para sistemas de seguridad

## 1. Situación práctica

Una prensa industrial tiene un botón de arranque (IN1, NA) y un botón de paro de emergencia (IN2, NC). El diseño de seguridad exige que si se presiona el botón de emergencia, la prensa se detenga SIEMPRE, incluso si alguien está apretando el arranque al mismo tiempo. Esto requiere RS (prioridad de Reset).

## 2. Tabla de verdad RS

S (IN1) | R (IN2) | Q actual | Q siguiente | Estado
0 | 0 | 0 | 0 | Memoria: mantiene estado previo (parado)
0 | 0 | 1 | 1 | Memoria: mantiene estado previo (en marcha)
1 | 0 | 0 | 1 | SET activo: pasa a 1 (arranca)
0 | 1 | 1 | 0 | RESET activo: pasa a 0 (para)
1 | 1 | 0 | 0 | Conflicto: RS → RESET gana → Q=0 (PARADA)
1 | 1 | 1 | 0 | Conflicto: RS → RESET gana → Q=0 (PARADA)

## 3. FBD y Ladder

FBD:
S ┌───────────┐
[IN1] ────────┤ | | │Q
│ | RS | ├───────────────────── [OUT1] | (Prensa)
[IN2] ────────┤ | R dom. | │
R └───────────┘

LADDER:
Rung 1 — Arranque (bloqueado si IN2=0):
| | [ IN1 ] | [ IN2 ] | (S OUT1 ) | |
| | Arranque | Habili. | Bobina SET | |

Rung 2 — Parada con prioridad:
| | [/ IN2 ] | (R OUT1 ) | |
| | Emergencia | | Bobina RESET | |

Diferencia clave vs SR:
En SR, el Rung 1 tiene "[ IN2 ]" (IN2=1 habilita arranque). En RS con prioridad real, el Rung 2 resetea SIEMPRE que IN2=0, sin importar si IN1 también está activo.

✅ Compatibilidad: Level 1 — conversión FBD → Ladder perfecta

Pág. 29 | IEC 61131-3 FBD | ESP32 | RS-485 / Modbus RTU | v5 · 2026

## 4. Comparación directa SR vs RS con el mismo circuito

Situación de prueba | SR (Set domina) | RS (Reset
| | domina) | ¿Cuál es más seguro?
IN1=0, IN2=1 (reposo) | Q=0 (parado) | Q=0 (parado) | Igual

## IN1=1, IN2=1 (arranque

normal) | Q=1 (arranca) | Q=1 (arranca) | Igual
IN1=0, IN2=0 (paro normal) | Q=0 (para) | Q=0 (para) | Igual
IN1=1, IN2=0 (conflicto) | Q=1 (sigue en marcha) | Q=0 (PARA) | RS es más seguro
Cable IN2 cortado | Puede arrancar (S activo) | No puede arrancar (R permanente) | RS es más seguro

## 5. Ejercicios

## - Implementar SR y RS con los mismos botones. Probar el conflicto (presionar IN1 e IN2

simultáneamente). Registrar qué pasa con cada bloque.

## - ¿En qué aplicación de un ascensor usarías RS en lugar de SR? Justificar con el concepto

de prioridad de parada.
- [Desafío] En algunos diseños se usa un RS para el arranque y un circuito NC en serie en la entrada para la emergencia. ¿Es redundante? ¿O agrega seguridad? Discutir.

# Ejemplo 3.3 — Alarma con memoria: Set permanente hasta reconocimiento

## 1. Situación práctica

Una lámpara de alarma debe encender al detectar una condición (por ejemplo, temperatura alta) y permanecer encendida aunque la condición desaparezca. El operario debe reconocer la alarma presionando un botón (reset manual). Mientras no reconozca, la alarma sigue visible.

## 2. Esquema de conexión

+24V ──[SENSOR ALARMA (NA)]── IN1 | OUT1 ──[LÁMPARA ALARMA]──┐
+24V ──[RESET OPERARIO (NA)]─ IN2 | OUT2 ──[BUZZER | ]──┴── +24V
0V ──────────────────────── COM_IN | COM_OUT ───────────────────── 0V

IN1: sensor o condición de alarma (activo brevemente o sostenido) IN2: pulsador de reconocimiento del operario (momentáneo NA)
OUT1: lámpara de alarma (permanece hasta que operario presiona IN2) OUT2: buzzer de alarma (igual comportamiento que OUT1)

Pág. 30 | IEC 61131-3 FBD | ESP32 | RS-485 / Modbus RTU | v5 · 2026

## 3. Lógica y FBD

La clave es que IN1 activa el SET del SR. Aunque IN1 vuelva a 0 (sensor desaparece), el SR mantiene Q=1. El operario debe presionar IN2 para hacer RESET.

S ┌───────────┐
[IN1] ────────┤ | | │Q ──────────────────────────── [OUT1] | (Lámpara)
│ | SR | │
[IN2] ────────┤ | S dom. | │Q ──────────────────────────── [OUT2] | (Buzzer)
R └───────────┘

IN1 (sensor) activo 1 ciclo → Q pasa a 1 → alarma ON. IN1 vuelve a 0 → Q sigue en 1 (memoria).
IN2 (operario) presionado → Q pasa a 0 → alarma OFF.

DIFERENCIA con Ejemplo 2.1 (arranque/paro):
→ En 2.1: IN2 es NC (en reposo = 1) → fail-safe para motor.
→ Aquí: IN2 es NA (en reposo = 0) → el operario elige cuándo reconocer.
La elección NA/NC depende del propósito: para alarmas, el reset es intencional.

## 4. Variante con BLINK: alarma parpadeante

Para hacer la alarma más visible, se puede intercalar un BLINK entre la salida Q del SR y OUT1.

## La lámpara parpadea mientras la alarma está activa, en lugar de brillar fija:

S ┌───────────┐ | Q | EN ┌────────────┐ | Q
[IN1] ────────┤ | SR | ├─────────┤ | BLINK | ├──── [OUT1] | (Parpadeo)
[IN2] ────────┤ | │ | │ | T=500ms | │
R └───────────┘ | └────────────┘

T=500ms → la lámpara alterna 500ms ON / 500ms OFF → 1 Hz.
Alarma parpadeante: más llamativa que luz fija.
Cuando el operario presiona IN2: Q=0 → BLINK deshabilitado → OUT1=0.

## 5. Ladder

Versión sin BLINK (lámpara fija):
Rung 1: | | | [ IN1 ] | (S OUT1 ) | |
Rung 2: | | | [ IN2 ] | (R OUT1 ) | |

Versión con BLINK: el BLINK (Level 2) no se convierte perfectamente. Se puede aproximar con un relé interno (marca M) parpadeante.
⚠ Compatibilidad: Level 2 si incluye BLINK.

## 6. Tabla de estados

Evento | IN1 | IN2 | Q (SR) | OUT1 | Descripción
Inicio | 0 | 0 | 0 | 0 | Sin alarma. Sistema normal.

## Sensor activa

brevemente | 1→0 | 0 | 0→1 | 1 | Alarma registrada aunque sensor
| | | | | volvió a 0.
Sensor sigue activo | 1 | 0 | 1 | 1 | Alarma sostenida.
Sensor desaparece | 0 | 0 | 1 | 1 | Alarma SIGUE (memoria). Operario debe reconocer.

Pág. 31 | IEC 61131-3 FBD | ESP32 | RS-485 / Modbus RTU | v5 · 2026
Evento | IN1 | IN2 | Q (SR) | OUT1 | Descripción
Operario presiona IN2 | 0 | 1 | 1→0 | 0 | Alarma reconocida. Se apaga.
Nuevo evento en sensor | 1→0 | 0 | 0→1 | 1 | Nueva alarma. Ciclo se repite.

## 7. Ejercicios

## - Agregar un BLINK y verificar el parpadeo. Cambiar T a 250ms. ¿A qué frecuencia parpadea ahora? (Respuesta: 2 Hz, 2 ciclos por segundo.) - ¿Qué diferencia hay entre este circuito y el del Ejemplo 2.1 (arranque/paro de motor)?

Listar al menos 3 diferencias (tipo de botones, aplicación, comportamiento de fallo).
- [Desafío] Hacer que el buzzer suene fijo (sin BLINK) pero la lámpara parpadee. Modificar el FBD para tener comportamientos diferentes en OUT1 y OUT2 con la misma señal Q.

# Ejemplo 3.4 — Dos lámparas alternadas con F_TRIG

## 1. Concepto: el bloque F_TRIG (flanco descendente)

En el Capítulo 2 vimos R_TRIG (detecta el flanco 0→1, cuando se presiona). F_TRIG detecta el flanco contrario: 1→0 (cuando se suelta el botón). Útil cuando la acción debe ocurrir al soltar, no al presionar.

Bloque | Detecta | Genera pulso cuándo | Uso típico
R_TRIG | Flanco 0→1 | Al PRESIONAR el pulsador (frente de subida) | Arranque, conteo de piezas, toggle
F_TRIG | Flanco 1→0 | Al SOLTAR el pulsador (frente de bajada) | Confirmación de soltar, fin de pulsación larga

Señal IN1:
0 | ─────────┐ | ┌────────────────
│ | │
1 | └──────────────┘
↑ R_TRIG | ↑ F_TRIG
(al presionar) | (al soltar)

F_TRIG en Ladder: contacto [N] (Negative Transition)
| | [N IN1] | ( OUT ) | |
| | Flanco desc. | Bobina | |

## 2. Situación práctica

## Un sistema de señalización necesita dos lámparas que siempre estén en estados opuestos:

cuando A enciende, B apaga, y viceversa. Un pulsador alterna entre los dos estados. Se usa

## F_TRIG para que el cambio ocurra al soltar el botón (técnica usada en botones de máquinas

donde el operario debe ver el efecto al soltar).

Pág. 32 | IEC 61131-3 FBD | ESP32 | RS-485 / Modbus RTU | v5 · 2026

## 3. Esquema de conexión

+24V ──[PULSADOR NA]── IN1 | OUT1 ──[LÁMPARA A (verde)]──┐
0V ────────────────── COM_IN | OUT2 ──[LÁMPARA B (roja) ]──┴── +24V
| COM_OUT ──────────────────────── 0V

OUT1 y OUT2 siempre en estados opuestos: uno ON, el otro OFF.

## 4. Lógica y FBD

Usamos la misma lógica de toggle que en el Ejemplo 2.2, pero con F_TRIG en lugar de R_TRIG. La segunda lámpara (OUT2) se conecta a NOT(Q) para que siempre esté en el estado opuesto.

┌─────────┐
┌────┤ | NOT | ├─────────────────B_set─┐
│ | └─────────┘ | │
┌──────┐ | ┌───────┴──┐ | ┌──────────┴──┐
│ IN1 ├──┤ F_TRIG | ├────────────────────────┤ AND_SET | ├─S─┐
└──────┘ └───────┬──┘ | └────────────┤ | A | │ | │
│ | └─────────────┘ | │ ┌──────┐
│ | ┌─────────────┐ | ├─┤ SR | ├─Q──►
[OUT1] (Lámpara A)
└────────────────────────────┤ AND_RST | ├─R┘ └──┬───┘
Q ────────┤ | B | │ | │Q
└─────────┤ | A | │ | │
└─────────────┘ [NOT]─┘
│
| | | | [OUT2] (Lámpara B)

F_TRIG: el cambio ocurre AL SOLTAR el pulsador (flanco 1→0). NOT(Q) → OUT2: lámpara B siempre opuesta a lámpara A.

Pasos en el editor: igual que el toggle del Cap.2 pero:
- Reemplazar R_TRIG por F_TRIG
- Agregar bloque NOT entre Q del SR y OUT2

## 5. Ladder

Rung 1 — SET (encender A si estaba B):
| | [N IN1] | [/ OUT1] | (S OUT1 ) | |
| | F_TRIG | A apagada | Bobina SET | |

Rung 2 — RESET (apagar A si estaba A):
| | [N IN1] | [ OUT1 ] | (R OUT1 ) | |
| | F_TRIG | A encendida | Bobina RESET | |

Rung 3 — Lámpara B (siempre opuesta a A):
| | [/ OUT1] | ( OUT2 | ) | |
| | A apagada | Lámpara B | |

✅ Compatibilidad: Level 1 — conversión FBD → Ladder perfecta

Pág. 33 | IEC 61131-3 FBD | ESP32 | RS-485 / Modbus RTU | v5 · 2026

## 6. Tabla de estados

Presión N° | Evento F_TRIG | Q (antes) | Q (después) | OUT1 (A) | OUT2 (B)
Inicio | — | 0 | 0 | 0 (apagada) | 1 (encendida)

## 1ª suelta

pulsador | Pulso F_TRIG | 0 | 1 | 1 (enciende) | 0 (apaga)

## 2ª suelta

pulsador | Pulso F_TRIG | 1 | 0 | 0 (apaga) | 1 (enciende)

## 3ª suelta

pulsador | Pulso F_TRIG | 0 | 1 | 1 (enciende) | 0 (apaga)

## 7. Ejercicios

## - Implementar y verificar: las dos lámparas nunca deben estar en el mismo estado

simultáneamente.

## - Cambiar F_TRIG por R_TRIG. ¿En qué momento ocurre el cambio ahora? Describir la

diferencia de comportamiento desde el punto de vista del operario.

## - [Desafío] Modificar para que al inicio (PLC recién encendido) ambas lámparas empiecen apagadas. Primera pulsación: A enciende. Segunda: B enciende (A apaga). Tercera: ambas apagan. Cuarta: vuelve al inicio. ¿Qué cambios se necesitan en el FBD?

# Ejemplo 3.5 — Enclavamiento con prioridad de Reset (seguridad real)

## 1. Situación práctica

Una prensa industrial tiene tres operarios trabajando. Cada uno tiene un botón de emergencia NC. Los tres botones están en serie: si cualquiera lo presiona, la prensa para. Para rearmar la prensa después de una emergencia, un supervisor debe presionar un reset especial (IN2). Esto se llama reset supervisado.

## 2. Esquema de conexión

+24V ──[EMERG.1 NC]──[EMERG.2 NC]──[EMERG.3 NC]──[INICIO NA]── IN1 +24V ──[RESET SUPERVISOR (NA)] ──────────────────────────────── IN2 0V ─────────────────────────────────────────────────────────── COM_IN

OUT1 ──[BOBINA CONTACTOR PRENSA]──┐
COM_OUT ──────────────────────────┘── 0V

Cadena serie de NC: si CUALQUIER botón NC abre (presionado o cable cortado) → IN1 = 0 → no se puede hacer SET → prensa no arranca o para.

Reset supervisado (IN2 NA): solo el supervisor puede rearmar.
Sin IN2=1, aunque todos los NC estén cerrados, el SR permanece en 0.

Pág. 34 | IEC 61131-3 FBD | ESP32 | RS-485 / Modbus RTU | v5 · 2026

## 3. FBD

┌─────┐ | S ┌───────────┐
[IN1] ─┤ | ├────┤ | │Q
│ AND │ | │ | RS | ├─────────────── [OUT1] | (Prensa)
[IN2] ─┤ | ├ | │ | R dom. | │
└─────┘ R └───────────┘

[IN2 NC logic] ──►

Versión simplificada (más clara): S ┌───────────┐
[IN1] ────────┤ | │Q
│ | RS | ├───────────────── [OUT1] | (Prensa)
[IN2] ────────┤ | R dom. | │
R └───────────┘

IN1: cadena [EMERG.1 NC]─[EMERG.2 NC]─[EMERG.3 NC]─[INICIO NA]
IN2: reset supervisor (NA). Sin IN2, no se puede hacer SET.

Uso de RS (no SR): si IN1 e IN2 se activan simultáneamente → RESET gana. Imposible arrancar si alguna emergencia está activa.

## 4. Ladder

Rung 1 — Arranque solo si cadena de seguridad OK y supervisor autoriza:
| | [ IN1 ] | [ IN2 ] | (S OUT1 ) | |
| (cadena NC | Reset | Bobina SET | |
| | + inicio) | superv. | | |

Rung 2 — Parada con prioridad absoluta:
| | [/ IN1 ] | (R OUT1 ) | |
| Cadena rota | Bobina RESET | |
| (o emergencia) | |

✅ Compatibilidad: Level 1 — conversión FBD → Ladder perfecta

## 5. Ejercicios

- Simular la rotura de cable: desconectar físicamente el cable de IN1. ¿Qué hace la prensa?

## ¿Por qué? (Respuesta: para, porque IN1=0 → no hay SET posible y el RS mantiene

RESET).
- ¿Por qué el reset supervisado (IN2) es necesario? ¿Qué pasaría si no existiera y la prensa

## se rearmara sola al cerrar todos los NC? - [Desafío] Agregar una lámpara en OUT2 que parpadee (BLINK) indicando "emergencia activa: rearme requerido". La lámpara debe apagarse solo cuando el supervisor presiona IN2. ¿Cómo detectar si la emergencia está activa?

Pág. 35 | IEC 61131-3 FBD | ESP32 | RS-485 / Modbus RTU | v5 · 2026

# Capítulo 4 — Temporizadores

Los temporizadores permiten que el PLC controle el tiempo: retardar un arranque, mantener una salida activa por un tiempo fijo, o generar señales periódicas. El PLC-CORE-MDE tiene cuatro

## bloques de temporización: TON, TOF, TP y BLINK. El tiempo siempre se configura en

milisegundos (ms). 1 segundo = 1000 ms. 1 minuto = 60000 ms.

# Los cuatro temporizadores — Resumen visual

Bloque | Nombre completo | Comportamiento en una frase | Uso típico
TON | Timer ON-Delay | Activa la salida DESPUÉS de que la entrada lleva activa el tiempo PT. | Retardo de arranque, filtro antirrebote
TOF | Timer OFF-Delay | Mantiene la salida activa por PT milisegundos DESPUÉS de que la entrada se desactiva. | Retardo de paro, ventilador de enfriamiento
TP | Timer Pulse | Genera un pulso de duración EXACTA de PT milisegundos al detectar un flanco ascendente. | Pulso único de tiempo fijo, semáforo
BLINK | Oscillator / Blink | Genera una onda cuadrada: alterna 0 y 1 con período T milisegundos. | Señalización parpadeante, ritmo

## Parámetro de tiempo — siempre en milisegundos

Conversiones rápidas:
100 ms | = 0,1 segundos | (filtro rápido)
500 ms | = 0,5 segundos | (parpadeo 1 Hz)
1000 ms = 1 segundo
5000 ms = 5 segundos
30000 ms = 30 segundos (ventilador post-paro) 60000 ms = 1 minuto
300000 ms = 5 minutos
3600000 ms = 1 hora

En el editor FBD: campo "time" del bloque timer. Ingresar el número sin unidad.

# Ejemplo 4.1 — TON: retardo al encendido

## 1. Situación práctica

Una cinta transportadora no debe arrancar inmediatamente al presionar el botón. Debe esperarse 5 segundos para que los operarios se alejen de la zona peligrosa. Después de 5 segundos, la cinta arranca sola. Si se presiona el paro durante esos 5 segundos, la cuenta se reinicia.

## 2. Funcionamiento del TON

## Cómo funciona el TON internamente

El TON tiene tres terminales:
→ EN (Enable): entrada booleana. Mientras EN=1, el timer cuenta.
→ PT (Preset Time): tiempo configurado en ms (parámetro del bloque). → Q (Output): salida booleana. Q=1 cuando el tiempo acumulado ≥ PT.

Pág. 36 | IEC 61131-3 FBD | ESP32 | RS-485 / Modbus RTU | v5 · 2026

Comportamiento:
→ EN sube a 1: el timer empieza a contar desde 0.
→ Si EN sigue en 1 y pasa PT ms: Q sube a 1.
→ Si EN baja a 0 antes de llegar a PT: el contador VUELVE A 0. Q queda en 0. → Cuando EN baja a 0 (aunque Q estuviera en 1): Q baja a 0 inmediatamente.

## 3. Diagrama de tiempo — TON con PT=5000ms

EN ──────────────────────┐ | ┌───────────────
└─────────────────────┘
| EN baja | EN sube de nuevo
Q | ──────────────────────────────────────┐ | ┌─────────────
(salida) | └──────┘
| Q baja │←──── 5000ms ────►│
EN sube | Q sube

Caso 2 — EN baja antes de PT:
EN ─────────────┐ | ┌────────────────────────────────
| └────┘
Q | ─────────────────────────────────────────────────── (nunca sube)
| │←──PT no cumplido→│

El contador se reinicia al bajar EN.

## 4. Esquema de conexión

+24V ──[ARRANQUE NA]── IN1 | OUT1 ──[MOTOR CINTA]──┐
+24V ──[PARO NC | ]── IN2 | COM_OUT ───────────────┘── 0V

0V ──────────────── COM_IN

## 5. Diagrama FBD

S ┌─────────┐ | EN ┌───────────────┐
[IN1] ────────┤ | │Q ─────────┤ | TON | │Q
│ | SR | │ | │ | PT=5000ms | ├─────── [OUT1]
[IN2] ────────┤ S dom. │ | └───────────────┘
R └─────────┘

Flujo de señales:
IN1 → SET del SR → Q del SR → EN del TON → Q del TON → OUT1
IN2 → RESET del SR → Q del SR baja → EN del TON baja → OUT1 baja

Pasos en el editor:
1. Agregar IN1, IN2, SR, TON, OUT1
2. Conectar IN1 → S del SR
3. Conectar IN2 → R del SR
4. Conectar Q del SR → EN del TON
5. En el bloque TON: configurar "time = 5000"
6. Conectar Q del TON → entrada de OUT1
7. GUARDAR → RUN

Pág. 37 | IEC 61131-3 FBD | ESP32 | RS-485 / Modbus RTU | v5 · 2026

## 6. Diagrama Ladder

Rung 1 — Arranque con automantenimiento:
| | [ IN1 ] | [ IN2 ] | (S M1 | ) | |
| | Arranque | Paro | Marca interna | |

Rung 2 — Paro:
| | [/ IN2 ] | (R M1 | ) | |

Rung 3 — Temporización:
| | [ M1 | ] | [TON PT=5000 Q M2] | |
| | Memoria | Timer 5 segundos | |

Rung 4 — Salida:
| | [ M2 | ] | ( OUT1 | ) | |
| | TON listo | Motor cinta | |

Nota: M1 y M2 son "marcas" o relés internos (variables internas del PLC). En el PLC-CORE-MDE, la conversión automática maneja esto internamente.

✅ Compatibilidad: Level 1 — conversión FBD → Ladder perfecta

## 7. Tabla de estados

Tiempo | Evento | Q del SR | TON contando | Q del TON | OUT1 (cinta)
t=0 | PLC encendido | 0 | No | 0 | 0 (parada)
t=1s | Se presiona IN1 | 1 | Sí (0ms) | 0 | 0 (esperando)
t=3s | 2 segundos después | 1 | Sí (2000ms) | 0 | 0 (esperando)
t=6s | 5 segundos completos | 1 | Listo (5000ms) | 1 | 1 (arranca)
t=8s | Se presiona IN2 | 0 | No (reset) | 0 | 0 (para)
t=9s | Se presiona IN1 de nuevo | 1 | Sí (0ms) | 0 | 0 (esperando 5s)

## 8. Prueba paso a paso

47. Cargar programa, activar RUN.
48. Presionar IN1 → OUT1 sigue en 0. Contar mentalmente 5 segundos.
49. A los 5 segundos: OUT1 debe pasar a 1 automáticamente.

## 50. Presionar IN1 → esperar 3 segundos → presionar IN2 antes de llegar a 5s. OUT1 nunca

debe llegar a 1. El TON reinicia.
51. En el Monitor: observar la variable interna del TON (valor acumulado) subiendo.

## 9. Ejercicios

- Cambiar PT a 3000ms. Verificar que la espera es de 3 segundos.

## - Agregar una lámpara en OUT2 que encienda durante los 5 segundos de espera y se

apague cuando la cinta arranca. Pista: OUT2 = Q del SR AND NOT(Q del TON).

## - [Desafío] Agregar un BLINK en OUT2 que parpadee durante la espera (señal de "arranque

inminente") en lugar de luz fija.

# Ejemplo 4.2 — TOF: retardo al apagado

Pág. 38 | IEC 61131-3 FBD | ESP32 | RS-485 / Modbus RTU | v5 · 2026

## 1. Situación práctica

## Un ventilador de refrigeración de un motor eléctrico debe seguir funcionando 30 segundos

después de que el motor se apague, para terminar de enfriar la carcasa. El motor se controla con IN1/IN2 y el ventilador con TOF.

## 2. Funcionamiento del TOF

## Cómo funciona el TOF internamente

El TOF también tiene EN, PT y Q, pero con comportamiento opuesto al TON: → EN sube a 1: Q sube a 1 INMEDIATAMENTE (sin esperar).
→ EN baja a 0: Q se MANTIENE en 1 y el timer empieza a contar.
→ Pasan PT ms con EN=0: Q baja a 0.
→ Si EN vuelve a subir antes de llegar a PT: el contador se reinicia.

Frase para recordar:
TON = "espera para encender"
TOF = "espera para apagar"

## 3. Diagrama de tiempo — TOF con PT=30000ms

EN ──────────────────────────┐ | ┌───────────
└─────────────────┘
| EN baja | EN sube
Q | ──────────────────────────────────────────┐ | ┌──────────
(salida) | └──┘

Q baja
| │←── 30000ms ──►│
EN baja | Q baja

→ EN sube: Q sube INMEDIATAMENTE (motor y ventilador ON juntos). → EN baja: Q se mantiene 30s más (motor OFF, ventilador sigue). → Pasados 30s: Q baja (ventilador OFF).

## 4. Diagrama FBD

S ┌─────────┐
[IN1] ────────┤ | │Q ──────────────────────────────── [OUT2] | (Motor: ON
inmediato)
│ | SR | │
[IN2] ────────┤ S dom. │ | EN ┌───────────────┐
R └─────────┘ Q ───────┤ | TOF | │Q
│ PT=30000ms | ├────── [OUT1] | (Ventilador)
└───────────────┘

Q del SR va a DOS lugares:
→ Directamente a OUT2: motor encendido mientras SR=1.
→ Al EN del TOF: ventilador encendido mientras SR=1 Y 30s después.

Secuencia al presionar PARO (IN2):
SR → Q=0 → Motor (OUT2) se apaga INMEDIATAMENTE.
→ TOF: EN=0 → empieza la cuenta de 30s → OUT1 sigue 30s más.

Pág. 39 | IEC 61131-3 FBD | ESP32 | RS-485 / Modbus RTU | v5 · 2026

## 5. Diagrama Ladder

Rung 1: | | | [ IN1 ] | [ IN2 ] | (S M1 | ) | | | (arranque SR)
Rung 2: | | | [/ IN2 ] | (R M1 | ) | | | (paro SR)
Rung 3: | | | [ M1 | ] | ( OUT2 | ) | | | (motor: directo)
Rung 4: | | | [ M1 | ] | [TOF PT=30000 Q M2] | | | (timer)
Rung 5: | | | [ M2 | ] | ( OUT1 | ) | | | (ventilador)

✅ Compatibilidad: Level 1 — conversión FBD → Ladder perfecta

## 6. Tabla de estados

Evento | (motor) Q SR | EN del TOF | Q del TOF (ventilador) | OUT2 motor | OUT1 ventilador
Inicio | 0 | 0 | 0 | 0 | 0
Presionar IN1 (arranque) | 1 | 1 | 1 | 1 (ON) | 1 (ON)
Sistema funcionando | 1 | 1 | 1 | 1 | 1
Presionar IN2 (paro) | 0 | 0 | 1 (sigue!) | 0 (OFF) | 1 (sigue!)

## 10 segundos después

del paro | 0 | 0 | 1 (contando) | 0 | 1 (sigue)

## 30 segundos después

del paro | 0 | 0 | 0 (listo) | 0 | 0 (OFF)

## 7. Ejercicios

## - Ajustar PT a 10000ms (10 segundos). Verificar que el ventilador sigue 10s después del

paro del motor.

## - Agregar un LED indicador en OUT3 que encienda solo durante los 30s de post-

enfriamiento (ventilador ON, motor OFF). Pista: OUT3 = Q_TOF AND NOT(Q_SR).

## - [Desafío] ¿Qué pasa si se presiona ARRANQUE durante los 30s de post-enfriamiento del

TOF? El TOF reinicia su cuenta. Verificar este comportamiento y explicarlo.

# Ejemplo 4.3 — TP: pulso de duración fija

## 1. Situación práctica

Un semáforo peatonal: al presionar el botón, la luz roja para vehículos debe durar exactamente 15 segundos, sin importar si el peatón sigue presionando el botón. Mientras el rojo vehicular está activo, el verde peatonal también se activa (con un pequeño retardo de seguridad).

## 2. Funcionamiento del TP

## Cómo funciona el TP internamente

El TP detecta un FLANCO ASCENDENTE en EN y genera un pulso de duración exacta PT: → EN sube (flanco 0→1): Q sube a 1 y el timer empieza a contar.
→ Pasan PT ms: Q baja a 0. FIN del pulso.
→ Si EN sigue en 1 durante el pulso: NO importa. El pulso ya duró PT ms.
→ Si EN sube de nuevo durante el pulso: IGNORADO. No re-dispara.

Diferencia clave con TON:

Pág. 40 | IEC 61131-3 FBD | ESP32 | RS-485 / Modbus RTU | v5 · 2026

TON: Q=1 DESPUÉS de PT ms con EN activo continuo.
TP: Q=1 POR PT ms al detectar el flanco. No necesita EN continuo.

Diferencia clave con TOF:
TOF: extiende la salida PT ms DESPUÉS del flanco descendente.
TP: genera la salida POR PT ms a partir del flanco ascendente.

## 3. Diagrama de tiempo — TP con PT=15000ms

EN ──────────────────────────────────┐ | ┌──────
(pulsador) | └───────┘
│ flanco | │ no importa cuánto
│ ascendente | │ dure EN
Q | ──────────────────────────────────┐ | ┌──
(rojo) | └─────────────┘
| │←──────── exacto 15000ms ──────►│

2° presión durante el pulso:
EN ──────┐ ┌────────────────────────────────────────────
└─┘ ← ignorado (no re-dispara)

Q ──────────────────────────────────┐ └──── (sigue el pulso original)

## 4. Esquema de conexión

+24V ──[PULS. PEATÓN NA]── IN1 | OUT1 ──[LUZ ROJA VEHÍCULOS]──┐
0V ──────────────────── COM_IN | OUT2 ──[LUZ VERDE VEHÍCULOS]──┤
OUT3 ──[LUZ VERDE PEATÓN | ]──┴── +24V

COM_OUT ──────────────────────── 0V

## 5. Diagrama FBD

EN ┌───────────────┐Q
[IN1] ──────┤ | TP | ├────────────────────────── [OUT1] | (Rojo vehículos)
│ | PT=15000ms | │
└───────────────┘Q
| | └── [NOT] ─────────────── [OUT2] | (Verde vehículos)

EN ┌───────────────┐Q
[IN1] ──────┤ | TON | ├────────────────────────── [OUT3] | (Verde peatón)
│ | PT=3000ms | │
└───────────────┘

IN1 → TP (15s): rojo para vehículos exacto 15s.
NOT(Q del TP) → OUT2: verde vehículos siempre opuesto al rojo.
IN1 → TON (3s): verde peatón activa recién después de 3s de seguridad.

Nota: se usan dos bloques con la misma entrada IN1. Esto es válido. Un nodo FBD puede tener múltiples conexiones salientes.

Pág. 41 | IEC 61131-3 FBD | ESP32 | RS-485 / Modbus RTU | v5 · 2026

## 6. Diagrama Ladder

Rung 1 — Pulso rojo 15s:
| | [ IN1 ] | [TP PT=15000 Q M1] | |
| | Pulsador | Pulso exacto 15s | |

Rung 2 — Luz roja vehículos:
| | [ M1 | ] | ( OUT1 ) | |

Rung 3 — Luz verde vehículos (opuesta al rojo):
| | [/ M1 | ] | ( OUT2 ) | |

Rung 4 — Retardo de seguridad para verde peatón:
| | [ IN1 ] | [TON PT=3000 Q M2] | |

Rung 5 — Luz verde peatón:
| | [ M2 | ] | ( OUT3 ) | |

✅ Compatibilidad: Level 1 — conversión FBD → Ladder perfecta

## 7. Tabla de estados

Tiempo | Evento | Q del TP | OUT1 (rojo veh.) | OUT2 (verde veh.) | OUT3 (verde peatón)
t=0 | Estado inicial | 0 | 0 | 1 | 0
t=1s | Peatón presiona IN1 | 1 | 1 | 0 | 0
t=4s | 3s después → TON listo | 1 | 1 | 0 | 1
t=5s | Peatón presiona IN1 de nuevo | 1 (ignora) | 1 | 0 | 1
t=16s | 15s después del primer
flanco | 0 | 0 | 1 | 0

## 8. Ejercicios

## - Cambiar PT del TP a 20000ms (20s). Verificar que el rojo dura exactamente 20s aunque

se presione el botón muchas veces.

- ¿Por qué es importante que el TP no se re-dispare? Pensar en el contexto del semáforo: ¿qué pasaría si un grupo de niños presiona el botón varias veces? - [Desafío] Agregar una señal acústica en OUT4 que suene (BLINK T=500ms) durante los últimos 5 segundos del rojo vehicular (señal de "atención, verde inminente"). Pista:

necesitás un TON de 10000ms en paralelo.

# Ejemplo 4.4 — BLINK: oscilador para señalización

## 1. Situación práctica

Un panel de control muestra una lámpara parpadeando a 1 Hz cuando hay una alarma activa, y luz fija cuando el sistema está normal. Un segundo modo genera parpadeo rápido (4 Hz) para indicar alarma crítica.

Pág. 42 | IEC 61131-3 FBD | ESP32 | RS-485 / Modbus RTU | v5 · 2026

## 2. Funcionamiento del BLINK

## Cómo funciona el BLINK internamente

El BLINK genera una onda cuadrada mientras su entrada EN=1:
→ EN=1: la salida alterna entre 0 y 1 con el período T configurado. → EN=0: la salida se queda en 0 (oscilador detenido).

Período T en ms: tiempo total de un ciclo completo (ON + OFF).
La salida está T/2 ms en 1 y T/2 ms en 0 (onda cuadrada al 50%).

Ejemplos:
T=1000ms → 0,5s ON / 0,5s OFF → 1 ciclo/segundo = 1 Hz | (parpadeo lento)
T=500ms | → 0,25s ON / 0,25s OFF → 2 ciclos/segundo = 2 Hz
T=250ms | → 0,125s ON / 0,125s OFF → 4 ciclos/segundo = 4 Hz (parpadeo rápido)
Frecuencia = 1000 / T | [Hz] | (T en ms)
Período T | = 1000 / f | [ms] | (f en Hz)

## 3. Diagrama de tiempo — BLINK T=500ms

EN ────────────────────────────────────────────── (habilitado)

Q | ──────┐ ┌─────┐ ┌─────┐ ┌─────┐ ┌─────┐ ┌───
(salida) | └─┘ | └─┘ | └─┘ | └─┘ | └─┘
│←250ms→│←250ms→│
│←─────── 500ms ──────→│ = 1 ciclo = 2 Hz

EN=0:
EN | ────────────────────────────┐ | ┌───────
└─────────┘
Q | ──────┐ ┌─────┐ ┌──────────────────────┐ ┌───
└─┘ | └─┘ | EN=0: Q queda en 0 | └─

## 4. Diagrama FBD — Alarma con parpadeo lento (1 Hz) y rápido (4 Hz)

Alarma normal (1 Hz):
S ┌─────────┐ | Q | EN ┌────────────┐ | Q
[IN1] ────────┤ | SR | ├─────────┤ | BLINK | ├──── [OUT1]
[IN2] ────────┤ S dom. │ | │ T=1000ms | │
R └─────────┘ | └────────────┘

Alarma crítica (4 Hz):
S ┌─────────┐ | Q | EN ┌────────────┐ | Q
[IN2] ────────┤ | SR2 | ├─────────┤ | BLINK2 | ├──── [OUT2]
R └─────────┘ | │ T=250ms | │
└────────────┘

IN1: sensor de alarma normal → SR1 → BLINK 1Hz → OUT1
IN2: sensor de alarma crítica → SR2 → BLINK 4Hz → OUT2
(Nota: con solo 2 entradas y 4 salidas, hay que elegir qué hacer. En este ejemplo IN1 = alarma normal, IN2 = alarma crítica/reset)

Pág. 43 | IEC 61131-3 FBD | ESP32 | RS-485 / Modbus RTU | v5 · 2026

## 5. Tabla de frecuencias de referencia

T (ms) | T/2 ON | T/2 OFF | Frecuencia | Percepción visual
2000 | 1000ms | 1000ms | 0,5 Hz | Muy lento. Claramente perceptible. Indicación tranquila.
1000 | 500ms | 500ms | 1 Hz | Lento. Estándar para alarmas normales.
500 | 250ms | 250ms | 2 Hz | Moderado. Urgencia media.
250 | 125ms | 125ms | 4 Hz | Rápido. Alarma crítica o de alta urgencia.
100 | 50ms | 50ms | 10 Hz | Muy rápido. Puede parecer luz fija a simple vista.

## 6. Ladder

El BLINK se puede aproximar en Ladder con un relé de marca parpadeante. Muchos PLCs tienen un "clock relay" interno que parpadea a frecuencia fija. En el PLC-CORE-MDE, la conversión automática lo maneja como Level 2.

Rung aproximado (usando marca parpadeante M_1Hz del sistema):
| | [ M1 ] | [M_1Hz] | ( OUT1 ) | |
| | Alarma | Parpadeo 1Hz | Lámpara | |

⚠ Compatibilidad: Level 2 — aproximado. El BLINK no tiene equivalente exacto en Ladder estándar sin marcas internas.

## 7. Ejercicios

## - Cambiar T a 250ms. Verificar que la frecuencia de parpadeo aumenta. ¿Se nota la diferencia visualmente? - Hacer que una lámpara brille FIJA cuando hay alarma (OUT1) y PARPADEE cuando hay doble alarma (IN1 e IN2 simultáneos). Usar AND para combinar las dos señales de alarma

con el BLINK.
- [Desafío] Calcular el valor T para obtener exactamente 3 Hz de parpadeo. (Respuesta: T = 1000/3 ≈ 333ms). Verificar visualmente.

# Ejemplo 4.5 — Motor con retardo de arranque y retardo de paro

## 1. Situación práctica

Un motor industrial no debe arrancar ni parar abruptamente. Al dar arranque, espera 3 segundos antes de activarse (para que los operarios se despejen). Al dar paro, el motor sigue 5 segundos más (para que el proceso termine ordenadamente, como una cinta que vacía su carga).

## 2. Lógica: TON + TOF en cascada

La señal de habilitación pasa primero por el TON (retarda el arranque) y luego la salida del TON alimenta al TOF (extiende el paro). Es una cascada de dos timers.

Pág. 44 | IEC 61131-3 FBD | ESP32 | RS-485 / Modbus RTU | v5 · 2026

## 3. Diagrama FBD

S ┌─────────┐ | EN ┌──────────────┐ | EN ┌─────────────┐
[IN1] ────────┤ | │Q ──────┤ | TON | │Q ─────┤ | TOF | │Q
│ | SR | │ | │ PT=3000ms | │ | │ PT=5000ms | ├──► [OUT1]
[IN2] ────────┤ S dom. │ | └──────────────┘ | └─────────────┘
R └─────────┘

Flujo completo:
IN1 arranca → SR Q=1 → TON empieza a contar 3s.
A los 3s: TON Q=1 → TOF: EN=1 → Q_TOF=1 → OUT1=1 (MOTOR ARRANCA).

IN2 para → SR Q=0 → TON se reinicia → TON Q=0 → TOF: EN=0 → cuenta 5s. A los 5s: TOF Q=0 → OUT1=0 (MOTOR PARA).

Pasos en el editor:
1. Agregar IN1, IN2, SR, TON, TOF, OUT1
2. IN1 → S del SR; IN2 → R del SR
3. Q del SR → EN del TON; configurar TON time=3000
4. Q del TON → EN del TOF; configurar TOF time=5000
5. Q del TOF → entrada de OUT1
6. GUARDAR → RUN

## 4. Ladder

Rung 1: | | | [ IN1 ] | [ IN2 ] | (S M1 | ) | |
Rung 2: | | | [/ IN2 ] | (R M1 | ) | |
Rung 3: | | | [ M1 | ] | [TON PT=3000 | Q M2] | |
Rung 4: | | | [ M2 | ] | [TOF PT=5000 | Q M3] | |
Rung 5: | | | [ M3 | ] | ( OUT1 | ) | |

✅ Compatibilidad: Level 1 — conversión FBD → Ladder perfecta

## 5. Tabla de estados

Evento | Q SR | TON contando | Q TON | TOF contando | Q TOF / OUT1
Inicio | 0 | No | 0 | No | 0
Presionar IN1 (t=0) | 1 | Sí (0ms) | 0 | No | 0
t=3s | 1 | Listo | 1 | No (EN=1) | 1 → MOTOR ON
Presionar IN2 (t=10s) | 0 | Reinicia | 0 | Sí (0ms) | 1 (sigue!)
t=15s (5s después del paro) | 0 | No | 0 | Listo | 0 → MOTOR OFF

## 6. Ejercicios

- Ajustar los tiempos a 5s de retardo de arranque y 10s de retardo de paro.

## - Agregar lámpara en OUT2 que encienda durante los 3s de retardo de arranque (indicador

"máquina arrancando"). Pista: OUT2 = Q_SR AND NOT(Q_TON).

## - [Desafío] Agregar un indicador adicional en OUT3 que encienda solo durante los 5s de retardo de paro (motor todavía funcionando pero paro solicitado). Pista: OUT3 = Q_TOF

AND NOT(Q_SR).

Pág. 45 | IEC 61131-3 FBD | ESP32 | RS-485 / Modbus RTU | v5 · 2026

# Ejemplo 4.6 — Alarma por tiempo: TON de seguridad (timeout)

## 1. Situación práctica

Un sensor de nivel bajo activa una bomba de llenado. Si después de 5 minutos el nivel sigue bajo (la bomba no pudo llenar el tanque), se activa una alarma sonora. Esto evita alarmas falsas por activaciones momentáneas del sensor, y detecta fallas en la bomba o en la tubería.

## 2. FBD

S ┌─────────┐Q
[IN1] ────────┤ | ├────────────────────────────────── [OUT1] | (BOMBA)
(nivel bajo) | │ | SR | │
[IN2] ────────┤ S dom. │ | Q | EN ┌──────────────────┐Q
(reset op.) | R└─────────┘ ──────────┤ TON PT=300000ms ├──────── [OUT2] | (ALARMA)
└──────────────────┘

PT = 300000 ms = 5 minutos

Si el nivel sigue bajo (SR=1) durante 5 minutos:
→ TON acumula 300000ms → Q_TON=1 → OUT2=1 → alarma suena.

Si el nivel se restablece (IN2 resetea el SR):
→ SR Q=0 → TON se reinicia → Q_TON=0 → alarma no suena.

Si el operario presiona IN2 después de la alarma:
→ SR Q=0 → motor para → TON reinicia → alarma apaga.

## 3. Ladder

Rung 1: | | | [ IN1 ] | [ IN2 ] | (S M1 | ) | | | (arranque bomba)
Rung 2: | | | [/ IN2 ] | (R M1 | ) | | | (paro bomba)
Rung 3: | | | [ M1 | ] | ( OUT1 | ) | | | (bomba ON)
Rung 4: | | | [ M1 | ] | [TON PT=300000 | Q M2] | | | (timeout 5 min)
Rung 5: | | | [ M2 | ] | ( OUT2 | ) | | | (alarma)

✅ Compatibilidad: Level 1 — conversión FBD → Ladder perfecta

## 4. Tabla de estados

Situación | Q SR (bomba) | TON (minutos) | OUT1 (bomba) | OUT2 (alarma) | Diagnóstico
Nivel OK | 0 | 0 | 0 | 0 | Normal: sin actividad

## Nivel bajo → bomba

ON | 1 | 0→cuenta | 1 | 0 | Bomba llenando
| | | | | normalmente

## Nivel se restaura en 2

min | 0 | Reinicia | 0 | 0 | Llenado exitoso

## Nivel bajo 5 min

(falla) | 1 | 5 min
| | cumplidos | 1 | 1 | ALARMA: bomba
| | | | | no llenó

## Operario presiona

IN2 | 0 | Reinicia | 0 | 0 | Reset manual.
| | | | | Inspeccionar.

Pág. 46 | IEC 61131-3 FBD | ESP32 | RS-485 / Modbus RTU | v5 · 2026

## 5. Ejercicios

## - Ajustar el tiempo de alarma a 2 minutos (120000ms). Verificar que la alarma suena si la

bomba lleva más de 2 minutos activa.

## - Agregar lógica para que cuando se activa la alarma (OUT2=1), también se detenga la bomba (OUT1=0). ¿Cómo se implementa esto? (Pista: usar Q_TON como entrada R de un

RS).
- [Desafío] Agregar un contador que cuente cuántas veces se activó la alarma de timeout.

## Usar CTU con la señal Q_TON como entrada de conteo (ver Capítulo 5). Indicar en OUT3

cuando se alcanzaron 3 alarmas (mantenimiento requerido).

# Resumen comparativo de los cuatro temporizadores

Característica | TON | TOF | TP | BLINK
¿Cuándo sube Q? | Después de PT ms con EN=1 | Inmediatamente al subir EN | Inmediatamente al flanco 0→1

## de EN

| | | | Alterna con período T
¿Cuándo baja Q? | Cuando EN baja a 0 | Después de PT ms con EN=0 | Después de exactamente PT

ms

| | | | Alterna con período T
¿Se puede re-disparar? | Sí (reinicia si EN baja y sube) | Sí (reinicia si EN sube de nuevo) | No (ignora flancos durante el pulso) | Continuo mientras EN=1

## Depende de EN continuo

## Sí (debe mantenerse en

1)

## No (solo necesita flanco)

## No (solo necesita flanco)

## Sí (oscila mientras EN=1)

Uso principal | Retardo arranque | Retardo paro / post- enfriamiento | Pulso único de tiempo fijo | Señalización parpadeante
Ladder | ✅Level 1 | ✅Level 1 | ✅Level 1 | ⚠ Level 2

## ¿Cuál usar?

Pregunta | → Timer recomendado
¿Quiero que algo tarde X segundos en encender? | → TON
¿Quiero que algo tarde X segundos en apagarse? | → TOF
¿Quiero un pulso exacto de X segundos? | → TP
¿Quiero algo que parpadee? | → BLINK

Pág. 47 | IEC 61131-3 FBD | ESP32 | RS-485 / Modbus RTU | v5 · 2026

# Capítulo 5 — Contadores

Los contadores permiten al PLC contar eventos: piezas producidas, personas que ingresan,

## pulsos de un sensor, ciclos de una máquina. El PLC-CORE-MDE tiene dos bloques de conteo:

CTU (Counter Up, contador ascendente) y CTD (Counter Down, contador descendente).

# Los bloques CTU y CTD — Estructura y terminales

Terminal | CTU (Counter Up) | CTD (Counter Down)
Entrada de conteo | CU (Count Up): flanco 0→1 incrementa CV en 1 | CD (Count Down): flanco 0→1 decrementa CV en 1

## Entrada de

reset/carga | R (Reset): R=1 → CV vuelve a 0 | LD (Load): LD=1 → CV se carga con PV
Valor preset | PV (Preset Value): objetivo de conteo | PV: valor inicial de carga
Valor actual | CV (Current Value): cuenta actual (0 a PV o más) | CV: valor actual (PV a 0)
Salida | Q=1 cuando CV ≥ PV | Q=1 cuando CV ≤ 0

## Regla fundamental: siempre usar R_TRIG antes del CTU/CTD

Un sensor o pulsador puede permanecer activo durante varios ciclos de scan. Ejemplo: sensor activo 50ms → PLC ejecuta 5 ciclos (cada 10ms) → CTU contaría 5 veces.

El R_TRIG convierte la señal continua en un pulso de exactamente 1 ciclo (10ms). Con R_TRIG: cada activación del sensor = exactamente 1 conteo. Siempre.

Excepción: si la señal ya es un pulso corto garantizado (< 10ms), no es necesario. En la práctica industrial: SIEMPRE poner R_TRIG entre sensor y CU del contador.

Sin R_TRIG (MAL): | | Con R_TRIG (BIEN):
Sensor activo 50ms | | Sensor activo 50ms
──────────────────── | | ────────────────────
CTU cuenta: 5 (incorrecto) | CTU cuenta: 1 (correcto)
[SENSOR]──CU──[CTU] | ←INCORRECTO | [SENSOR]──[R_TRIG]──CU──[CTU] | ←CORRECTO

# Ejemplo 5.1 — CTU: contador de piezas con sensor óptico

## 1. Situación práctica

Un sensor óptico en una cinta transportadora detecta cada pieza que pasa. El PLC cuenta las piezas. Al llegar a 20, la cinta se detiene automáticamente, suena una alarma y parpadea una lámpara. El operario retira el lote, presiona reset y el proceso reinicia.

## 2. Esquema de conexión

+24V ──[SENSOR ÓPTICO PNP]── IN1 | OUT1 ──[MOTOR CINTA | ]──┐
+24V ──[RESET OPERARIO NA]── IN2 | OUT2 ──[ALARMA SONORA]──┤
0V ──────────────────────── COM_IN | OUT3 ──[LÁMPARA BLINK]──┴── +24V

COM_OUT ─────────────────── 0V

Sensor óptico PNP: cuando detecta una pieza → entrega +24V → IN1=1. Cada pieza genera un pulso en IN1.
IN2 NA: operario presiona para resetear el contador después del lote.

Pág. 48 | IEC 61131-3 FBD | ESP32 | RS-485 / Modbus RTU | v5 · 2026

## 3. Lógica del circuito

El CTU cuenta los flancos en CU. Cuando CV llega a PV=20, Q pasa a 1. Q=1 detiene la cinta (NOT Q → OUT1), activa la alarma (OUT2) y el parpadeo (OUT3 via BLINK). El operario presiona IN2: R=1 → CV vuelve a 0 → Q vuelve a 0 → cinta arranca de nuevo.

## 4. Diagrama FBD

┌──────┐ | ┌────────┐ | CU ┌─────────────┐Q
│ IN1 | ├──┤ R_TRIG ├─────┤ | CTU | ├────────────────────── [OUT2] | (Alarma)
└──────┘ └────────┘ | │ | PV=20 | │
┌──────┐ | R ───┤ | │
│ IN2 | ├────────────────►│ | | │Q
└──────┘ | └─────────────┘
│Q
├── [BLINK T=500ms] ──────────── [OUT3]

(Parpadeo)
│
└── [NOT] ───────────────────── [OUT1] (Motor cinta)
| | | (NOT Q: cinta ON cuando Q=0)

Pasos en el editor:
1. Agregar IN1, R_TRIG, CTU (configurar PV=20), IN2, NOT, BLINK, OUT1, OUT2, OUT3
2. IN1 → R_TRIG; R_TRIG → CU del CTU
3. IN2 → R del CTU
4. Q del CTU → entrada de OUT2 (alarma directa)
5. Q del CTU → EN del BLINK (T=500ms); Q del BLINK → OUT3
6. Q del CTU → entrada del NOT; salida del NOT → OUT1
7. GUARDAR → RUN

## 5. Diagrama Ladder

Rung 1 — Conteo de piezas:
| | [P IN1 ] | [CTU PV=20 Q M1] | |
| | R_TRIG | Contador ascend. | |

Rung 2 — Reset del contador:
| | [ IN2 | ] | (R_CTU IN1 | ) | |
| | Reset op. | Reset contador | |

Rung 3 — Alarma (lote completo):
| | [ M1 | ] | | ( OUT2 | ) | |

Rung 4 — Motor cinta (activo mientras NO hay lote):
| | [/ M1 | ] | | ( OUT1 | ) | |
| | NOT Q | | | Motor | | |

Rung 5 — Parpadeo (aproximado con marca de reloj):
| | [ M1 | ] | [M_2Hz ] | ( OUT3 | ) | |
| | Lote listo | Parpadeo | Lámpara | |

✅ Compatibilidad: Level 1 para CTU. Level 2 si incluye BLINK.

Pág. 49 | IEC 61131-3 FBD | ESP32 | RS-485 / Modbus RTU | v5 · 2026

## 6. Tabla de funcionamiento

Evento | CV
(cuenta) | Q del CTU | OUT1 (cinta) | OUT2

## (alarma)

## OUT3 (parpadeo)

## Inicio / después de

reset | 0 | 0 | 1 (ON) | 0 (OFF) | 0 (OFF)
Pasa pieza 1 | 1 | 0 | 1 (ON) | 0 | 0
Pasa pieza 10 | 10 | 0 | 1 (ON) | 0 | 0
Pasa pieza 19 | 19 | 0 | 1 (ON) | 0 | 0
Pasa pieza 20 | 20 | 1 | 0 (OFF) | 1 (ON) | 1 (parpadea)
Pasan más piezas (si alguien no nota) | 21, 22... | 1 | 0 (OFF) | 1 | 1
Operario presiona IN2 (reset) | 0 | 0 | 1 (ON) | 0 | 0

## 7. Prueba paso a paso

52. Cargar programa y activar RUN. Verificar OUT1=1 (cinta en marcha).
53. Activar IN1 brevemente 20 veces (simular piezas). En el Monitor: observar CV subir 1 a 1.

## 54. En la pieza 20: Q sube a 1 → OUT1 cae a 0 (cinta para) → OUT2=1 (alarma) → OUT3

parpadea.
55. Presionar IN2: CV vuelve a 0, Q=0, cinta arranca de nuevo.

## 56. Probar sin R_TRIG: mantener IN1 presionado y observar que CV sube rápidamente. Luego

restaurar R_TRIG.

## 8. Ejercicios

- Cambiar PV a 50. Verificar que la alarma suena a las 50 piezas.

## - Agregar un indicador de "mitad de lote": OUT4 enciende cuando CV ≥ 10 (usando un

segundo CTU con PV=10 en paralelo, sin reset automático).
- [Desafío] Modificar el circuito para que el operario no pueda resetear mientras la alarma no

## haya sonado al menos 3 segundos. Pista: usar un TON de 3000ms habilitado por Q del

CTU, y el reset solo se activa cuando Q_TON=1 AND IN2=1.

# Ejemplo 5.2 — CTU con aviso de mitad de lote

## 1. Situación práctica

## Una línea de producción hace lotes de 20 piezas. Se necesitan dos indicaciones: cuando se completa la mitad del lote (10 piezas, OUT1 enciende brevemente como aviso) y cuando se

completa el lote (20 piezas, OUT2 activa la parada). Se usan dos CTU con el mismo sensor.

Pág. 50 | IEC 61131-3 FBD | ESP32 | RS-485 / Modbus RTU | v5 · 2026

## 2. FBD

┌──────┐ | ┌────────┐
│ IN1 | ├──┤ R_TRIG ├─────────────────────────────────────────────────────────┐
└──────┘ └────────┘ | │
CU ┌────────────┐Q | │
┌────────────────────────┤ CTU_A | ├──────────────── [OUT1] | (Aviso mitad)│
│ | │ | PV=10 | │ | │
│ ┌──────┐ | R ───►│ | │ | │
│ │ IN2 | ├──────────────┤ | │ | │
│ └──────┘ | └────────────┘ | │
│ | │
│ | CU ┌────────────┐Q | │
└──────────────────────┬─┤ CTU_B | ├─── [NOT] ──── [OUT1_gate] | │
│ │ | PV=20 | │ | (motor para cuando Q=1) | │
┌──────┐ | R ────┼►│ | │Q ──────────── [OUT2] | (Alarma lote) | │
│ IN2 | ├───────────────┘ └────────────┘ | │
└──────┘ | │
◄──────────────────────────────────────┘

(R_TRIG alimenta la entrada CU de AMBOS contadores simultáneamente)

CTU_A (PV=10): Q=1 en pieza 10 → OUT1 (aviso mitad de lote)
CTU_B (PV=20): Q=1 en pieza 20 → NOT Q → motor para; Q → OUT2 (alarma) IN2 resetea AMBOS contadores simultáneamente.

## 3. Tabla de estados

CV (piezas) | Q CTU_A
(PV=10)

## Q CTU_B

(PV=20) | OUT1 (aviso) | OUT2
(alarma) | Motor
0-9 | 0 | 0 | 0 | 0 | ON
10-19 | 1 | 0 | 1 | 0 | ON
20+ | 1 | 1 | 1 | 1 | OFF
Reset (IN2) | 0 | 0 | 0 | 0 | ON

## 4. Ejercicios

- Implementar y verificar que OUT1 enciende en la pieza 10 y sigue hasta el final del lote.

## - Agregar un tercer CTU con PV=5 que active un parpadeo (BLINK) en OUT3 como "alerta

temprana" de que el proceso está avanzando.
- [Desafío] Modificar para que OUT1 solo encienda entre las piezas 10 y 19 (no a partir de la 20). Pista: usar AND entre Q_CTU_A y NOT(Q_CTU_B).

# Ejemplo 5.3 — CTD: contador descendente para control de stock

## 1. Situación práctica

Un almacén tiene 50 unidades de un producto. Cada vez que se retira una unidad (sensor IN1), el

## contador descuenta. Cuando quedan 10 unidades (nivel mínimo), enciende una lámpara de

reposición (OUT1). Cuando llega stock nuevo, el operario presiona IN2 para recargar el contador a 50.

Pág. 51 | IEC 61131-3 FBD | ESP32 | RS-485 / Modbus RTU | v5 · 2026

## 2. El bloque CTD — diferencias con CTU

Aspecto | CTU | CTD
Conteo | Sube: 0 → PV | Baja: PV → 0
Entrada de pulso | CU: sube CV en 1 | CD: baja CV en 1
Carga inicial | R=1 → CV=0 (reinicia desde 0) | LD=1 → CV=PV (carga el valor preset)
Q activa cuando | CV ≥ PV (llegó al objetivo) | CV ≤ 0 (llegó a cero o menos)
Uso típico | Contar hasta llegar a un objetivo | Contar desde un máximo hasta cero

## 3. FBD

┌──────┐ | ┌────────┐ | CD ┌─────────────┐
│ IN1 | ├──┤ R_TRIG ├─────┤ | CTD | │Q ── [OUT1] | (Alarma stock bajo)
└──────┘ └────────┘ | │ | PV=50 | │
┌──────┐ | LD──►│ | │
│ IN2 | ├────────────────►│ | | │
└──────┘ | └─────────────┘

IN1: sensor de salida de producto (cada retiro = un pulso) IN2: carga de nuevo stock (LD=1 → CV vuelve a PV=50)

Pero necesitamos alarma cuando CV ≤ 10, no cuando CV ≤ 0.
El CTD activa Q cuando CV ≤ 0. Para detectar CV ≤ 10,
usamos un segundo CTU que cuenta retiros y activa alarma a los 40:

Solución alternativa con CTU (PV = 50 - 10 = 40):
┌──────┐ | ┌────────┐ | CU ┌─────────────┐Q
│ IN1 | ├──┤ R_TRIG ├─────┤ CTU PV=40 | ├──── [OUT1] | (Alarma: quedan 10)
└──────┘ └────────┘ | │ | │
┌──────┐ | R──►│ | │
│ IN2 | ├────────────────►│ | │
└──────┘ | └─────────────┘

Cuando CTU llega a 40 retiros → quedan 10 unidades → Q=1 → alarma. IN2 resetea el CTU (llega nuevo stock) → CV vuelve a 0 → alarma apaga.

## 4. Ladder

Rung 1: | | | [P IN1 ] | [CTU PV=40 Q M1] | |
Rung 2: | | | [ IN2 | ] | (R_CTU IN1 | ) | |
Rung 3: | | | [ M1 | ] | ( OUT1 | ) | | | (alarma)

✅ Compatibilidad: Level 1 — conversión FBD → Ladder perfecta

## 5. Tabla de estados

CV (retiros) | Stock real
restante | Q (CTU PV=40) | OUT1

## (alarma)

## Acción recomendada

0 | 50 | 0 | 0

## Normal: stock completo

20 | 30 | 0 | 0

## Normal: stock suficiente

Pág. 52 | IEC 61131-3 FBD | ESP32 | RS-485 / Modbus RTU | v5 · 2026
CV (retiros) | Stock real restante | Q (CTU PV=40) | OUT1 (alarma) | Acción recomendada
39 | 11 | 0 | 0 | Normal: stock suficiente
40 | 10 | 1 | 1 | ALARMA: reponer stock
45 | 5 | 1 | 1 | ALARMA: stock crítico
50 | 0 | 1 | 1 | ALARMA: sin stock
Reset (IN2) | 50 (nuevo stock) | 0 | 0 | Normal: reposición realizada

## 6. Ejercicios

- Modificar PV para stock inicial de 100 unidades con alarma a las 20 restantes. ¿Cuál es el PV del CTU? (Respuesta: PV = 100 - 20 = 80).
- Agregar una segunda alarma en OUT2 cuando el stock llega a 5 unidades (nivel crítico). Usar otro CTU con PV=45.

## - [Desafío] Implementar el CTD real: cargar CV=50 con IN2 (LD) y contar con CD. Conectar Q del CTD (CV≤0) a OUT2 como alarma de "sin stock". Comparar el comportamiento con

el CTU alternativo.

# Ejemplo 5.4 — Control de lote completo con cinta y señalización

## 1. Situación práctica

## Una línea de producción hace lotes de 20 piezas. Al completar el lote: la cinta para

automáticamente, suena una sirena (OUT2) y una lámpara parpadea (OUT3). El operario retira el lote y presiona reset (IN2). La cinta vuelve a arrancar automáticamente.

## 2. FBD completo

┌──────┐ | ┌────────┐ | CU ┌──────────┐Q
│ IN1 | ├──┤ R_TRIG ├─────┤ CTU PV=20├──────────────────────── [OUT2] | (Sirena)
└──────┘ └────────┘ | │ | │
┌──────┐ | R──►│ | │Q
│ IN2 | ├────────────────►│ | ├── EN ┌──────────┐Q
└──────┘ | └──────────┘ | │BLINK 500 ├─────── [OUT3] | (Parpadeo)
| │Q | └──────────┘
└── [NOT] ─────────────────── [OUT1] | (Motor
cinta)

Cuando CV < 20: Q=0 → NOT Q=1 → Motor ON, sirena OFF, parpadeo OFF. Cuando CV = 20: Q=1 → NOT Q=0 → Motor PARA, sirena ON, parpadeo ON. Operario presiona IN2: R=1 → CV=0 → Q=0 → Motor ON, alarmas OFF. Ciclo se repite automáticamente.

## 3. Prueba paso a paso

57. Cargar programa. RUN. OUT1=1 (cinta en marcha), OUT2=0, OUT3=0.
58. Activar IN1 20 veces. En la pieza 20: cinta para, sirena suena, lámpara parpadea.
59. Presionar IN2: todo vuelve al estado inicial, cinta arranca sola.

Pág. 53 | IEC 61131-3 FBD | ESP32 | RS-485 / Modbus RTU | v5 · 2026
60. Verificar que si se sigue presionando IN1 después de la pieza 20, la cinta sigue parada (Q sigue en 1 aunque CV suba más).

## 4. Ejercicios

- Cambiar PV a 10 y probar el sistema completo.

## - Agregar un indicador en OUT4 que encienda cuando el motor está corriendo (simplemente Q del NOT, o sea, NOT(Q_CTU)). ¿Es diferente de OUT1?

- [Desafío] Agregar un contador de lotes completados: cada vez que se presiona IN2 (reset),

## un segundo CTU cuenta un lote. Cuando se completan 5 lotes, encender OUT4 indicando

"fin de turno".

# Ejemplo 5.5 — Contadores en cascada: décimas y unidades

## 1. Situación práctica

Una línea industrial debe contar 100 piezas usando dos CTU en cascada: el primero cuenta de 0 a 10 (décimas), y al llegar a 10 resetea y envía un pulso al segundo. El segundo cuenta de 0 a 10 (decenas). Cuando el segundo llega a 10 (= 100 piezas totales), activa la alarma de lote.

## 2. FBD — Cascada de contadores

┌──────┐ | ┌────────┐ | CU ┌───────────────┐Q | CU ┌───────────────┐Q
│ IN1 | ├──┤ R_TRIG ├─────┤ CTU_1 PV=10 | ├───────┤ CTU_2 PV=10 | ├── [OUT1](100 piezas)
└──────┘ └────────┘ | │ | │ | │ | │
| │ | │Q | R──►│ | │
└───────────────┘ | └───────────────┘
│Q
└─────────────────────────────► R del CTU_1

(auto-reset: cuando CTU_1 llega a 10,
Q=1 → R=1 → CV vuelve a 0 → Q=0 → ciclo)

⚠ El auto-reset (Q → R del mismo bloque) funciona gracias al snapshot IEC 61131-3: Ciclo N: CU activo → CV sube a 10 → Q=1.
Ciclo N+1: Q=1 → R=1 → CV vuelve a 0 → Q=0. El pulso duró 1 ciclo (10ms).
Ese pulso de 10ms llega a CU del CTU_2 → CTU_2 cuenta 1.

IN2: resetea AMBOS contadores simultáneamente.

## 3. Tabla de estados simplificada

Piezas totales | CV CTU_1 | Q CTU_1 | CV CTU_2 | Q CTU_2 / OUT1
0 | 0 | 0 | 0 | 0
9 | 9 | 0 | 0 | 0
10 | 10→0 (reset) | 1 pulso | 1 | 0
19 | 9 | 0 | 1 | 0
20 | 10→0 (reset) | 1 pulso | 2 | 0
99 | 9 | 0 | 9 | 0
100 | 10→0 (reset) | 1 pulso | 10 | 1 → ALARMA

Pág. 54 | IEC 61131-3 FBD | ESP32 | RS-485 / Modbus RTU | v5 · 2026

## 4. Ejercicios

- Implementar y verificar la cascada. ¿Cuántos CTU se necesitarían para contar hasta 1000? ¿Y hasta 1 millón? - ¿Por qué el auto-reset del CTU_1 funciona correctamente con el modelo de snapshot? Si el PLC no tuviera snapshot, ¿qué problema habría? - [Desafío] Modificar para contar 500 piezas usando CTU_1 con PV=10 y CTU_2 con

PV=50. Verificar que la alarma suena exactamente en la pieza 500.

Pág. 55 | IEC 61131-3 FBD | ESP32 | RS-485 / Modbus RTU | v5 · 2026

# Capítulo 6 — Señales Analógicas

Hasta ahora trabajamos con señales digitales: 0 o 1, abierto o cerrado. Las señales analógicas

## son continuas: pueden tomar cualquier valor entre un mínimo y un máximo. El PLC-CORE-MDE

tiene una entrada analógica AI1 que lee señales de 0 a 10V DC y las convierte en un número de 0 a 4095 mediante su conversor ADC de 12 bits.

# La entrada analógica AI1 — Conceptos fundamentales
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
